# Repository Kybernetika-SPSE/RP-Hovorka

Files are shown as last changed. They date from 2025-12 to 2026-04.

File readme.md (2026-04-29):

# KYB Fotaoparát - Systém pro obsluhu kamery

## Zadání projektu
Cílem práce je návrh a realizace systému pro obsluhu
digitální kamery pomocí mikrokontroléru.

## Řešitelský tým
Vít Hovorka

## Vedoucí
Jiří Švihla

## Oponent
Pavel Jedlička

## Shrnutí projektu
Projekt „Fotaoparát" má za cíl navrhnout a realizovat řídicí systém pro digitální fotoaparát založený na mikrokontroléru ESP32‑P4. Práce kombinuje návrh hardware (schemata, PCB, periferie), mechanický návrh těla a vývoj firmware pro řízení kamery, paměti a uživatelského rozhraní.
## Fáze a plnění
## Termíny
| milník | termín |
| :--- | :--- |
| Nastudování dokumentací, návrh zapojení a design obalu| **30.12.2025** |
| Sestavení | **30.1.2026**  |
| Naprogramování operačního softwaru | **27.2. 2026** |
| Testování a tvora dokumentace | **30.03.2026** |
| Odevzdání ročníkové práce | **30.04.2026** |

[^1]: Změněno na základě požadavků

### Ganttův diagram postupu
```mermaid
gantt
    title Milníky projektu
    dateFormat  YYYY-MM-DD
    axisFormat  %d.%m.%Y
    section Studium a návrh
    Studovat dokumentace a návrh   :done, study, 2025-09-01, 2025-12-30
    section Sestavení prototypu
    Montáž prototypu               :build, 2026-01-01, 2026-01-30
    section Vývoj softwaru
    Implementace firmware          :dev, 2026-02-01, 2026-02-27
    section Testování a dokumentace
    Testování a tvorba dokumentace :test, 2026-03-01, 2026-03-30
    section Odevzdání a prezentace
    Finalizace a odevzdání         :deliver, 2026-04-01, 2026-04-30
```

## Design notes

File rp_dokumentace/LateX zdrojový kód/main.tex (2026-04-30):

\documentclass[12pt, a4paper, oneside]{report}             
\usepackage[czech]{babel}
\usepackage[utf8]{inputenc}  
\usepackage{graphicx} % balíček pro vkládání RASTROVÝCH grafických souborů (PNG apod.)
%\usepackage{epsfig} % balíčky pro vkládání VEKTOROVÝCH grafických souborů typu EPS
%\usepackage{float} % rozšířené možnosti umístění obrázků
%\usepackage{caption} % pro popisky obrázků, tabulek atd.
%\usepackage{tabularx} % rozšířené možnosti tabulek
%\usepackage{tabu} % jiný balík pro rozšířené možnosti tabulek
\usepackage{xcolor}
\usepackage{amsmath} % balíček pro pokročilou matematickou sazbu
\usepackage{pdfpages} % pro vkládání PDF souborů
%\usepackage{color} % pro možnost barevného textu
%\usepackage{fancybox} % umožňuje pokročilé rámečkování
%\usepackage{index} % nutno použít v případě tvorby rejstříku balíčkem makeindex
%\newindex{default}{idx}{ind}{Rejstřík} % zavádí rejstřík v případě použití balíku index
\usepackage{longtable}
\usepackage{array}
\usepackage[formats]{listings}  % Balíček pro sazbu zdrojových textů

\usepackage{anysize}
\marginsize{3.5cm}{1.5cm}{2.5cm}{3cm} % Nastavení okrajů (volitelné)

\usepackage{titlesec}  %přetypuje nadpisy všech úrovní na bezpatkové, tučné a dané velikosti

\titleformat{\chapter}[hang]{\sffamily\fontsize{16pt}{20pt}\bfseries}{\thechapter}{1em}{}
\titlespacing*{\chapter}{0pt}{20pt}{10pt}
\titleformat{\section}[hang]{\sffamily\fontsize{14pt}{16pt}\bfseries}{\thesection}{1em}{}
\titlespacing*{\section}{0pt}{20pt}{10pt}
\titleformat{\subsection}[hang]{\sffamily\fontsize{14pt}{18pt}\bfseries}{\thesubsection}{1em}{}
\titlespacing*{\subsection}{0pt}{20pt}{10pt}
\titleformat{\subsubsection}[hang]{\sffamily\fontsize{14pt}{18pt}\bfseries}{\thesubsubsection}{1em}{}
\titlespacing*{\subsubsection}{0pt}{20pt}{10pt}

\usepackage{setspace}
\setstretch{1.3} % Nastaví 1,3násobné řádkování

\frenchspacing % za větou bude mezislovní mezera (v anglických textech je mezera za větou delší)
\widowpenalty=1000 % "síla" zákazu vdov (= jeden řádek odstavce na konci stránky)
\clubpenalty=1000 % "síla" zákazu sirotků (= jeden řádek/slovo odstavce samostatně na začátku stránky)
\brokenpenalty=1000 % "síla" zákazu zlomu stránky za řádkem, který má na konci rozdělené slovo

\pagenumbering{arabic} % číslování stránek arabskými číslicemi
\usepackage{fancyhdr} % Načte balíček pro pokročilé úpravy záhlaví a zápatí.
\pagestyle{fancy} % Nastavení stylu stránek na 'fancy'
\fancyhf{} % Vymazání aktuálního nastavení záhlaví a zápatí
\fancyfoot[R]{\thepage} % Nastavení čísel stránek vpravo dole (R - right)
\renewcommand{\headrulewidth}{0pt}
\renewcommand{\footrulewidth}{0pt}
\fancypagestyle{plain}{%
  \fancyhf{}
  \fancyfoot[R]{\thepage}
  \renewcommand{\headrulewidth}{0pt}
  \renewcommand{\footrulewidth}{0pt}
}
\parindent=0pt % odsazení 1. řádku odstavce
\parskip=12pt   % mezera mezi odstavci
\usepackage[breaklinks=true,hypertexnames=false]{hyperref}  % Balíček 'hyperref' pro sazbu hypertextových odkazů. Hypertextové odkazy mohou obsahovat zalomení řádku. Názvy hypertext. odkazů budou tvořeny nezávisle na názvech TeXu.
\hypersetup{ % popisky v pdf souboru
  pdftitle={Název studentské práce},    	% Pole 'Document Title'
  pdfauthor={Autor studentské práce},   	% Pole 'Author'
  pdfsubject={Typ práce}, 						  	% Pole 'Subject'
  pdfkeywords={Klíčová slova}           	% Pole 'Keywords'
}

%%%%%%%%%%%%%%%%%%%%%%%%%%%%%%%%%%%%%%%%%%%%%%%%%%%%%%%%%%%%%%%%%%%%%%%
%%%%%%%%%%%       Začátek dokumentu               %%%%%%%%%%%%%%%%%%%%%
%%%%%%%%%%%%%%%%%%%%%%%%%%%%%%%%%%%%%%%%%%%%%%%%%%%%%%%%%%%%%%%%%%%%%%%
\begin{document}
\thispagestyle{empty} %vypnutí číslování stránek

%% TITULNÍ STRANA %%%%%%%%%%%%%%%%%%%%%%%%%%%%%%%%%%%%%%%%%%%%%%%%%%%%%%%%%%%%%%
\begin{center}
  \begin{minipage}{3cm}
    
  \end{minipage}
  \hfill
  \begin{minipage}{0.7\textwidth}
    \centering
    {\Large Vyšší odborná škola\\
    a Střední průmyslová škola elektrotechnická\\
    Plzeň, Koterovská 85\\ }
  \end{minipage}
  
  \vspace{2cm}
  %% VYBERTE TYP PRÁCE %%%%%%%%%%%%%%%%%%%%%%%%%%
  %%{\Large \textbf{DLOUHODOBÁ MATURITNÍ PRÁCE S~OBHAJOBOU}\\ }
  {\Large \textbf{ROČNÍKOVÁ PRÁCE}\\ }
  %%%%%%%%%%%%%%%%%%%%%%%%%%%%%%%%%%%%%%%%%%%%%%%
  
  \vspace{2.5cm}
  {\large Téma: \\ }
  \vspace{0.25cm}
  %% PŘEPIŠTE NÁZEV PRÁCE %%%%%%%%%%%%%%%%%%%%%%%%%%%
  {\LARGE \textbf{Fotaoparát - Systém pro obsluhu kamery}}  
  %%%%%%%%%%%%%%%%%%%%%%%%%%%%%%%%%%%
  
  \vfill
\end{center}
\begin{tabular}{{p{4.5cm} p{12cm}}}
  {\Large \textbf{Autor práce:}} & \Large{Vít Hovorka}\\
  {\Large \textbf{Třída:}} & \Large{3.L}\\ 
  {\Large \textbf{Vedoucí práce:}} & \Large{Jiří Švihla} \\ 
  {\Large \textbf{Dne:}} & \Large{30.4.2026} \\ 
  {\Large \textbf{Hodnocení:}} &  \\ 
\end{tabular}
%% Vložení zadání %%%%%%%%%%%%%%%%%%%%%%%%%%%%%%%%%%%%%%%%%%%%%%%%%%%%%%%%%%%%
\newpage
\thispagestyle{empty}
\includepdf{pdf/Zadani-Hovorka.pdf}% název souboru nesmí obsahovat mezery!
%% NEBO lze vytvořit prázdný list příkazem ze šablony

%\newpage   % při dvojstranném tisku se přidá prázdná stránka

%%%%%%%%%%%% Anotace a poděkování %%%%%%%%%%%%%%%%%%%%%%%%%%%%%%%%%%%%%%%%%%%%%%
\newpage
\chapter*{Anotace} \indent
\thispagestyle{empty}

Tato ročníková práce se zabývá návrhem a prototypovou realizací řídicího systému pro mikrokontrolérovou kameru založenou na platformě \texttt{ESP32-P4}. Práce pokrývá výběr a návrh součástek, konstrukci a rozvržení desky plošných spojů, návrh napájecích větví a rozhraní pro kameru, displej a objektiv, a implementaci základního firmware pro pořizování, zpracování a ukládání snímků. Pozornost je věnována navrhování vysokorychlostních rozhraní (QSPI, MIPI/CSI), integritě signálu a spolehlivému napájení včetně řízení objektivu Canon EF. Výstupem je dokumentovaný návrh desky, zapojení a ukázkový firmware umožňující základní oživení a testování hardwaru.
\vfill

Prohlašuji, že jsem tuto práci vypracoval samostatně a použil literárních pramenů a~\mbox{informací}, které cituji a uvádím v seznamu použité literatury a zdrojů informací.

Prohlašuji, že jsem nástroje UI využil v souladu s principy akademické integrity a že na využití těchto nástrojů v práci vhodným způsobem odkazuji.

Souhlasím s využitím mé práce učiteli VOŠ a SPŠE Plzeň k výuce.

\vspace{1cm}

V Plzni dne 30. 4. 2026 \hfill Podpis: ..........................

%%%%%%%%%%%% Obsah práce ... je generován AUTOMATICKY %%%%%%%%%%%%
\newpage
\tableofcontents
\thispagestyle{empty}

%%%%%%%%%%%% Seznam zkratek %%%%%%%%%%%%%%%%%%%%%%%%%%%%%%%%%%%%%%%%%%%%%%
\newpage
\chapter*{Seznam zkratek}
\addcontentsline{toc}{chapter}{Seznam zkratek}
\begingroup
\setlength{\tabcolsep}{6pt}
\renewcommand{\arraystretch}{1.4}
\begin{longtable}{>{\raggedright\arraybackslash}p{2.6cm} >{\raggedright\arraybackslash}p{6.3cm} >{\raggedright\arraybackslash}p{5.2cm}}

\textbf{Zkratka} & \textbf{Anglicky} & \textbf{Česky} \\
\endfirsthead
\textbf{Zkratka} & \textbf{Anglicky} & \textbf{Česky} \\
\endhead
ADC & Analog-to-digital converter & analogově-digitální převodník \\
AF & Autofocus & automatické ostření \\
CSI & Camera Serial Interface & kamerové sériové rozhraní \\
DRC & Design Rules Check & kontrola pravidel návrhu \\
DSI & Display Serial Interface & zobrazovací sériové rozhraní \\
DTR & Double Transfer Rate & přenos na obou hranách hodinového signálu \\
ERC & Electrical Rules Check & kontrola elektrických pravidel \\
ESP-IDF & Espressif IoT Development Framework & vývojový rámec pro čipy ESP od společnosti Espressif \\
ESD & Electrostatic discharge & elektrostatický výboj \\
GPIO & General-purpose input/output & univerzální vstup/výstup \\
HP & High Power & vysoký výkon\\
I2C & Inter-Integrated Circuit & dvouvodičová sériová sběrnice \\
NOR & NOR flash & typ nevolatilní flash paměti \\
ISO & International Organization for Standardization & citlivost podle fotografické terminologie \\
LP & Low Power & Nízký výkon\\
MILC & Mirrorless interchangeable-lens camera & bezzrcadlový fotoaparát s výměnnými objektivy \\
MCU & Microcontroller unit & mikrokontrolér \\
MIPI & Mobile Industry Processor Interface & standard mobilního rozhraní pro periférie \\
PCB & Printed circuit board & plošný spoj \\
QSPI & Quad Serial Peripheral Interface & čtyřlinkové sériové periferní rozhraní \\
SD & Secure Digital & paměťová karta Secure Digital \\
SPI & Serial Peripheral Interface & sériové periferní rozhraní \\
USB & Universal Serial Bus & univerzální sériová sběrnice \\
\caption{Seznam zkratek}
\end{longtable}
\endgroup

%--------------------------------------------------------
%|         Zde začíná SAMOTNÁ PRÁCE (text)              |
%--------------------------------------------------------
\newpage

\chapter*{Úvod}
\addcontentsline{toc}{chapter}{Úvod}
Už asi dva roky se pokouším být aktivním fotografem, s tím že jsem začínal na analogovém fotoaparátu a snažil se naučit souvislosti mezi hodnotami expozičního času, clony a ISO. Vždy mě bavilo zkoumat do hloubky jak a proč takové věci fungují a hledat si svou vlastní „cestu trním"~kde metodou pokus omyl šlechtím své dovednosti. Proto mi sestavení svého vlastního fotoaparátu přišlo jako dobrá cesta jak naučit nejen elektrotechniku a programovaní, ale i jak poznat technologii digitální fotografie do hloubky.

\chapter{Cíle a požadavky}
\section{Požadavky na mechanické konstrukční řešení}
Tento projekt by měl v ideálním případě alespoň připomínat MILC kameru. Výrobek, dále označovaný jako fotaoparát, by měl být tedy:
\begin{itemize}
    \item svými rozměry a tvarem podobný dnešním digitálním fotoaparátům,
    \item jednoduše nositelný a ovladatelný,
    \item kompatibilní s objektivy řady Canon EF. Toto rozhodnutí má jak objektivní tak i subjektivní opodstatnění. Subjektivní rovinou zde je fakt že už několika disponuji. V objektivní rovině je fakt že komunikační protokoly jsou už komunitou zmapovány (Magic Lantern\footnote{Magic Lantern firmware, dostupné z: https://www.magiclantern.fm}).
\end{itemize}
\section{Požadavky na elektrotechnické řešení}
Součástí vývoje projektu je i návrh základní desky pro mikročip \texttt{ESP32-P4} a jeho periférií. Základní deska tedy:
\begin{itemize}
    \item bude mít na starost napájení jak hlavního čipu, tak veškerých periférií. Napájení bude zajištěno jedním akumulátorem,
    \item obstará všechny konektory pro zapojení periférií. Bude tedy možné případné periferie vyměnit za lepší za předpokladu kompatibility z hlediska počtu vývodů (pinů) na konektoru a prostoru v těle Fotaoparátu,
    \item bude jednoduše programovatelná pomocí USB-C vstupu. Fotaoparát bude open-source výrobek podporující a vyzývající k úpravám podle uživatele, kde open-source znamená výrobek s veřejně dostupným zdrojovým kódem,
    \item bude navrhována s ohledem na elektromagnetické rušení signálů a možnosti ztráty dat kvůli délkové asymetrii cest a design se tedy bude snažit toto rušení a ztrátu minimalizovat.
    \item bude navrhována s ohledem na prostor a konstrukční provedení těla fotaoparátu. Bude tedy dostatečně skladná a vývody na periferie budou vhodně umístěny.
\end{itemize}
\section{Požadavky na softwarové řešení}
Výrobek bude nakonec oživen firmwarem vlastní výroby. Software bude mít pevně dané funkce jako např. nastavení hodnot ISO, clony a rychlosti závěrky. Zároveň by měl mít jednoduše přizpůsobitelné uživatelské rozhraní a možnost přidávat další uživatelské funkce.
\chapter{Použité nástroje}
\section{KiCAD 9.0}
Pro návrh samotné základní desky Fotaoparátu jsem zvolil software KiCAD 9.0. Jedná se o open-source software určený pro návrh elektronických schémat a plošných spojů. Samotný program totiž ukrývá tři hlavní podprogramy: Schematic editor, PCB editor a Gerber viewer.

Schematic editor umožňuje uživateli nakreslit elektrické schéma a dokonce i do jisté míry simulovat jednoduché elektrické obvody. Dále KiCAD hned po instalaci disponuje velmi rozmanitou knihovnou součástek, pouzder a datasheetů (technická dokumentace jednotlivých součástek). Stačí si tedy součástky vybrat, pomocí nástroje „kreslit vodiče" je propojit, nebo pomocí nástroje „označení sítě" jim přiřadit stejnou síť. Je zde také možnost využít nástroj ERC (electrical rules check - kontrola elektrických pravidel), ten slouží k odhalení chyb v zapojení vývodů.
\begin{figure}
    \centering
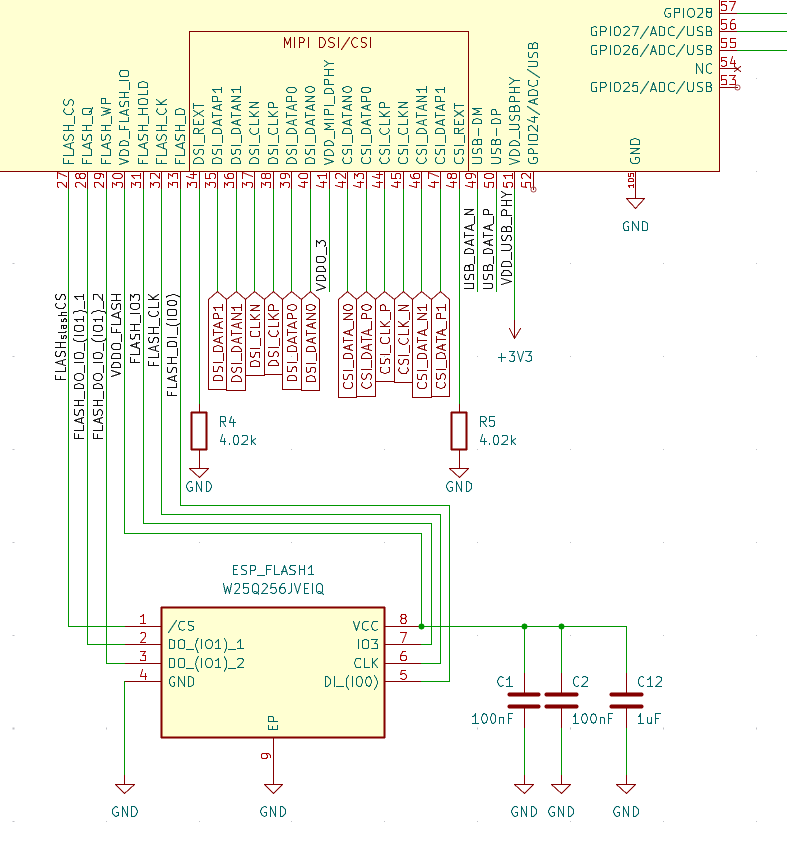
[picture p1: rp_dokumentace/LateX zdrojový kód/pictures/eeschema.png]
    
    \caption{Ukázka programu schematic editor \textit{Zdroj: [vlastní]}}
    \label{fig:schematicsmrdito}
\end{figure}

PCB editor slouží k přímému návrhu plošného spoje. Obvyklý postup při práci s KiCADem je nakreslení elektronického schématu, přiřazení pouzder, načtení těchto dat do PCB editoru a zde rozmístit součástky a routovat cesty spojů. Disponuje také možností nastavení konstrukčních vlastností desky (počet vrstev, tloušťka jednotlivých vrstev, základní tloušťka spojů, velikost prokovených otvorů, minimální požadovaná vzdálenost mezi cestami...).
Pro kontrolu designových chyb na desce pak slouží nástroj DRC (design rules check - kontrola pravidel designu).
\begin{figure}
    \centering
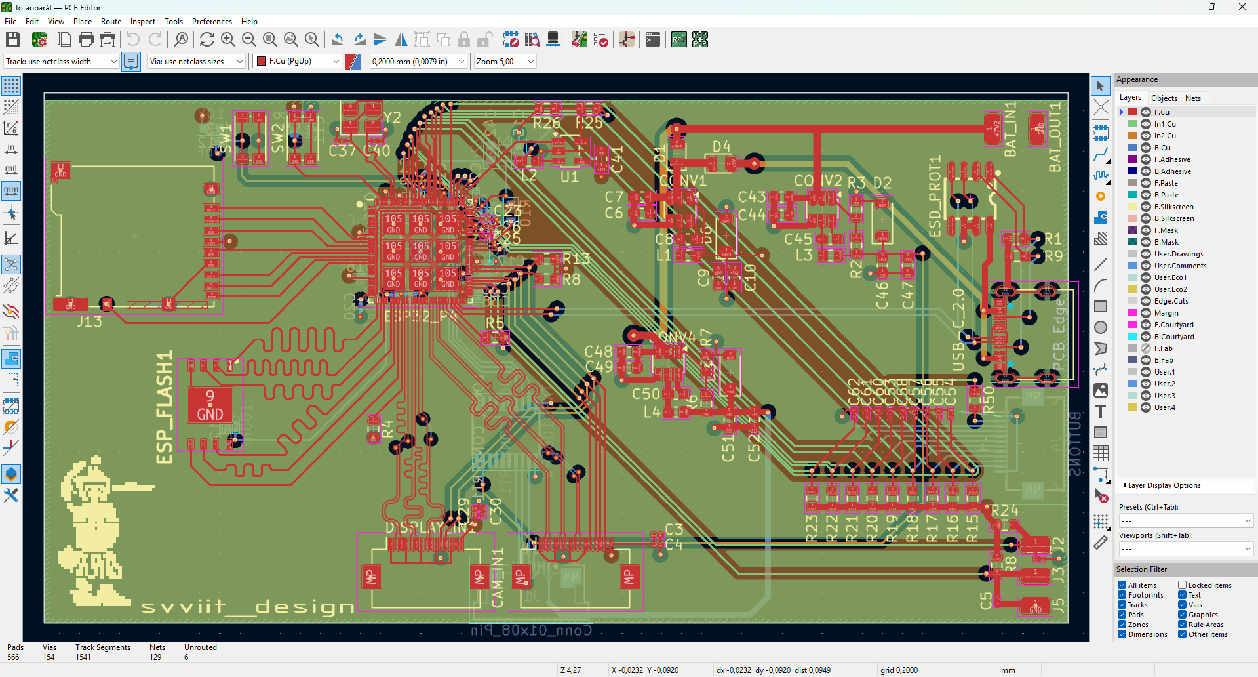
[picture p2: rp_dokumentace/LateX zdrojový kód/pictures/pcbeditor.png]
    
    \caption{Ukázka programu PCB editor \textit{Zdroj: [vlastní]}}
    \label{fig:pcbsmrdito}
\end{figure}

Jako poslední podstatná část programu KiCAD je gerber viewer. Ten slouží k exportu geberových dat pro výrobu desky.

\section{Visual Studio Code}
Visual Studio Code (zkráceně VS Code nebo VS) je bezplatné moderní vývojové prostředí. Díky velkému množství rozšíření, která lze instalovat přímo v programu, a podpoře hlavních operačních systémů (Windows, Linux a macOS) si získalo značnou oblibu mezi programátory.

\begin{figure}
    \centering
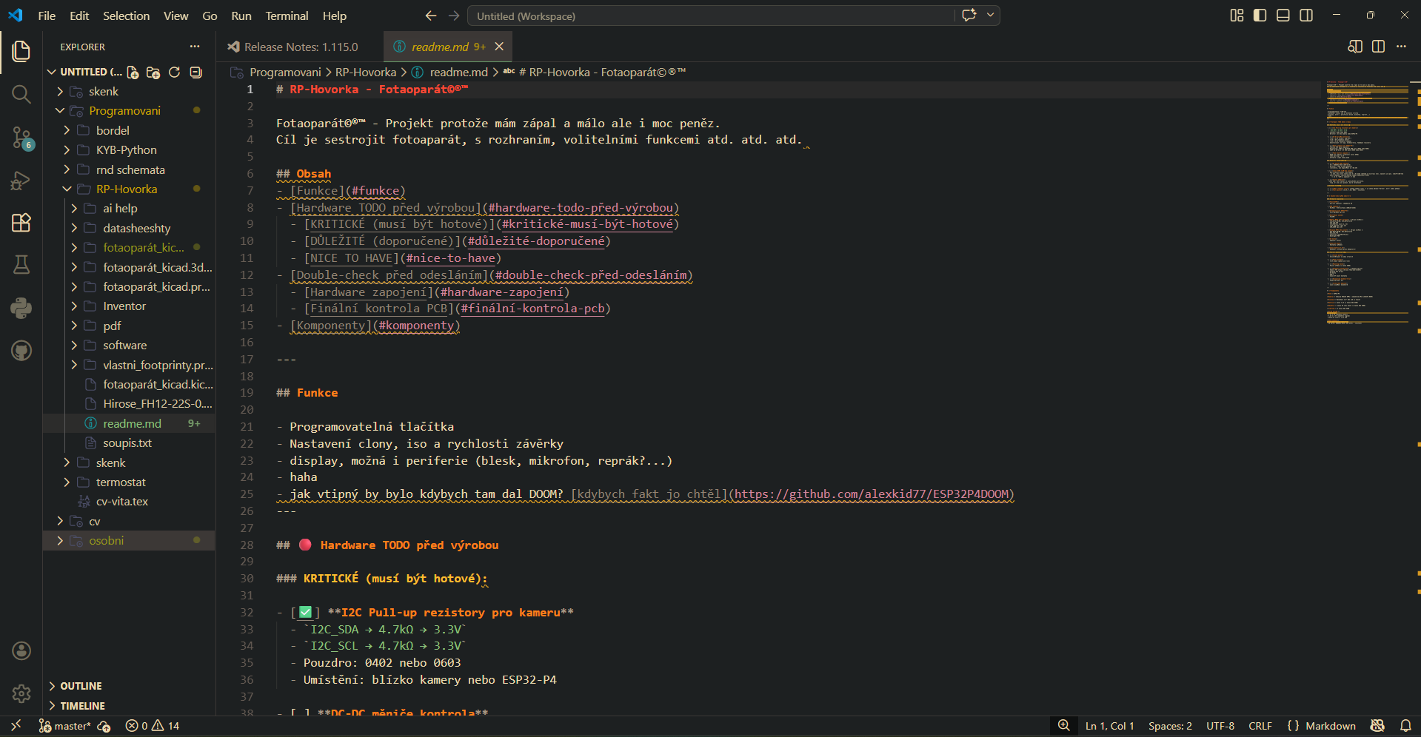
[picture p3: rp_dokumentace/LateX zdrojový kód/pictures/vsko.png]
    
    \caption{Ukázka programu Visual Studio Code \textit{[Zdroj: Vlastní]}}
    \label{fig:vsko}
\end{figure}

Mezi jeho hlavní funkce patří podpora verzovacích systémů jako např. Git, zvýraznění syntaxe (např. závorkové páry), našeptávání kódu, integrovaný terminál a debugger.

V mé práci jsem VS používal zejména pro jednoduché commitování. Dále jsem v něm používal umělou inteligenci pomocí které jsem napsal část firmwaru. 
\chapter{Vybrané komponenty}
\section{MCU}
Kvůli vysoké výpočetní náročnosti zpracování dat, která představuje jediný snímek o rozlišení 8 Mpx, bylo nutné zvolit jeden z nejvýkonnějších mikrokontrolérů dostupných v době realizace projektu — \texttt{ESP32-P4}. Jedná se o moderní MCU navržené s důrazem na vysoký výpočetní výkon, multimediální zpracování a efektivní práci s periferiemi\cite{esp32p4_ds}.

\texttt{ESP32-P4} je vybaven vícejádrovou architekturou, která umožňuje paralelní zpracování úloh. V tomto MCU se nacházzejí dva procesory -- jednojádrový a pomalejší LP a dvoujádrový rychlejší HP. Oba procesory jsou postaveny na 32-bitové architektuře. 

Low power procesor má nejvyšší rychlost taktu 40 MHz. Je narvžený pro zastoupení HP obvodů při sleep režimu, jelikož i při deep--sleep reimu je tento procesor a jeho pamět aktivní. Zároveň má však přístup i do HP paměti. 

High Power procesor má nejvyšší rychlost taktu 360 Mhz Dále disponuje hardwarovou akcelerací pro vybrané operace. Jeho paměti zahrnují:
\begin{itemize}
    \item 16 MB SRAM
    \item 128 kB ROM pro HP obvody
    \item 768 kB HP L2mem
    \item 16 kB ROM pro LP obvody
    \item 8 kB systémové SPM
    \item Více vyoskorychlostními externími paměťovými rozhraními
    \item Dvouúrovňovou vysokorychlotní cache
\end{itemize} 

Čip také zahruje podporou vysokorychlostních rozhraní, jako např. CSI, DSI a QSPI, která umožňují efektivní přenos velkého množství dat.

\section{Flash paměť}
Další důležitou součástí návrhu je externí flash paměť. Mikrokontrolér \texttt{ESP32-P4} totiž nedisponuje dostatečně velkou interní pamětí pro uložení uživatelského kódu, a proto je nutné využít externí úložiště.

V tomto projektu byla zvolena paměť \texttt{W25Q256JV-DTR} od společnosti Winbond. Jedná se o sériovou NOR flash paměť s kapacitou 256 Mbit (32 MB), která slouží pro ukládání firmwaru, konfiguračních dat a případně i dočasných obrazových dat.

Paměť komunikuje s mikrokontrolérem prostřednictvím rozhraní SPI, respektive jeho rozšířené varianty QSPI, která umožňuje paralelní přenos dat po více datových linkách. Díky tomu lze dosáhnout výrazně vyšších přenosových rychlostí oproti standardnímu SPI, což je zásadní zejména při práci s obrazovými snímky.

Označení DTR (Double Transfer Rate) znamená, že data jsou přenášena na obou hranách hodinového signálu, čímž dochází k efektivnímu zdvojnásobení propustnosti bez nutnosti zvyšování pracovní frekvence. Tato vlastnost přispívá ke zvýšení celkového výkonu systému při čtení i zápisu dat.

Paměť je organizována do sektorů, což umožňuje efektivní mazání a zápis po blocích. Zároveň podporuje mechanismy ochrany vybraných oblastí proti zápisu, což je výhodné například pro zabezpečení kritických částí firmwaru.
\section{Kamerový modul}
Další klíčovou komponentou je kamerový modul Arducam \texttt{IMX219} s rozlišením 8 Mpx. Tento modul byl zvolen nejen s ohledem na příznivý poměr ceny a výkonu, ale také díky své kompatibilitě a vhodnosti pro použití s mikrokontrolérem \texttt{ESP32-P4}.
\begin{figure}
    \centering
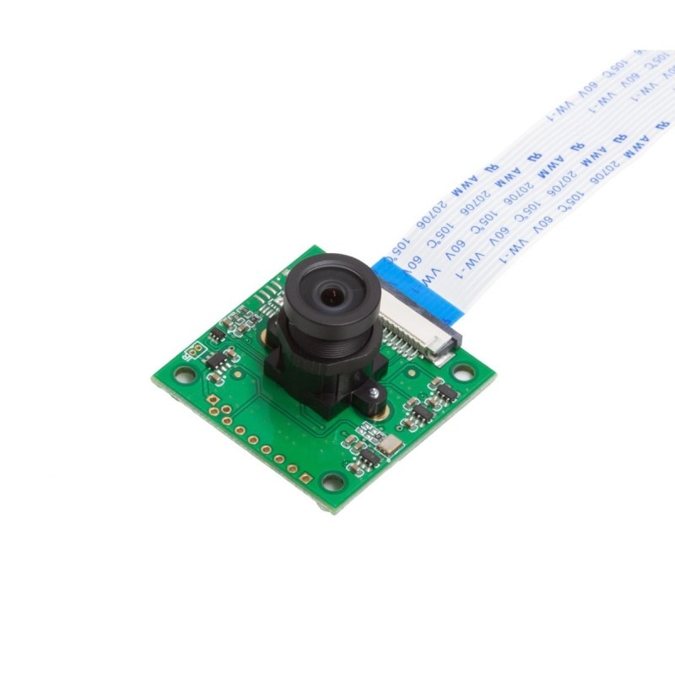
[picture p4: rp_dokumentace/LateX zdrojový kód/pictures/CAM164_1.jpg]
    
    \caption{Vybraný kamerový modul Arducam IMX219 \textit{[Zdroj: rpishop.cz]}}
    \label{fig:arducam}
\end{figure}

Zde je klíčové rozhraní DSI/CSI, které umožňuje vysokorychlostní přenos obrazových dat mezi kamerovým modulem, případně displejem, a samotným mikrokontrolérem. Využití tohoto rozhraní je zásadní zejména kvůli vyšším přenosovým rychlostem. Pokud bychom zvolili jiný postup, vyžadovalo by to desítky GPIO pinů, které prostě na MCU nemáme, a navíc by to bylo velmi náročné na synchronizaci a zpracování dat.

Samotný snímač \texttt{IMX219} nabízí dostatečné rozlišení pro zamýšlenou aplikaci a zároveň podporuje různé režimy výstupu, což umožňuje optimalizovat kompromis mezi kvalitou obrazu a objemem přenášených dat. V jednoduchosti můžeme poté přímo ve Fotaoparátu nastavovat rozlišení výstupního snímku.

Výhodou modulu Arducam je také jeho široká podpora a dostupná dokumentace, což usnadňuje jeho integraci do návrhu jak na hardwarové, tak i softwarové úrovni.

\section{Display}
Pro zobrazovací jednotku jsem zvolil 2,8"~LCD modul od společnosti Waveshare, a to především díky jeho DSI rozhraní, které je podporováno mikrokontrolérem ESP32-P4. Toto rozhraní umožňuje efektivní a rychlou komunikaci mezi řídicí jednotkou a displejem.
\begin{figure}
    \centering
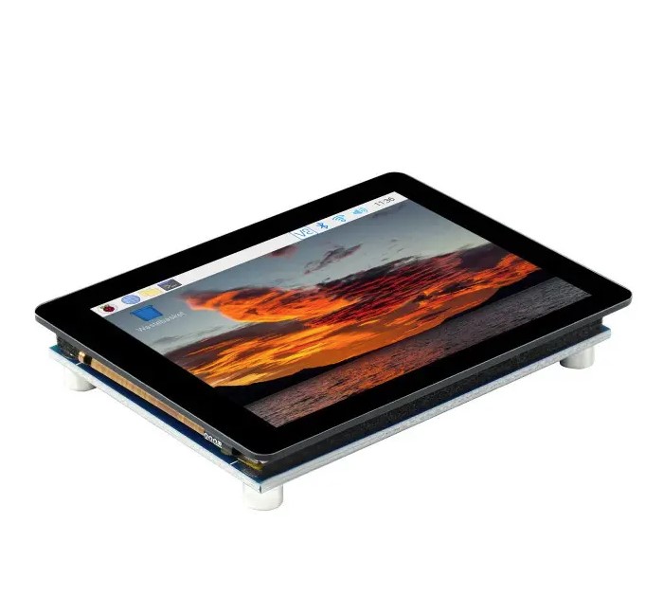
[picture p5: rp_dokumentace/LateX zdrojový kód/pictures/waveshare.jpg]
    
    \caption{Vybraný 2,8"~LCD modul od společnosti Waveshare \textit{[Zdroj: rpishop.cz]}}
    \label{fig:waveshare}
\end{figure}

Dalším důvodem výběru tohoto konkrétního displeje byla jeho kompatibilita s mechanickou konstrukcí zařízení. Pro zjednodušení návrhu jsem se rozhodl využít tělo a vybrané periferie fotoaparátu Canon 550D. Pro účely této kapitoly postačí uvést, že původní displej z modelu 550D není vhodné použít, jelikož k němu není veřejně dostupná dostatečná technická dokumentace. Zároveň má však velmi podobné rozměry jako zvolený Waveshare modul, což usnadňuje jeho náhradu bez nutnosti zásadních mechanických úprav.

\section{Konektor pro SD kartu}

Pro ukládání dat bude použit konektor pro SD kartu, což představuje standardní řešení úložiště u digitálních fotoaparátů. SD karty jsou kompaktní, široce rozšířené a snadno dostupné externí médium, které nabízí dostatečné přenosové rychlosti pro zamýšlenou aplikaci. Oproti tomu běžné USB flash disky nejsou pro tento typ zařízení tak vhodné, a to jak z hlediska rozměrů, tak i způsobu připojení.

Alternativou by mohlo být použití paměťových karet typu CompactFlash. Tyto karty sice teoreticky dosahují vyšších přenosových rychlostí, mimo jiné díky většímu počtu pinů, avšak jejich nevýhodou je vyšší pořizovací cena. Dalším omezením je skutečnost, že konektory pro CompactFlash karty jsou v současnosti obtížně dostupné a často vyžadují použití redukce. Z těchto důvodů nebylo toto řešení dále uvažováno.
\section{Konektor pro komunikaci s počítačem.}
Pro nahrávání firmwaru je na desce navržen USB-C konektor, který slouží nejen pro samotné programování mikrokontroléru, ale také pro jeho napájení během vývoje a testování. Toto řešení výrazně zjednodušuje proces nasazení firmwaru, protože není nutné využívat externí programátor.
\chapter{Podrobné zapojení na desce}
\section{MCU}
Středem celého návrhu je mikrokontrolér ESP32-P4, osazený jako hlavní výpočetní a řídicí prvek.
\begin{figure}
    \centering
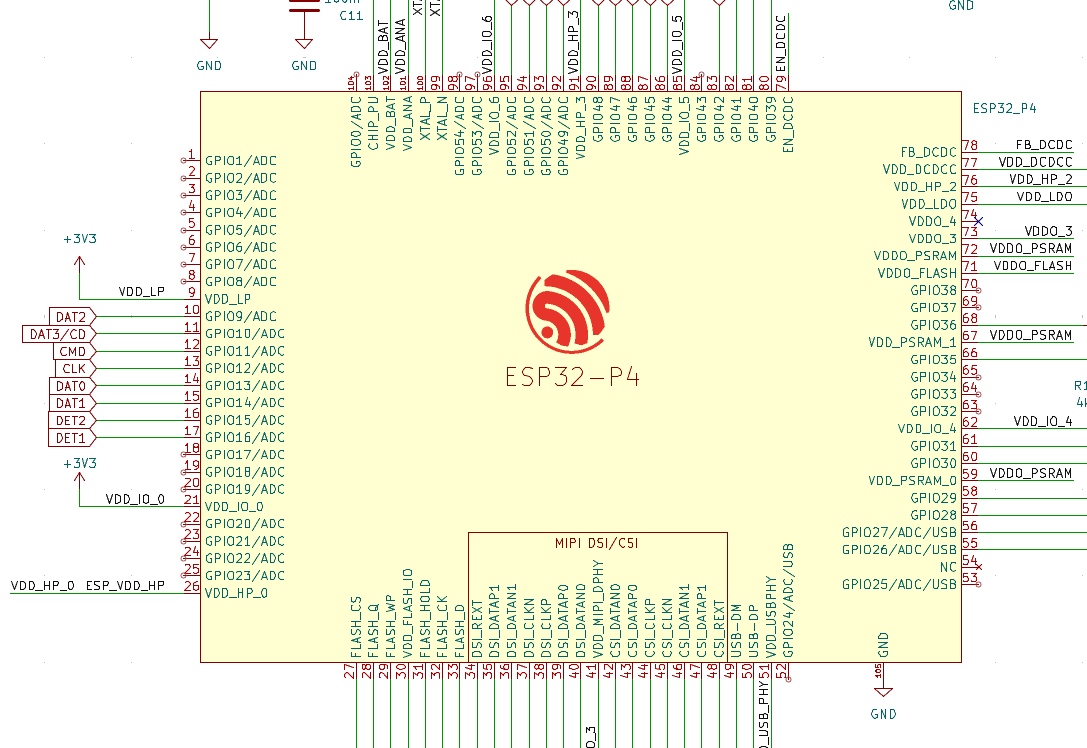
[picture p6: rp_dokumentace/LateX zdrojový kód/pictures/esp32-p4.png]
    
    \caption{ESP32-P4 v eschématu \textit{[Zdroj: Vlastní]}}
    \label{fig:esp32p4}
\end{figure}

Sám o sobě ale být použit nemůže. Pro jeho ideální funkci je potřeba externí flash pamět, externí krystal a externí buck converter na 1,1 V pro napájení high power pinů.

\subsection{Napájení interní SRAM paměti}
Napájení interních paměťových a pomocných bloků MCU je řešeno samostatně.\cite{local_kicad,esp32p4_trm}.

Pro napájení HP pinů je použit buck converter \texttt{TLV62569DBV}, který je nastaven na výstupní napětí 1,1 V, viz obrázek \ref{fig:hpbuck}.

\subsection{BOOT strapping a I2C}
\begin{figure}
    \centering
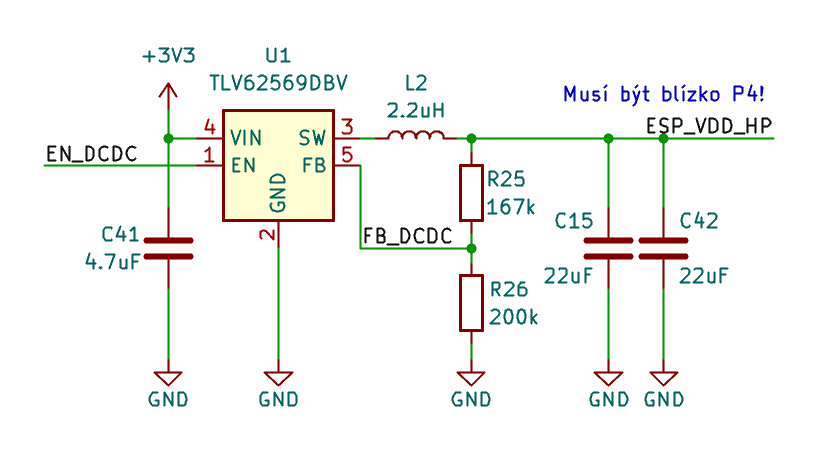
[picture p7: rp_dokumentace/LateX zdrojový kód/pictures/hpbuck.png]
    
    \caption{Schména zapojení měniče pro napájení HP pinů \textit{[Zdroj: Vlastní]}}
    \label{fig:hpbuck}
\end{figure}
Programování zařízení je v tomto projektu navrženo pouze přes USB. Mikrokontrolér sice obecně umožňuje i programování přes UART, tato možnost však v daném návrhu není využita. Pro vstup do programovacího režimu je osazeno tlačítko SW1, připojené k GPIO 35.  Strapping piny se čtou během bootování a určují spouštěcí režim MCU. Tlačítko S1 slouží k aktivaci Joint Download Boot módu pro nahrávání firmwaru — při jeho stisku během startu se MCU spustí v režimu, který umožňuje download nového kódu přes USB. Podrobněji jsou bootovací režimy a jejich konfigurace strapping pinů uvedeny v tabulce~\ref{tab:boot_modes}.

\begin{table}[h]
\centering
\begin{tabular}{|l|c|c|c|c|}
\hline
\textbf{Boot Mode} & \textbf{GPIO35} & \textbf{GPIO36} & \textbf{GPIO37} & \textbf{GPIO38} \\
\hline
SPI Boot mode (default)\textsuperscript{1} & 1 & x & x & x \\
\hline
Joint Download Boot mode\textsuperscript{2} & 0 & 1 & x & x \\
\hline
SPI Download Boot mode\textsuperscript{3} & 0 & 0 & 0 & 1 \\
\hline
Invalid Combination\textsuperscript{4} & 0 & 0 & 0 & 0 \\
\hline
\end{tabular}
\caption{BOOT režimy dle kombinace strapping pinů ESP32-P4 \textit{[Zdroj: \cite{esp32p4_trm}]}}
\label{tab:boot_modes}
\end{table}
\begin{figure}
    \centering
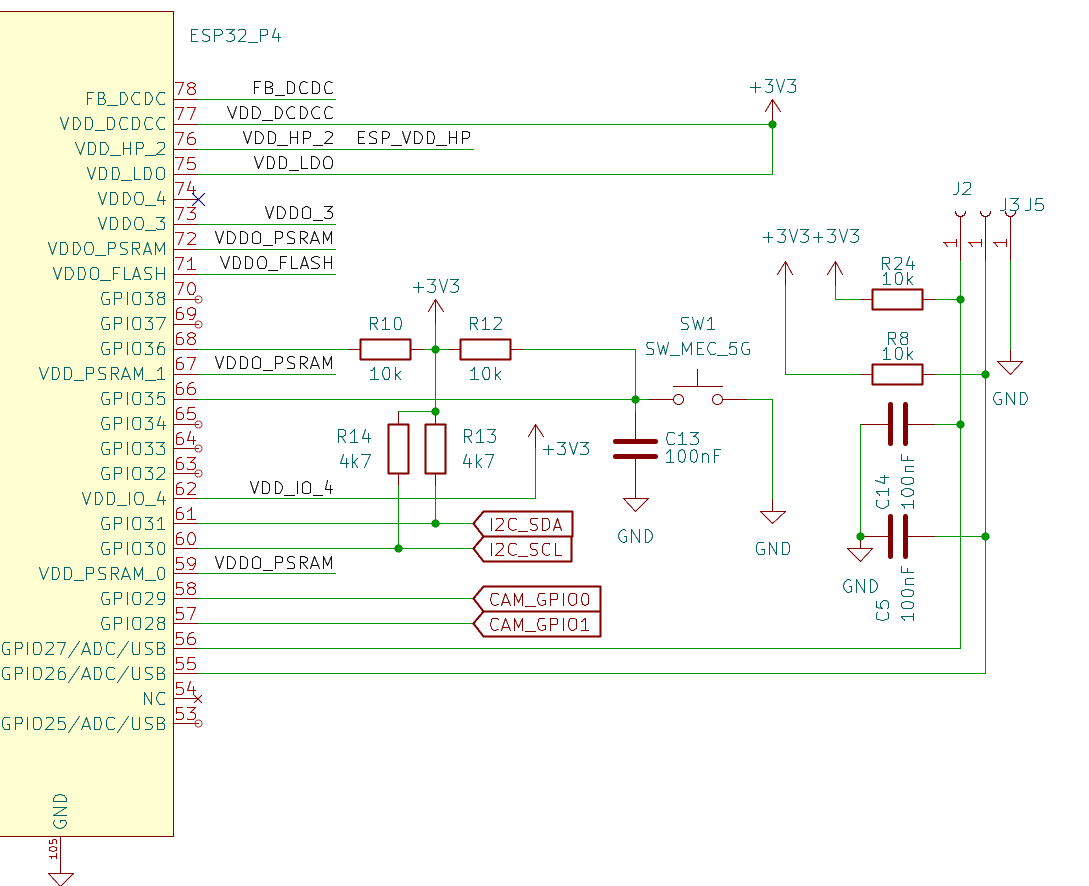
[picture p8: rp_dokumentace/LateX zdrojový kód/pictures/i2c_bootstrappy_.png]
    
    \caption{Zapojení kolem ESP32-P4 popsané v této sekci: I2C pull-upy, reset a startovací vazby. \textit{[Zdroj: Vlastní]}}
    \label{fig:i2c_bootstrappy}
\end{figure}

Na obrázku~\ref{fig:i2c_bootstrappy} je zachycena pravá část MCU, kde se nachází BOOT strapping piny (GPIO 35--38)~\cite{esp32p4_trm}, interní regulátor pro napájení Flash a SRAM pamětí (\texttt{VDD\_LDO}).

Dále je na obrázku~\ref{fig:i2c_bootstrappy} zachyceno I2C rozhraní, připojené k pinům GPIO 30 a 31. Kvůli designu samotné sběrnice, kde zařízení pouze „tahá"~napětí na logickou nulu, jsou zde osazeny pull-up rezistory \texttt{R14} a \texttt{R15} (oba 4,7 k$\Omega$).

\subsection{Externí krystal}
Hodinový systém je doplněn externím 40MHz krystalem a dvojicí zátěžových kondenzátorů podle doporučení výrobce\cite{local_kicad,esp32p4_ds}. Tato část má přímý vliv na stabilní start systému i na přesnost časování vysokorychlostních periferií. Bez tohoto krystalu by kamera nemohla spolehlivě fungovat, protože by nebylo možné zajistit stabilní taktování pro zpracování obrazových dat.
\begin{figure}
    \centering
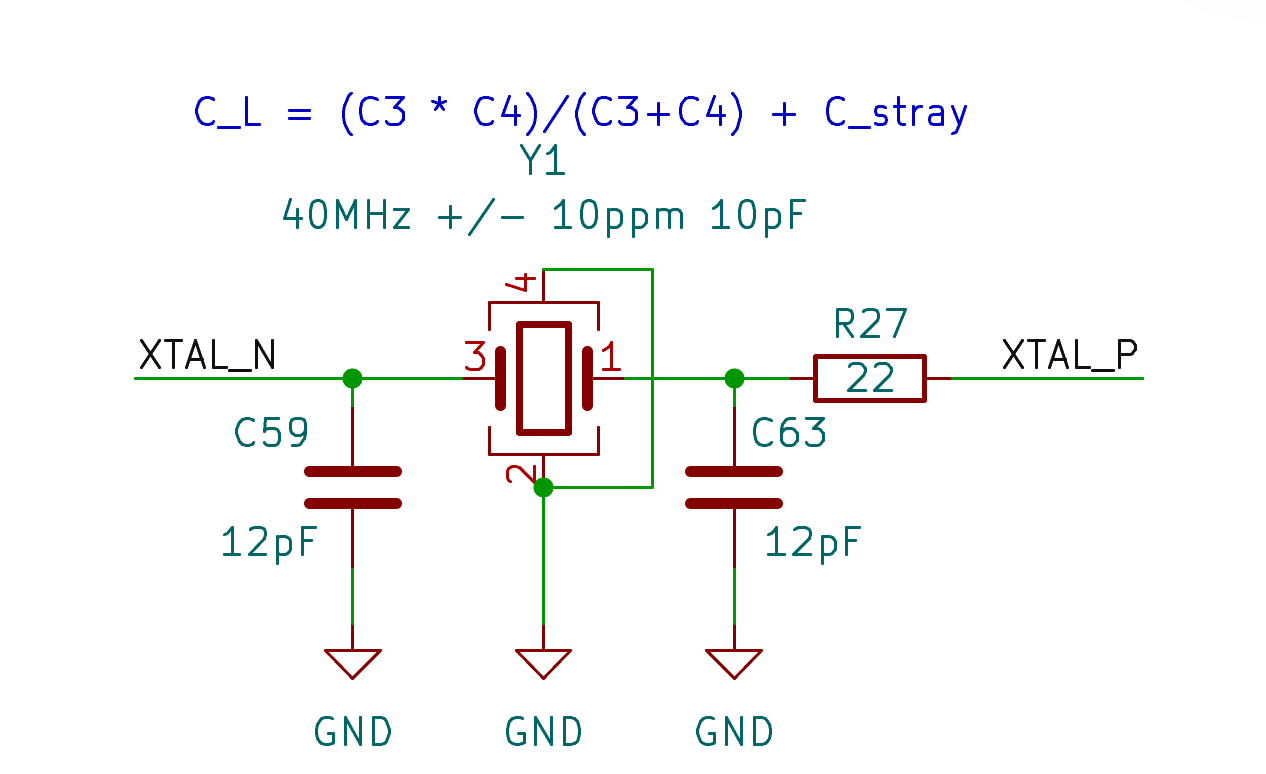
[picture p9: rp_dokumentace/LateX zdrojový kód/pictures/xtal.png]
    
    \caption{Zapojení externího krystalu v eschématu. \textit{[Zdroj: Vlastní]}}
    \label{fig:xtal}
\end{figure}
Na obrázku~\ref{fig:xtal} je znázorněno zapojení 40MHz krystalu Y1 a jeho podpůrných součástek. Kondenzátory C59 a C63 mají hodnotu 12 pF anastavují správnou zátěž a stabilitu oscilátoru. Sériový odpor R27 o hodnotě 22~$\Omega$ slouží k tlumení kmitů a pomáhá omezit rušení.
Krysatal by měl výt osazen ve vzdálenosti alespoň 4,5 mm od MCU\cite{esp32p4_trm}, aby se zabránilo rušení.

Podrobnější informace o doporučeném zapojení napájecích domén a startovacích podmínkách uvádí datasheet a technický referenční manuál výrobce\cite{esp32p4_trm,esp32p4_ds}.

\section{Napájení periférií}
Napájecí část je navržena pro provoz z jednoho akumulátoru 7,2 V a je rozdělena do několika samostatných větví podle typu zátěže\cite{local_readme}. Ve schématu jsou osazeny měniče CONV1 (\texttt{AP63203WU}, pevný výstup 3,3 V), CONV2 (\texttt{AP63200WU}, nastavený na 5,5 V pro komunikaci s objektivem) a CONV4 (\texttt{AP63200WU}, nastavený na 6 V pro obsluhu servo motorů v objektivu)\cite{ap63200,local_kicad}.

Měnič CONV1 s obvodem \texttt{AP63203WU} vytváří hlavní větev 3,3 V. Na jeho vstupu jsou oddělovací diody D1 a D4, které umožňují napájení jak z větve +7V2 z akumulátoru, tak z USB +5V. Na vstupu jsou také kondenzátory C6 (100 nF) a C7 (10 $\mu$F), na výstupu pak C9 a C10 (oba 22 $\mu$F), tlumivka L1 (3,9 $\mu$H), bootstrap kondenzátor C8 (100 nF) a zenerova dioda D6 (3,6 V). Toto řešení je uvedeno na obrázku~\ref{fig:3v3cascade}. Díky němu může zařízení v omezeném režimu běžet i pouze z USB, ale bez napájení a bez komunikace objektivu nebude dostupné nastavování clony ani autofocus.

Měnič CONV2 s obvodem \texttt{AP63200WU} je nastaven na výstup 5,5 V pro napájení logiky objektivu. Na vstupu jsou kondenzátory C43 (100 nF) a C44 (10 $\mu$F), na výstupu tlumivka L3 (10 $\mu$H), kondenzátory C46 a C47 (oba 22 $\mu$F), bootstrap kondenzátor C45 (100 nF) a zenerova dioda D2 (5,7 V). Rezistory pro nastavení výstupního napětí jsou vybrány podle rovnice~\ref{nastavenimenice} poskytnuté výrobcem:
\begin{equation}
R_{1} = R_{2} \cdot \left(\frac{V_{OUT}}{0.8V}-1 \right)
\label{nastavenimenice}
\end{equation}
Toto zapojení je zachyceno na obrázku~\ref{fig:lenslogic}.

Měnič CONV4 (AP63200WU) je v zapojení použit jako samostatná větev pro napájení hlavních pohonů v objektivu, s výstupním napětím cca 6 V. Na vstupu (síť +7V2) jsou kondenzátory C48 (100 nF) a C49 (10 $\mu$F) pro odrušení; spínací stupeň používá bootstrap kondenzátor C50 (100 nF) a za ním následuje tlumivka L4 (10 $\mu$H). Výstupní filtrace tvoří kondenzátory C51 a C52 (oba 22 $\mu$F). Nastavení výstupního napětí realizuje dělič R7/R6 (R7 = 100 k$\Omega$ na výstupu, R6 = 16 k$\Omega$ k zemi) osazený podle rovnice \ref{nastavenimenice}, čímž se dosahuje cílové hodnoty~6 V. Pro finální vyhlazení je zapojena zenerova dioda D3 (6,2 V). Toto zapojení je zobrazeno na obrázku~\ref{fig:lensmainpower}.
\begin{figure}
    \centering
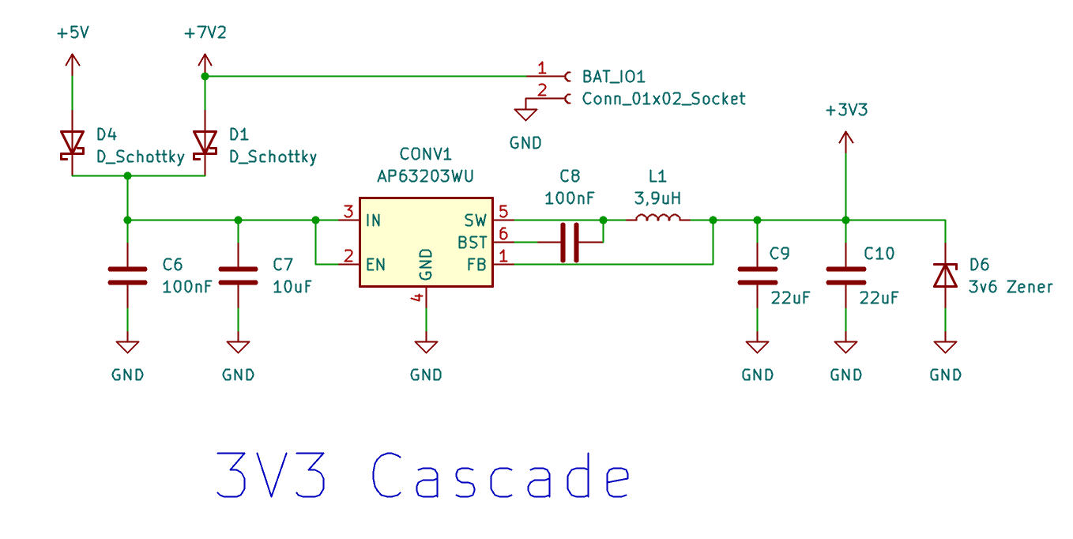
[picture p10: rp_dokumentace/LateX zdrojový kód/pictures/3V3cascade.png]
    
    \caption{Měnič na 3,3 V v eschématu \textit{[Zdroj: Vlastní]}}
    \label{fig:3v3cascade}
\end{figure}
\begin{figure}
    \centering
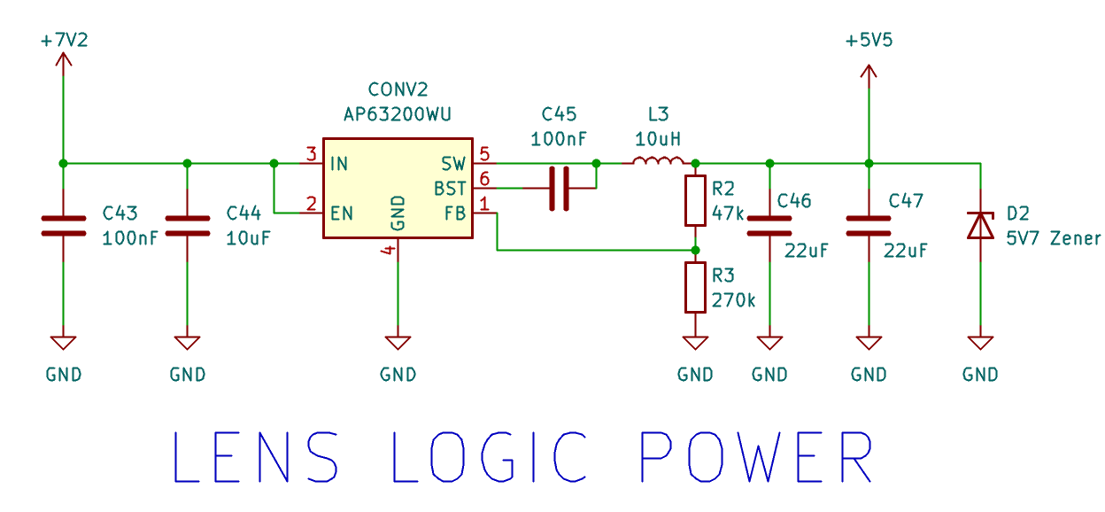
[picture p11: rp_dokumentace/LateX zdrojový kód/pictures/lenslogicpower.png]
    
    \caption{Zapojení měniče napětí pro komunikaci s objektivem \textit{[Zdroj: Vlastní]}}
    \label{fig:lenslogic}
\end{figure}
\begin{figure}
    \centering
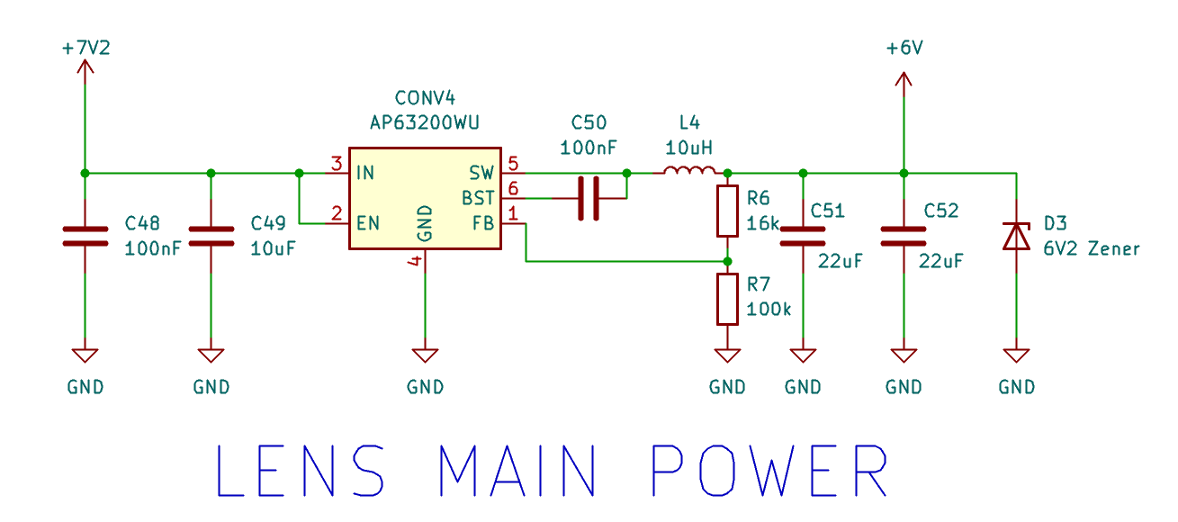
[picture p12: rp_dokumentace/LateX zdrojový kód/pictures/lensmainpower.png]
    
    \caption{Zapojení měniče napětí pro obsluhu servo motorů v objektivu \textit{[Zdroj: Vlastní]}}
    \label{fig:lensmainpower}
\end{figure}
\section{Externí Flash paměť}

Externí flash paměť je osazena jako samostatný nevolatilní prostor pro firmware a provozní data\cite{w25q256,local_kicad}. Připojení je řešeno přes QSPI, aby byla zajištěna dostatečná propustnost při startu systému i při běhu aplikace.

Ve schématu je osazena paměť ESP\_FLASH1 typu \texttt{W25Q256JVEIQ}. Stabilitu této části zajišťuje zejména důraz na velmi nízké odchylky mezi jednotlivými cestami. To je důležité zejména kvůli vysokým přenosovým rychlostem. Schéma zapojení a n8vrh routování této části jsou zobrazeny na obrázku~\ref{fig:flash}. Všimněte si, že všechny cesty jsou vedeny v jedné vrstvě, jsou co nejkratší a mají stejné délky vyladěné pomocí tzv. „meandrů“ . Díky tomu je minimalizováno riziko ztráty dat kvůli rušení nebo odrazům signálu.
\begin{figure}
    \centering
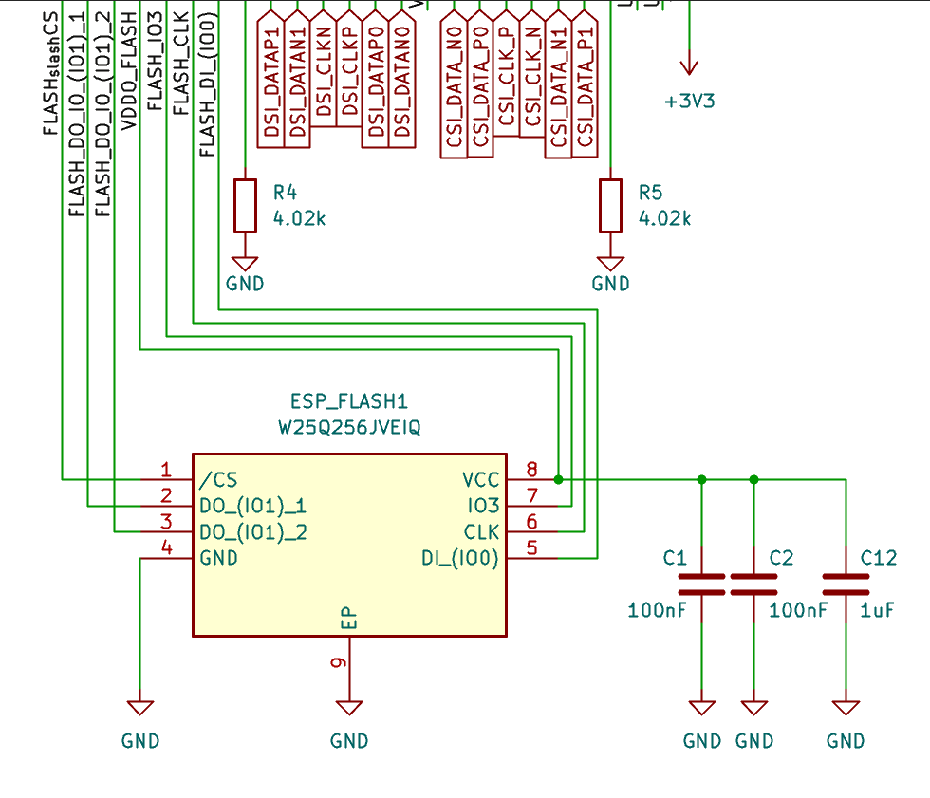
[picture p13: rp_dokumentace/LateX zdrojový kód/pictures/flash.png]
    
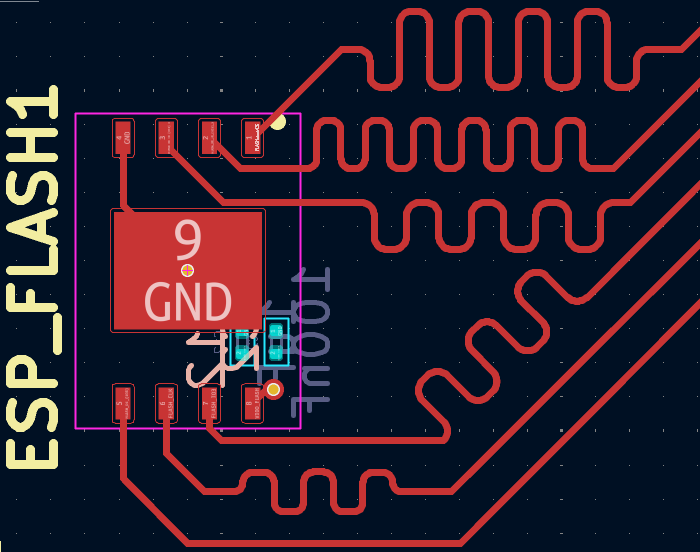
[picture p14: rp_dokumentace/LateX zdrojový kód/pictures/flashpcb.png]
    
    \caption{Zapojení externí flash paměti v eschématu a v PCB editoru. \textit{[Zdroj: Vlastní]}}
    \label{fig:flash}
\end{figure}

\section{Konektory pro připojení periférií}
\subsection{Konektor pro zapojení kamerového modulu}
Kamerový modul je připojen přes 15pinový FFC konektor. Vedeny jsou diferenciální páry MIPI CSI, řídicí sběrnice I2C, napájení a řídicí signály pro zapnutí modulu. Stejně jako u Flash paměti je důležité dbát na symetrii délek cest a jejich tvar pro zabránění rušení.
\begin{figure}
    \centering
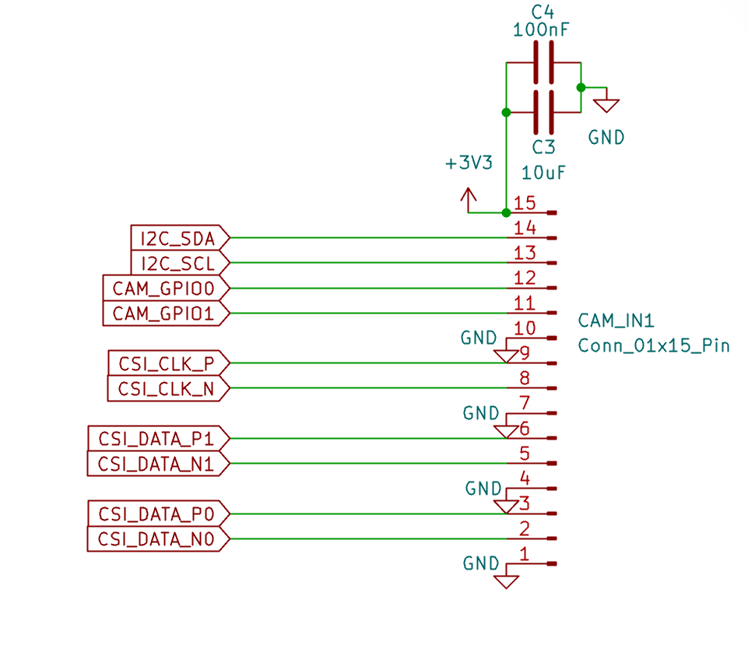
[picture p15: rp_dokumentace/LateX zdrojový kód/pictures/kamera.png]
    
    \caption{Zapojení konektoru pro připojení kamerového modulu \texttt{IMX219}. \textit{[Zdroj: Vlastní]}}
\end{figure}

Text této části je záměrně veden obecně na úrovni použitého rozhraní a zapojení. Konkrétní parametry obrazového snímače je vždy nutné vztáhnout k reálně osazenému kamerovému modulu. Je tedy možné použít kamerový modul se stejným pinoutem, ale s jinými parametry, a to i bez nutnosti úprav v zapojení. Naopak použití modulu s jiným pinoutem by vyžadovalo zásadní úpravy v zapojení i v softwaru.

\subsection{Konektor pro zapojení displaye}
Displej je připojen přes samostatný 15pinový FFC konektor. Na tomto rozhraní jsou vyvedeny MIPI DSI páry pro obrazová data a pomocné signály I2C pro obsluhu dotykové vrstvy\cite{local_kicad,waveshare}.
\begin{figure}
    \centering
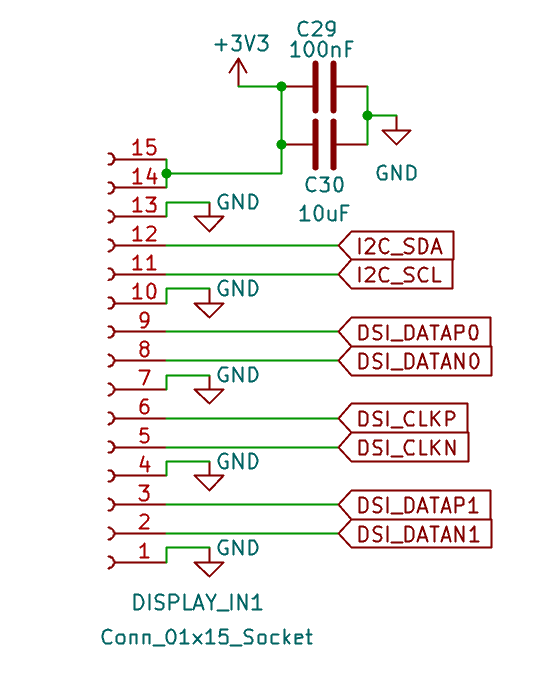
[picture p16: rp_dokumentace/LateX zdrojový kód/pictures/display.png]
    
    \caption{Zapojení konektoru pro připojení displeje v eschématu. \textit{[Zdroj: Vlastní]}}
\end{figure}

I zde je nutné dbát na délkovou symetrii cest a jejich tvar, aby se minimalizovalo rušení a ztráta dat při přenosu obrazových informací.
\begin{figure}
    \centering
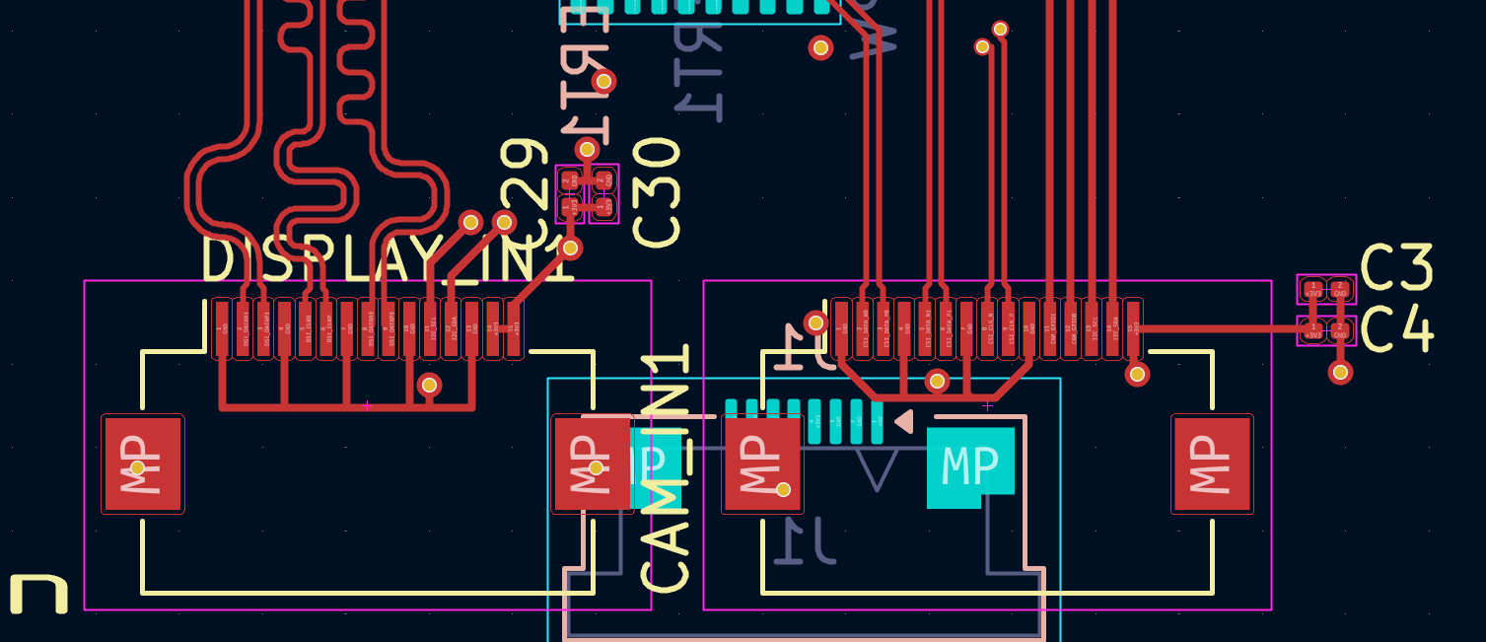
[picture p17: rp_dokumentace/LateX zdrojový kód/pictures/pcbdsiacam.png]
    
    \caption{Návrh pro zapojení konektoru pro připojení kamery (vlevo) a displaye (vpravo). \textit{[Zdroj: Vlastní]}}
\end{figure}
\subsection{Dock pro umístění SD karty}
Pro ukládání snímků je osazen konektor pro MicroSD kartu\cite{local_kicad}. Kromě datových linek je využita i detekce vložení karty, což zjednodušuje obsluhu v softwaru a snižuje riziko zápisu na neosazené médium.
\begin{figure}
    \centering
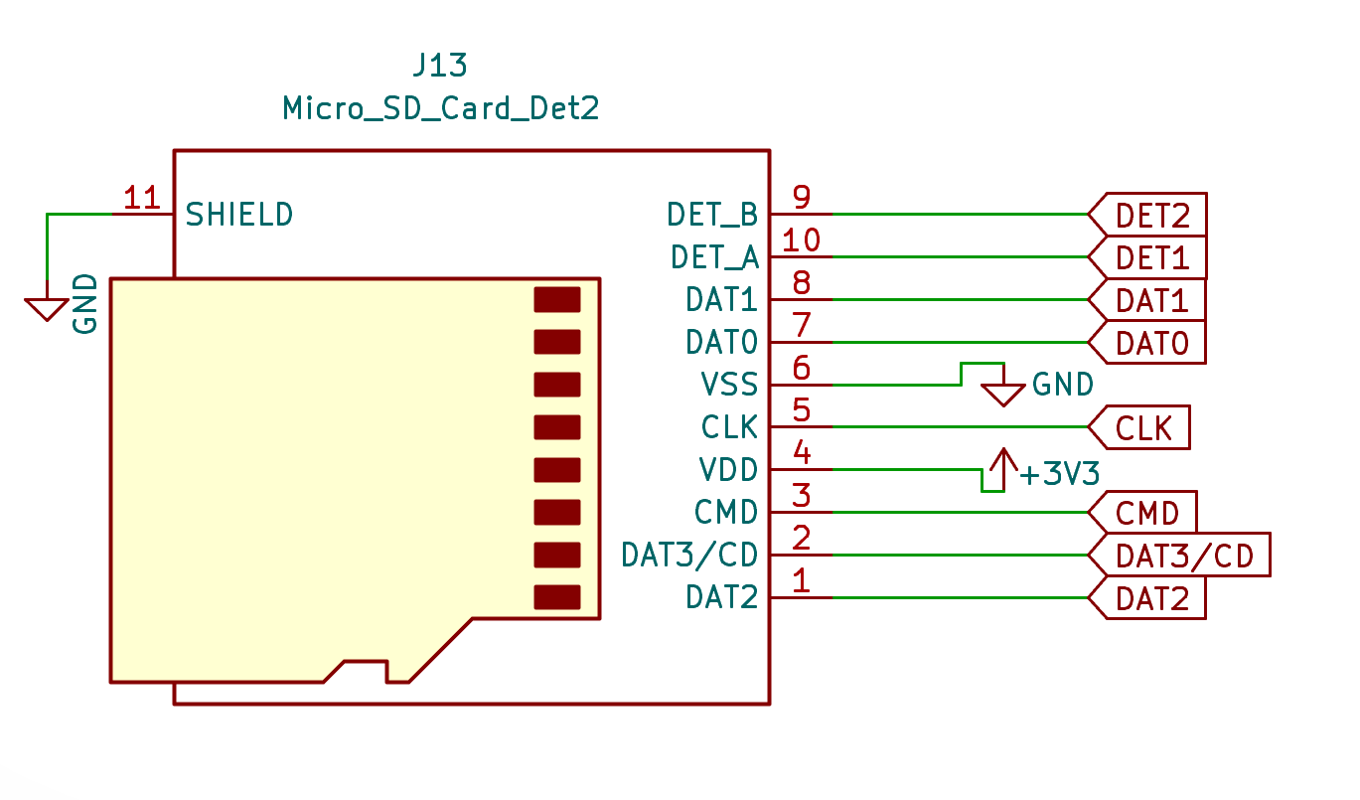
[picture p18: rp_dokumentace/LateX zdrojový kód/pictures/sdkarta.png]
    
    \caption{Zapojení slotu pro SD kartu v eschématu. \textit{[Zdroj: Vlastní]}}
\end{figure}
\subsection{Konektory pro tlačítka ovládání}
Pro připojení ovládacích tlačítek jsou navrženy dva konektory, které umožňují připojení jak hlavního ovládacího rozhraní (pro nastavení parametrů a navigaci v menu), tak i samostatného tlačítka spouště. Ovládací tlačítka, a k tomu indikační červená led dioda, jsou připojena k GPIO 42--52. Celá tato deska byla recyklována z rozbraného modelového fotoaparátu Canon 550D. Tlačíko spouště je stejného původu, ale je připojeno samostatně kvůli své specifické funkci a umístění v konstrukci zařízení. Kvůli komplikovanému zapojení na původní desce 550D je nutné připojit tlačítko spouště samostatně na plošném spoji vlastní výroby, proto je na návrhu osazen samostatný konektor pro tento účel.
\begin{figure}
    \centering
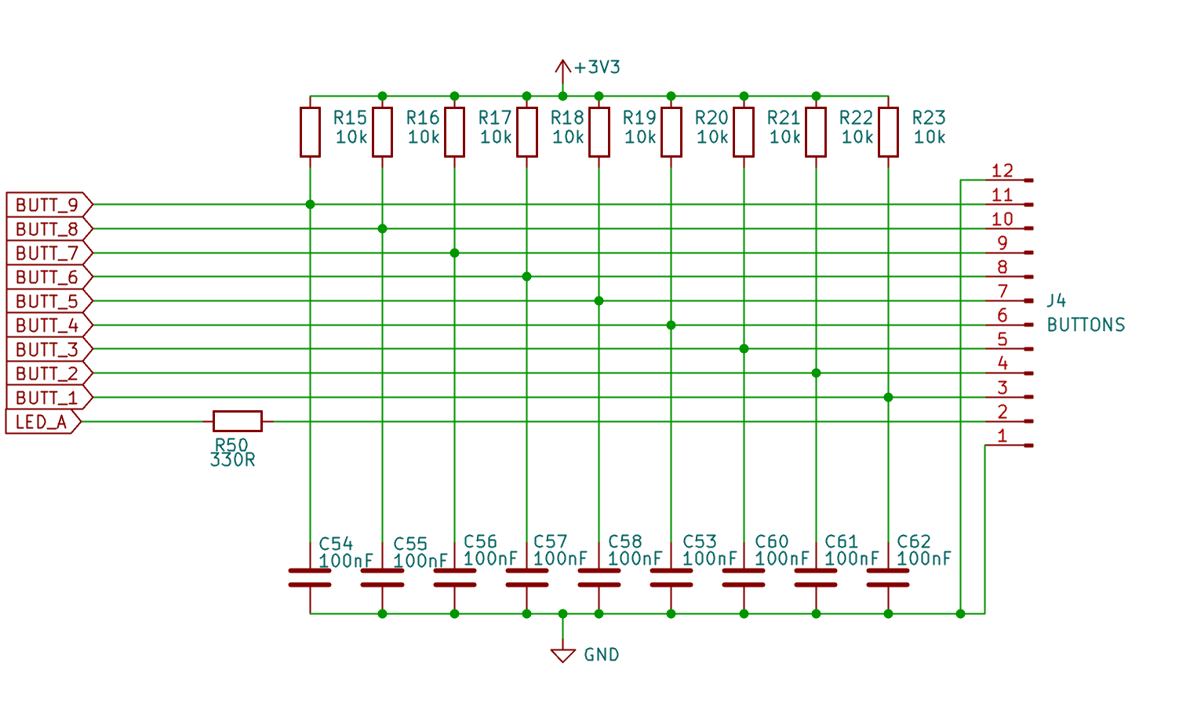
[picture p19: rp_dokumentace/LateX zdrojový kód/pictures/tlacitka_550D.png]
    
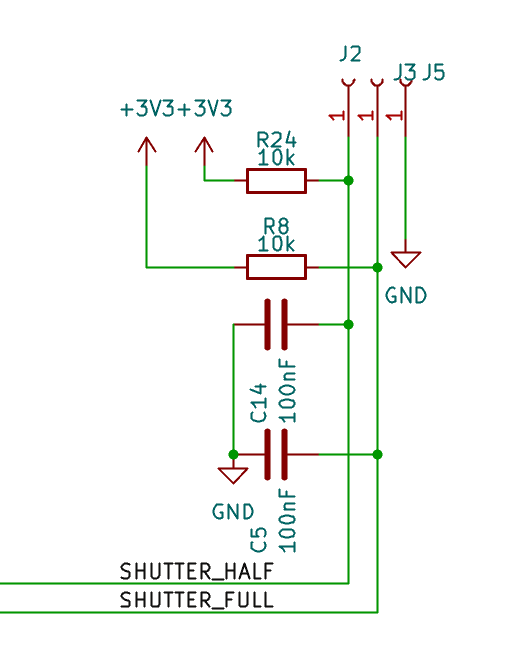
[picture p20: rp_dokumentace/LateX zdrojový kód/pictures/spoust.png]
    
    \caption{Zapojení konektorů pro připojení ovládacích tlačítek v eschématu. Nahoře hlavní olvádací rozhraní, dole tlačítka spouště Fotaoparátu. \textit{[Zdroj: Vlastní]}}
\end{figure}

\section{Převodník logických úrovní pro komunikaci s objektivem}
Pro komunikaci s objektivem Canon EF je osazen obousměrný převodník logických úrovní \texttt{TXS0108EPW}\cite{txs0108e,canon_ef_notes}. Důvodem je rozdíl mezi logikou mikrokontroléru a úrovněmi na straně objektivu.
\begin{figure}
    \centering
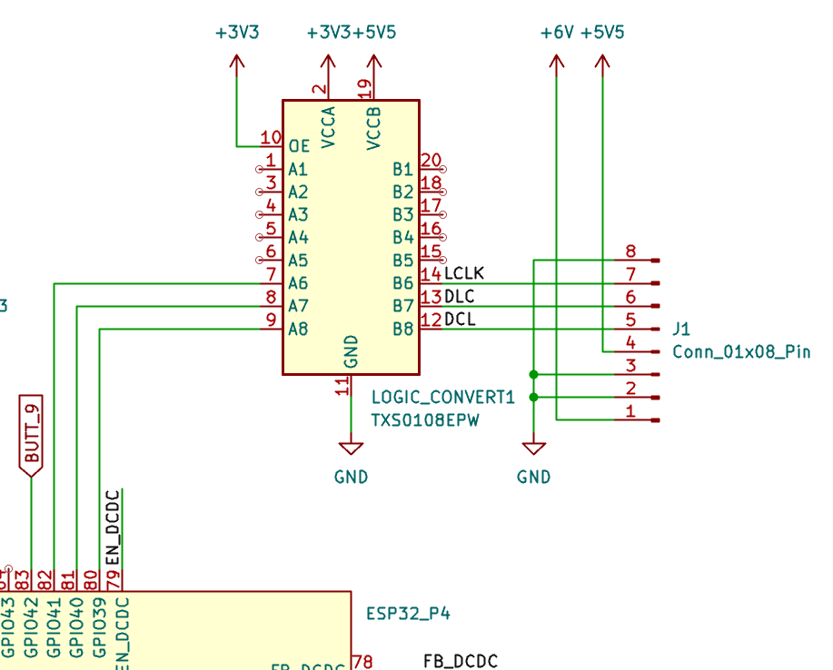
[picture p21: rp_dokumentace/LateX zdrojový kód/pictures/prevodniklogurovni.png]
    
    \caption{Zapojení převodníku logických úrovní pro komunikaci s objektivem v eschématu. \textit{[Zdroj: Vlastní]}}   
\end{figure}

Z dostupných měření vyplývá, že část EF signálů není spolehlivá při 3,3V úrovni, proto je oddělení napěťových domén v této části nezbytné\cite{canon_ef_notes,magic_lantern}.

\section{USB-C USB 2.0 konektor}
Datové a servisní rozhraní je řešeno přes USB-C v režimu USB 2.0\cite{local_kicad,usb_typec}. Rozhraní slouží pro programování firmwaru, ladění i napájení během vývoje.

Na CC pinech jsou osazeny pull-down rezistory (Rd) pro indikaci zařízení; v našem návrhu jsou to R9 a R1 (5.1~k$\Omega$) k zemi, což signalizuje hostu, že jde o device. Datové linky D$+$ a D$-$ jsou chráněny ESD/TVS součástí (\texttt{ESDA6V1U1RL}) a mohou být vedeny přes common-mode choke pro lepší EMI/EMC potlačení. SBU piny nejsou v návrhu využity.

V kombinaci s nativní podporou USB v ESP32-P4 toto řešení výrazně zjednodušuje oživení i další vývoj\cite{esp32p4_ds,esp32p4_web}.

\begin{figure}
    \centering
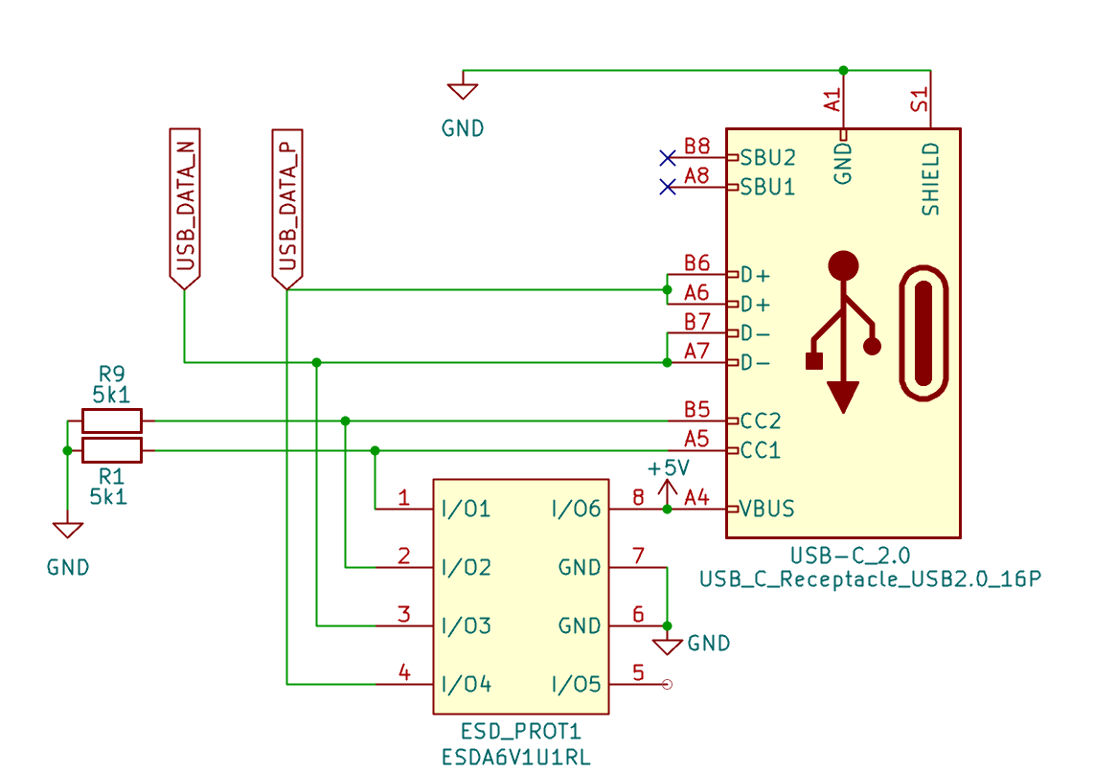
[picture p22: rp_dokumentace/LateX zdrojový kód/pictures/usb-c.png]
    
    \caption{Zapojení USB-C konektoru v eschématu. \textit{[Zdroj: Vlastní]}}
\end{figure}

\chapter{Plánované oživení a konstrukce}

% Poznámka o stavu
Praktické oživení hardwaru a dokončení mechanické konstrukce nebyly dokončeny do termínu uzávěrky, neboť jsem přecenil své síly a podcenil časový limit. Následující části proto popisují plánované kroky a doporučený postup pro systematické oživení a dokončení návrhu mechaniky.

\section{Plánované oživení}
Pro úspěšné softwarové oživení desky je třeba připravit konzistentní vývojové prostředí, automatizované nástroje pro flashování a sběr logů a repozitář s minimálním testovacím firmwarem. V praxi to znamená nastavit toolchain a build systém (např. ESP‑IDF nebo jiný zvolený framework) a zajistit stabilní verze kompilátorů a utilit, připravit skripty pro pohodlné flashování přes USB a zachytávání sériového výstupu (UART/USB logging) a mít v repozitáři konfiguraci buildu spolu s jednoduchým testovacím obrazem (např. minimal boot image nebo „blinky“) pro rychlé ověření hardwaru.
Po této přípravě následuje vlastní sekvence bring‑upu: nejprve se nahraje bootloader a velmi jednoduchý firmware, který pouze inicializuje periférie a posílá základní diagnostické zprávy přes sériovou linku. Na základě těchto logů ověříme boot sekvenci, přítomnost a verze paměti a dosažitelnost důležitých pinů. Dále firmware krokově rozšiřujeme o inicializaci hodinového systému a QSPI rozhraní tak, aby bylo možné korektně číst z externí flash paměti.

Následují kroky zaměřené na periferie vyšší úrovně: přidání a otestování ovladače SD karty a připojení souborového systému (např. FAT) s ověřením čtení a zápisu souborů, integrace ovladače displeje s jednoduchým vykreslením testovacího obrazu a následně integrace ovladače kamery/CSI — nejprve přes I2C inicializovat senzor a poté spustit jednoduchý capture, uložit snímek do paměti a ověřit jeho zápis na SD nebo přenos přes USB.

Během celého procesu je vhodné zavést jednoduchou diagnostiku ve firmwaru (watchdog, zdravotní telemetrie, detekce chyb) a zajistit možnost bezpečného aktualizačního mechanismu (OTA nebo flash přes USB) pro případ rychlých oprav. Pro opakované ověření se připraví automatizované testovací skripty: smoke test pro boot a základní I/O, sady testů pro QSPI/SD/I2C a funkční scénáře zahrnující pořízení snímku a jeho zobrazení či uložení.

Do ověřovacích metrik softwarového oživení patří především úspěšný boot bez kritických chyb, schopnost číst a zapisovat do externí paměti a SD karty, stabilita karetní a kamerové komunikace (latence a propustnost) a spolehlivost aktualizačního procesu. Tyto body by měly být zachyceny v jednoduchých testovacích protokolech, které umožní opakovat ověření i po případných hardwarových úpravách.

\section{Plánovaná konstrukce}
Z důvodu komplexity mechanické konstrukce bajonetu, který bych sám nemohl udělat pro bezpečné uchycení objektivu, jsem se rozhodl využít tělo a vybrané periferie z modelu Canon 550D. Toto řešeení jsem si vybral jako spíše dočasné, jelikož by umožnilo rychlejší vývoj a oživení. V budoucnu bych rád navrhl vlastní mechanickou konstrukci, jelikož je potřeba brát v úvahu i tzv. flange, neboli vzdálenost mezi bajonetem a snímačem, která je u Canon EF 44 mm. Proto mám v plánu vytořit vlastní tělo Fotaoparátu, s vnořeným bajonetem EF.

\begin{figure}
    \centering
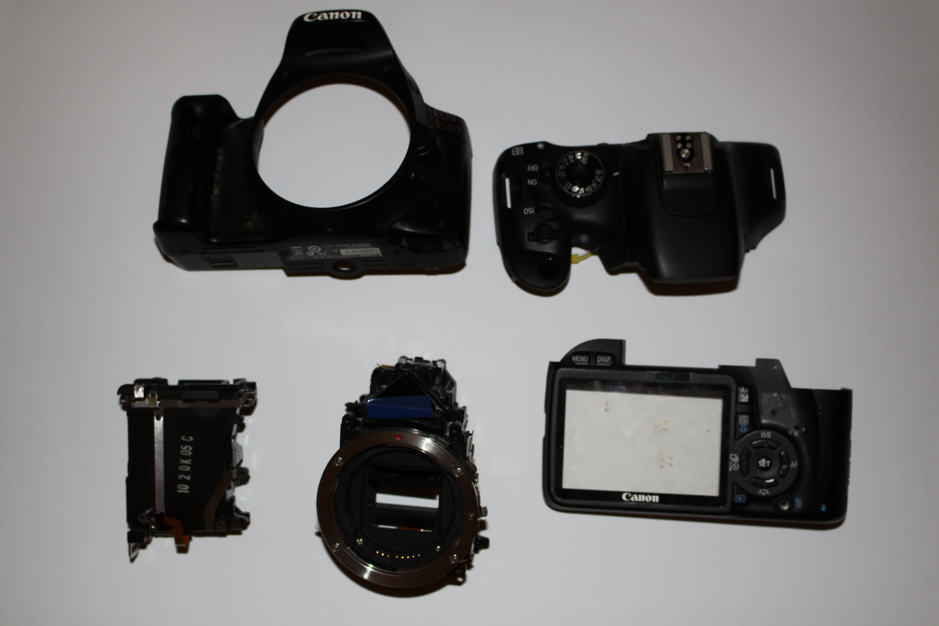
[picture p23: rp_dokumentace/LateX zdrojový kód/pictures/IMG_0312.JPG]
    
    \caption{Části rozebraného těla fotoaparátu Canon 550D vybrané ke konstrukci. \textit{[Zdroj: Vlastní]}}
\end{figure}
\begin{figure}
    \centering
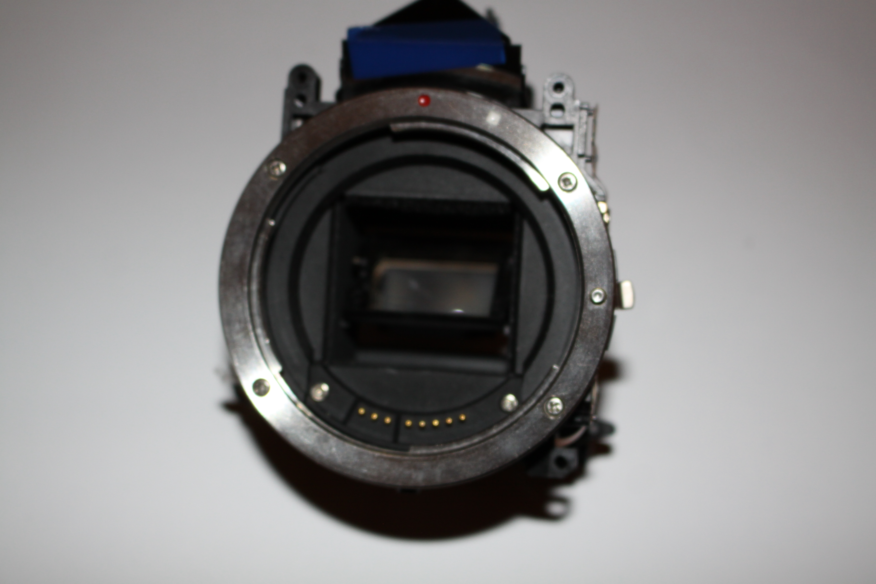
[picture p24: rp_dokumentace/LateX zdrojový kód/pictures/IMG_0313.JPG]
    
    \caption{Bajonet z modelu Canon 550D, který bude použit pro uchycení objektivu. \textit{[Zdroj: Vlastní]}}
\end{figure}

\chapter*{Závěr}
  Systém pro mikrokontrolérový fotoaparát založený na \texttt{ESP32-P4} jsem bohužel nestihl dokončit. Dokončený úsek práce tvoří detailní návrh schémat, volba klíčových komponent (externí QSPI flash, kamerový modul, DSI displej, napájecí měniče), návrh konektorů a pomocných obvodů (USB‑C, SD, převodník napěťových úrovní) a příprava počátečního firmwaru pro bring‑up.

    Co se podařilo: většina schémat a návrhů byla dokončena a zdokumentována včetně poznámek k routování kritických QSPI/CSI/DSI cest. Byl připraven plán oživení s krokovým postupem pro ověření bootu, QSPI, SD, displeje a kamery. Také jsem identifikoval klíčová rizika a navrhl opatření (vyrovnání délek, přídavná filtrace, ochrana proti ESD), která je třeba ověřit při bring‑upu.

    Co zůstalo nedokončeno: finální DRC a doladění napájecích filtrací a odrušení, kompletní mechanická integrace a sériové funkční testování na prototypu. Tyto nedostatky pramenily hlavně z nutnosti opakovaných úprav schématu a z časové náročnosti ladění HF signálů.

    Další postup: nejprve dokončit DRC a optimalizovat routování kritických signálů (vyrovnání délek, kontrola impedance, případné stínění), poté provést zátěžové testy napájení a doladit filtry. Následně postupný bring‑up: ověření bootloaderu a QSPI, integrace SD a souborového systému, inicializace displeje a nakonec integrace kamery s ukládáním snímků. Pro mechanické ověření doporučuji dočasné použití těla Canon 550D, které urychlí ladění, a po ověření navrhnout finální konstrukci.

    Výstupem této fáze jsou jasné, zdokumentované kroky a opatření, která umožní systematické dokončení oživení. Získané zkušenosti s návrhem HF rozhraní, řízením napájení a integrací periferií poskytují pevný základ pro další vývoj firmwaru, přidání uživatelského rozhraní a zavedení spolehlivého aktualizačního mechanismu.
% CIATCE ---------------------------------------------------------------------------
\begin{thebibliography}{99}
\addcontentsline{toc}{chapter}{Literatura}

% \bibiintem{reference} referenci pak pouzijte v textu \cite{reference}.
% dodržujte formátování citací dle normy: Jméno, název (kurzívou), vydavatel, rok, ...
% Pořadí citací podle výskytu v textu. 

\bibitem{ap63200} DIODES INCORPORATED. \textit{AP63200/AP63201/AP63203/AP63205 -- Buck Converter Datasheet}. Dostupné z: \url{https://www.diodes.com/assets/Datasheets/AP63200-AP63201-AP63203-AP63205.pdf}. [cit. 2026-04-23].

\bibitem{local_kicad} HOVORKA, V. \textit{Projektové schéma v KiCadu (fotaoparát.kicad\_sch, power.kicad\_sch, peripherals.kicad\_sch)}. Lokální projektová dokumentace, 2026.

\bibitem{local_readme} HOVORKA, V. \textit{RP-Hovorka/readme.md -- hardware TODO a napájecí větve}. Lokální projektová dokumentace, 2026.

\bibitem{esp32p4_ds} ESPRESSIF SYSTEMS. \textit{ESP32-P4 Datasheet}. Lokální soubor: datasheeshty/Esp32-p4\_datasheet\_en.pdf, 2026.

\bibitem{esp32p4_trm} ESPRESSIF SYSTEMS. \textit{ESP32-P4 Technical Reference Manual}. Lokální soubor: datasheeshty/Esp32-p4\_technical\_reference\_manual\_en.pdf, 2026.

\bibitem{w25q256} WINBOND. \textit{W25Q256JV -- Serial NOR Flash Datasheet}. Lokální soubor: datasheeshty/w25q256jv dtr revc 10252016.pdf, 2016.

\bibitem{arducam_shop} RPI SHOP CZ. \textit{Arducam IMX219 8 MPx kamerový modul}. Dostupné z: \url{https://rpishop.cz/635962/arducam-imx219-8-mpx-kamerovy-modul-s-objektivem-m12-ls1820-noir/}. [cit. 2026-04-23].

\bibitem{waveshare} WAVESHARE. \textit{2.8inch DSI LCD -- Product Page}. Dostupné z: \url{https://www.waveshare.com/product/displays/2.8inch-dsi-lcd.htm}. [cit. 2026-04-23].

\bibitem{waveshare_wiki} WAVESHARE. \textit{2.8inch\_DSI\_LCD -- Wiki}. Dostupné z: \url{https://www.waveshare.com/wiki/2.8inch_DSI_LCD}. [cit. 2026-04-23].

\bibitem{hirose_dm3} HIROSE ELECTRIC. \textit{DM3 Series -- MicroSD Card Connector Catalog}. Dostupné z: \url{https://www.hirose.com/en/product/document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}. [cit. 2026-04-23].

\bibitem{esda6v1} STMICROELECTRONICS. \textit{ESDA6V1U1RL -- ESD Protection Device}. Dostupné z: \url{https://lcsc.com/product-detail/Diodes-ESD_STMicroelectronics_ESDA6V1U1RL_ESDA6V1U1RL_C118278.html}. [cit. 2026-04-23].

\bibitem{txs0108e} TEXAS INSTRUMENTS. \textit{TXS0108E -- 8-Bit Bidirectional Voltage-Level Translator}. Dostupné z: \url{https://www.ti.com/lit/ds/symlink/txs0108e.pdf}. [cit. 2026-04-23].

\bibitem{canon_ef_notes} HECTOR, M. \textit{software/canon-ef-protocol-notes.md}. Dostupné z: \url{https://gist.github.com/marcan/858c242db2fc595da1e0bb70a05192fc#file-canon-ef-protocol-notes-md} (reverse engineering EF sběrnice), 2026.

\bibitem{magic_lantern} MAGIC LANTERN TEAM. \textit{Magic Lantern}. Dostupné z: \url{https://www.magiclantern.fm}. [cit. 2026-04-23].

\bibitem{usb_typec} USB IMPLEMENTERS FORUM. \textit{USB Type-C Specification}. Dostupné z: \url{https://www.usb.org/sites/default/files/documents/usb_type-c.zip}. [cit. 2026-04-23].

\bibitem{esp32p4_web} ESPRESSIF SYSTEMS. \textit{ESP32-P4 Product Overview}. Dostupné z: \url{https://www.espressif.com/en/products/socs/esp32-p4}. [cit. 2026-04-23].

\end{thebibliography}
% konec citací

% Přílohy: 
\chapter*{Přílohy}
\pagenumbering{Roman}
\addcontentsline{toc}{chapter}{Přílohy}

\end{document}

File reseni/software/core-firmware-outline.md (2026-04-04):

# Core firmware

Cíl: výkonově citlivá vrstva běžící na ESP32-P4.

## Odpovědnosti
- inicializace kamery, displeje, SD karty a EF rozhraní
- čtení tlačítek a vstupů
- live view a snímání fotek
- ukládání snímků na SD
- řízení napájení a sleep režimů
- chybové stavy a recovery

## Hlavní moduly
- `camera`
- `display`
- `storage`
- `input`
- `power`
- `ef_mount`
- `system`

## Tok spuštění
1. boot
2. hardware init
3. load settings
4. start camera pipeline
5. start UI
6. enter event loop

## Důležité poznámky
- tento program má být napsaný v C/C++ nad ESP-IDF
- obrazová cesta nesmí jít přes interpret
- GUI může používat LVGL

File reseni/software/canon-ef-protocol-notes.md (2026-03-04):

Testing done using a Canon EOS 600D and a Canon EF-S18-55mm f/3.5-5.6 IS II.

## Pinout

1. VBAT
2. DET (common with P-GND on lens side)
3. P-GND
4. VDD
5. DCL
6. DLC
7. LCLK
8. D_GND

## Signal levels

VDD is nominally 5V. VBAT seems to also be ~5V (others report 6V).

VDD is always active (even with the camera off, if it has been powered on at
least once) when a lens is connected (DET = low). When the camera turns on, VDD
increases slightly (standby power vs. active regulator?)

The data lines are idle high and weakly pulled up by the camera. However, the
drivers are not open drain (to get better rise times).

The signal levels are 5V. Driving 3.3V on DCL does *not* work - you need 5V,
the lens seems to consider 3.3V as logic low.
3.3V on LCLK does seem to work.

## Timing

The protocol is basically a variant of SPI with CPOL=1,CPHA=1. There is no
framing or CS signal, which complicates parsing, and there is an additional
variable length ACK clock pulse driven by the lens (kind of like I²C clock
stretching).

Default clock period is 13µs (6.5µs per half cycle) = 77 kHz (80 kHz).
This decreases to 2µs for newer lenses (1µs per half cycle) = 500 kHz
Intended duty cycle seems to be 50% (fast mode seems to be 0.8µs low / 1.2µs
high, but this is likely just an analog effect).

Power-on timing:
- 1µs low glitch on DCL (?)
- 42µs delay (?)
- Single 6.5µs low pulse on DCL (does this serve a purpose?)
- 103µs delay
- First three byte cycles:
    - `C 00 L ff [TX 89us ACK 14us BUSY 2165us]` <- note long BUSY period
    - `C 0a L aa [TX 89us ACK 14us BUSY 4us]`
    - `C 00 L aa [TX 89us ACK 14us BUSY 4us]` <- VBAT turned on by camera *during* the lens ACK/BUSY pulse

Command byte timing:
- Camera drives DCL at a random value for ~18µs (slow mode) or ~4µs (fast mode)
  - This seems to usually be whatever the last bit of the previous command was,
    but not always consistent.
- Each bit is driven (by both camera and lens) on the falling edge of LCLK,
  and sampled on the rising edge.
- Camera drives DCL high (or stops driving?) and stops driving LCLK 1µs
  after the last rising edge of LCLK (this is half a cycle in fast mode, but
  much shorter than half a cycle in slow mode).
- Lens releases DLC ~4.3µs after the last rising edge of LCLK
- Lens drives LCLK low ~14µs after the last rising edge of LCLK (ACK/BUSY)
- ACK/BUSY pulse seems to last at least 4µs but may be much longer
- Gap between bytes (rising edge of LCLK ACK/BUSY to first falling edge of LCLK)
  is at least 120µs in slow mode and at least 18µs in fast mode.

Note that slow/fast mode only changes the camera timings. The lens always
behaves the same way.

## Exceptional states

Holding LCLK low for >700µs seems to reset the lens. The lens will then itself
hold LCLK low until ready (~300us, sometimes longer).

Pulsing LCLK low (e.g. shifting in one bit) then waiting causes the lens to time
out. After 740µs, it will reset itself and hold LCLK low for ~300-400µs. This
may effectively be the same situation as the above (holding LCLK low).

Command 08 powers down the lens. After this, the next command sent by the camera
is ignored, and the lens will hold LCLK low for ~2ms during that command as it
powers up.

## General command structure

Lens commands opcodes are one byte, and may have a number of arguments and reply
bytes. The lens replies to a command starting on the next byte cycle. Commands may be
pipelined: the last response byte from the lens may be transferred at the same
time as the next command from the camera.

When the lens receives an unknown command, it will echo it back to the camera
on the next cycle.

There is no explicit framing, therefore keeping sync with the protocol *requires*
knowledge of all command lengths. There are no implicit timeouts. You can send
a command, wait one second, then send the argument, and it will be interpreted
as such, not a new command. Commands have both fixed argument and response byte
counts (i.e. a fixed overall length); the camera cannot interrupt an information
retrieval command by sending another command. The lens ignores dummy data from
the camera while it is replying to a command. Canon cameras send 00 as dummy
padding bytes during such read cycles.

## Command ranges

The command codes follow certain patterns:

* 00-0f: commands 0-f with zero arguments
* 10-1f: commands 0-f with one argument
* 20-2f: commands 0-f with one dummy argument (unused/redundant)
* 30-3f: information commands
* 40-4f: commands 0-f with two arguments
* 50-5f: commands 0-f with one dummy argument (unused/redundant)
* 60-6f: more info commands
* 70-7f: unused/unimplemented
* 80-ff: largely more info commands

These range 0x, 1x, 2x, 4x, 5x encode the same operations. Each operation is
intended to be used only with one argument count (of 0x, 1x, 4x); if used with
the wrong count, it will instead re-use the argument from the previous valid
operation. The basic commands are:

```
00          No-op
01          
12 XX       Change aperture (+/- int8 0xXX)
13 XX       Same as 12
44 HH LL    Change focus (+/- int16 0xHHLL)
05          Focus to max (infinity)
06          Focus to min
07          
08          Power down
09          
0a          Ready/sync (replies aa)
0b          
0c          
0d          
0e          
0f          
```

So, for example, the focus is intended to be set with 44 HH LL, but 04, 14 XX,
24 XX, 54 XX will all just repeat whatever the previous valid 44 HH LL command
was.

## Command list

This table exhaustively lists all commands and what they return on this lens.
The lengths can be used to build a table for a protocol analyzer (or a modchip).
The busy time may help determine which commands are unimplemented/no-ops and
which actually do something.

Testing note: "--" values are presumed don't care, but actual testing was done
sending 0a bytes after every command (to determine when it gets interpreted as
command 0a and returns aa).

Consider busy timing values to have +/-1µs jitter.

```
CMD         RET         TIME        Brief description
00          00          4           No-op (padding to get last response)
01          01          4
02          02          9+          (Change aperture, repeats cmd 12/13)
03          03          10+         (Change aperture, repeats cmd 12/13)
04          04          8           (Change focus, repeats cmd 44)
05          05          7           Focus to max (infinity)
06          06          7           Focus to min
07          07          10
08          (ff)        298         Power down
09          09          11
0a          aa          10          Sync
0b          0b          16
0c          XX          4           Repeats last response byte
0d          0d          8
0e          0e          11
0f          0f          12

10 --       10 10       7, 3        (No-op)
11 --       11 11       8, 4
12 YY       12 12       9, 14+      Change aperture (+/- int8)
13 YY       13 13       9, 14+      Change aperture (+/- int8)
14 --       14 14       7, 4        (Change focus, repeats cmd 44)
15 --       15 15       7, 4        (Focus to max)
16 --       16 16       7, 4        (Focus to min)
17 --       17 17       7, 4
18 --       18 (ff)     8, 297      (Power down)
19 --       15 15       7, 5
1a --       1a aa       7, 4        (Sync)
1b --       1b 1b       7, 9
1c --       1c 1c       7, 3        (Repeats last response byte)
1d --       1d 1d       7, 4
1e --       1e 1e       7, 3
1f --       1f 1f       7, 4

20 --       20 20       4, 4        (No-op)
21 --       21 21       4, 3
22 --       22 22       4, 8+       (Change aperture, repeats cmd 12/13)
23 --       23 23       4, 7+       (Change aperture, repeats cmd 12/13)
24 --       24 24       4, 4        (Change focus, repeats cmd 44)
25 --       25 25       4, 4        (Focus to max)
26 --       26 26       4, 4        (Focus to min)
27 --       27 27       4, 4
28 --       28 (ff)     4, 296      (Power down)
29 --       29 29       3, 4
2a --       2a aa       4, 3        (Sync)
2b --       2b 2b       4, 8
2c --       2c 2c       4, 4        (Repeats last response byte)
2d --       2d 2d       4, 4
2e --       2e 2e       4, 3
2f --       2f 2f       4, 4

30 ?? ?? ?? 30 30 30 30 4, 4, 4, 6  ?
31 ?? ??    31 31 31    3, 3, 35    ?
32 ??       08 03       7, 4        ?
33 ?? ?? ?? 07 0a 0a 4a 6, 6, 3, 3  ?
34 ?? ??    34 34 34    5, 4, 12    ?
35          00          5           ?
36..3f      36..3f      3-5         (unused)

40 -- --    40 40 40    8, 4, 4     (No-op)
41 -- --    41 41 41    7, 4, 4
42 -- --    42 42 42    7, 3, 9+    (Change aperture, repeats cmd 12/13)
43 -- --    43 43 43    8, 3, 9+    (Change aperture, repeats cmd 12/13)
44 HH LL    44 44 44    7, 4, 4     Change focus (+/- int16 big-endian 0xHHLL)
45 -- --    45 45 45    7, 4, 5     (Focus to max)
46 -- --    46 46 46    8, 4, 4     (Focus to min)
47 -- --    47 47 47    8, 3, 6
48 -- --    48 48 (ff)  7, 4, 316   (Power down)
49 -- --    49 49 49    8, 3, 6
4a -- --    4a 4a aa    7, 3, 4     (Sync)
4b -- --    4b 4b 4b    7, 4, 10
4c -- --    4c 4c 4c    7, 4, 7     (Repeats last response byte)
4d -- --    4d 4d 4d    8, 4, 5
4e -- --    4e 4e 4e    7, 4, 5
4f -- --    4f 4f 4f    7, 3, 5

50 --       50 50       4, 4        (No-op)
51 --       51 51       4, 4
52 --       52 00       4, 9        (Change aperture, repeats cmd 12/13)
53 --       53 00       4, 9        (Change aperture, repeats cmd 12/13)
54 --       54 54       4, 3        (Change focus, repeats cmd 44)
55 --       55 55       4, 4        (Focus to max)
56 --       56 56       4, 4        (Focus to min)
57 --       57 57       4, 4
58 --       58 (ff)     4, 298      (Power down)
59 --       59 59       4, 5
5a --       5a aa       4, 4        (Sync)
5b --       5b 5b       4, 9
5c --       5c 5c       4, 4        (Repeats last response byte)
5d --       5d 5d       4, 3
5e --       5e 5e       4, 5
5f --       5f 5f       4, 5

60..65      60..65      4           (unused)
66          06          12          ?
67          67          4           (unused?)
68          30          4           ?
69 -- -- -- -- --
    23 09 00 00 00 00
        9, 69, 4, 4, 4, 6           ?
6a -- -- -- -- --
    23 09 00 00 00 00
        11, 65, 4, 3, 4, 6          ?
6b --       f1 9f       11, 4       ?
6c --       f2 b8       12, 4       ?
6d --       f1 9f       12, 4       alias of 6b?
6e --       f2 b8       12, 3       alias of 6c?
6f --       54 2a       6, 4

70..7f      70..7f      4           (unused)

80 -- -- -- -- -- -- --             Get lens basic info
    91 34 00 12 00 37 75 92
        12, 9, 4, 4, 4, 4, 3, 4
81 -- -- --
    3f 00 00 90
        7, 4, 3, 4
82          45          5           Get lens name (first char)
83          46          6           Get lens name (next char)
84          84          6
85 -- -- -- --
    ff ff ff ff ff
        9, 3, 4, 3, 4
86 -- -- -- 03 00 00 00 7, 3, 3, 4
87..8f      87..8f      5-6         (unused)

90 --       00 80       16, 12      Get basic status bits
91 -- --    00 80 44    18, 4, 4    Get extended status bits
92          92          8
93 XX YY ZZ 93 93 93 93 8, 3, 4, 4  Set IS parameters
94 --       f5 00       15, 16
95 -- -- -- 04 37 37 00 6, 6, 3, 3
96..9f      96..9f      3-5         (unused)

a0 --       00 12       7, 3
a1          1f          4
a2          1f          4
a3..af      a3..af      4-5         (unused)

b0 -- --    25 25 50    6, 4, 4
b1 --       91 93       8, 4
b2 -- --    42 02 5f    6, 4, 3
b3 --       99 82       7, 3
b4..bf      b4..bf      4-5         (unused)

c0 --       00 00       13, 3
c1 --       00 33       6, 4
c2 -- -- -- ff ff ff    7, 4, 4, 4
c3          40          8
c4 --       00 20       8, 4
c5 ??       c5 00       4, 4
c6          c6          4
c7 --       fe ff       4, 4
c8          c8          4
c9 -- -- -- -- --
    23 03 ff 00 00 00
        10, 4, 4, 3, 3, 4
ca -- -- -- -- --
    23 03 ff 00 00 00
        9, 3, 4, 4, 3, 4
cb..ce      cb..ce      4-5         (unused)
cf --       00 7c       9, 4

d0          ff          24          Get param array d0 (first byte)
d1          ff          24          Get param array d1 (first byte)
d2          ff          26          Get param array d2 (first byte)
d3          ff          26          Get param array d3 (first byte)
d4          fa          27          Get param array d4 (first byte)
d5..d7      d5..d7      4           (unused)
d8          ff          24          Get param array d8 (first byte)
d9          ff          24          Get param array d9 (first byte)
da          ff          25          Get param array da (first byte)
db          ff          24          Get param array db (first byte)
dc          fa          27          Get param array dc (first byte)
dd..de      dd..de      4-6         (unused)
df          af          7           Get next byte from param array

e0 --       3b c9       9, 4
e1..e3      e1..e3      4           (unused)
e4 --       1d 8e       6, 4
e5..e7      e5..e7      4           (unused)
e8 -- -- -- -- --
    29 96 9e b0 00 00
        10, 3, 3, 4, 4, 4
e9          e9          4           (unused)
ea -- -- -- -- --
    29 4e 9d f6 00 00
        10, 4, 4, 4, 3, 4
eb..ef      eb..ef      4           (unused)

f0          05          12
f1..f7      f1..f7      4-5         (unused)
f8          b5          10
f9          00          11
fa          b5          11
fb          fb          4           (unused)
fc          b7          12
fd          f5          11
fe          b7          12
ff          ff          7

```

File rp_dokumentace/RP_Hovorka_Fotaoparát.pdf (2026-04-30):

## Vyšší odborná škola

## a Střední průmyslová škola elektrotechnická

## Plzeň, Koterovská 85

## ROCNˇ ÍKOVA PR ´ ACE ´

### Téma:

# Fotaoparát - Systém pro obsluhu kamery

Autor práce: | Vít Hovorka
Třída: | 3.L

## Vedoucí práce: Jiří Svihla ˇ

Dne: | 30.4.2026

## Hodnocení:


## Anotace

Tato ročníková práce se zabývá návrhem a prototypovou realizací řídicího systému pro mi-

krokontrolérovou kameru založenou na platformě ESP32-P4. Práce pokrývá výběr a návrh

součástek, konstrukci a rozvržení desky plošných spojů, návrh napájecích větví a roz-

hraní pro kameru, displej a objektiv, a implementaci základního firmware pro pořizování,

zpracování a ukládání snímků. Pozornost je věnována navrhování vysokorychlostních rozhraní (QSPI, MIPI/CSI), integritě signálu a spolehlivému napájení včetně řízení objek-

tivu Canon EF. Výstupem je dokumentovaný návrh desky, zapojení a ukázkový firmware

umožňující základní oživení a testování hardwaru.

Prohlašuji, že jsem tuto práci vypracoval samostatně a použil literárních pramenů a informací,

které cituji a uvádím v seznamu použité literatury a zdrojů informací.

Prohlašuji, že jsem nástroje UI využil v souladu s principy akademické integrity a že na

využití těchto nástrojů v práci vhodným způsobem odkazuji.

Souhlasím s využitím mé práce učiteli VOS a SP ˇ | SE Plzeň k výuce. ˇ
V Plzni dne 30. 4. 2026 | Podpis: |

## Obsah

Seznam zkratek | 7
Uvod ´ | 9
1 Cíle a požadavky | 10
2 Použité nástroje | 12
3 Vybrané komponenty | 15

4

4 Podrobné zapojení na desce | 20
5 Plánované oživení a konstrukce | 35
Literatura | 39

5

Přílohy | I

## Seznam zkratek

Zkratka | Anglicky | Cesky ˇ
ADC | Analog-to-digital converter | analogově-digitální převodník
AF | Autofocus | automatické ostření
CSI | Camera Serial Interface | kamerové sériové rozhraní
DRC | Design Rules Check | kontrola pravidel návrhu
DSI | Display Serial Interface | zobrazovací sériové rozhraní
DTR | Double Transfer Rate | přenos na obou hranách hodinového signálu
ERC | Electrical Rules Check | kontrola elektrických pravidel
ESP-IDF | Espressif IoT Development Framework | vývojový rámec pro čipy ESP od společnosti Espressif
ESD | Electrostatic discharge | elektrostatický výboj
GPIO | General-purpose input/output | univerzální vstup/výstup
HP | High Power | vysoký výkon
I2C | Inter-Integrated Circuit | dvouvodičová sériová sběrnice
NOR | NOR flash | typ nevolatilní flash paměti
ISO | International Organization for Standardization | citlivost podle fotografické terminologie

7

Zkratka | Anglicky | Cesky ˇ
LP | Low Power | Nízký výkon
MILC | Mirrorless interchangeable-lens camera | bezzrcadlový fotoaparát s výměnnými objektivy
MCU | Microcontroller unit | mikrokontrolér
MIPI | Mobile Industry Processor Interface | standard mobilního rozhraní pro periférie
PCB | Printed circuit board | plošný spoj
QSPI | Quad Serial Peripheral Interface | čtyřlinkové sériové periferní rozhraní
SD | Secure Digital | pamět’ová karta Secure Digital
SPI | Serial Peripheral Interface | sériové periferní rozhraní
USB | Universal Serial Bus | univerzální sériová sběrnice

Tabulka 1: Seznam zkratek

8

## Uvod ´

Už asi dva roky se pokouším být aktivním fotografem, s tím že jsem začínal na analogovém

fotoaparátu a snažil se naučit souvislosti mezi hodnotami expozičního času, clony a ISO.

Vždy mě bavilo zkoumat do hloubky jak a proč takové věci fungují a hledat si svou

vlastní ”

cestu trním” kde metodou pokus omyl šlechtím své dovednosti. Proto mi sestavení

svého vlastního fotoaparátu přišlo jako dobrá cesta jak naučit nejen elektrotechniku a

programovaní, ale i jak poznat technologii digitální fotografie do hloubky.

9

## 1 Cíle a požadavky

### 1.1 Požadavky na mechanické konstrukční řešení

Tento projekt by měl v ideálním případě alespoň připomínat MILC kameru. Výrobek,

dále označovaný jako fotaoparát, by měl být tedy:

svými rozměry a tvarem podobný dnešním digitálním fotoaparátům,

jednoduše nositelný a ovladatelný,

| kompatibilní s objektivy řady Canon EF. Toto rozhodnutí má jak objektivní tak i
| subjektivní opodstatnění. Subjektivní rovinou zde je fakt že už několika disponuji.
| V objektivní rovině je fakt že komunikační protokoly jsou už komunitou zmapovány
| (Magic Lantern¹
).

### 1.2 Požadavky na elektrotechnické řešení

Součástí vývoje projektu je i návrh základní desky pro mikročip ESP32-P4 a jeho periférií.

Základní deska tedy:

| bude mít na starost napájení jak hlavního čipu, tak veškerých periférií. Napájení bude zajištěno jedním akumulátorem,
| obstará všechny konektory pro zapojení periférií. Bude tedy možné případné peri- ferie vyměnit za lepší za předpokladu kompatibility z hlediska počtu vývodů (pinů) na konektoru a prostoru v těle Fotaoparátu,

1Magic Lantern firmware, dostupné z: https://www.magiclantern.fm

10

| bude jednoduše programovatelná pomocí USB-C vstupu. Fotaoparát bude open- source výrobek podporující a vyzývající k úpravám podle uživatele, kde open-source znamená výrobek s veřejně dostupným zdrojovým kódem,
| bude navrhována s ohledem na elektromagnetické rušení signálů a možnosti ztráty dat kvůli délkové asymetrii cest a design se tedy bude snažit toto rušení a ztrátu minimalizovat.
| bude navrhována s ohledem na prostor a konstrukční provedení těla fotaoparátu. Bude tedy dostatečně skladná a vývody na periferie budou vhodně umístěny.

### 1.3 Požadavky na softwarové řešení

Výrobek bude nakonec oživen firmwarem vlastní výroby. Software bude mít pevně dané

funkce jako např. nastavení hodnot ISO, clony a rychlosti závěrky. Zároveň by měl mít jed-

noduše přizpůsobitelné uživatelské rozhraní a možnost přidávat další uživatelské funkce.

11

## 2 Použité nástroje

### 2.1 KiCAD 9.0

Pro návrh samotné základní desky Fotaoparátu jsem zvolil software KiCAD 9.0. Jedná

se o open-source software určený pro návrh elektronických schémat a plošných spojů.

Samotný program totiž ukrývá tři hlavní podprogramy: Schematic editor, PCB editor a

Gerber viewer.

Schematic editor umožňuje uživateli nakreslit elektrické schéma a dokonce i do jisté míry

simulovat jednoduché elektrické obvody. Dále KiCAD hned po instalaci disponuje velmi rozmanitou knihovnou součástek, pouzder a datasheetů (technická dokumentace jednot-

livých součástek). Stačí si tedy součástky vybrat, pomocí nástroje ”
kreslit vodiče”je pro-

pojit, nebo pomocí nástroje ”

označení sítě”jim přiřadit stejnou sít’. Je zde také možnost

využít nástroj ERC (electrical rules check - kontrola elektrických pravidel), ten slouží k

odhalení chyb v zapojení vývodů.

PCB editor slouží k přímému návrhu plošného spoje. Obvyklý postup při práci s KiCA-

Dem je nakreslení elektronického schématu, přiřazení pouzder, načtení těchto dat do PCB

editoru a zde rozmístit součástky a routovat cesty spojů. Disponuje také možností nastavení konstrukčních vlastností desky (počet vrstev, tloušt’ka jednotlivých vrstev, základní

tloušt’ka spojů, velikost prokovených otvorů, minimální požadovaná vzdálenost mezi cestami...).

Pro kontrolu designových chyb na desce pak slouží nástroj DRC (design rules check - kon-

trola pravidel designu).

Jako poslední podstatná část programu KiCAD je gerber viewer. Ten slouží k exportu

geberových dat pro výrobu desky.

12


Obrázek 2.1: Ukázka programu schematic editor Zdroj: [vlastní]

Obrázek 2.2: Ukázka programu PCB editor Zdroj: [vlastní]

13


Obrázek 2.3: Ukázka programu Visual Studio Code [Zdroj: Vlastní]

### 2.2 Visual Studio Code

Visual Studio Code (zkráceně VS Code nebo VS) je bezplatné moderní vývojové prostředí.

Díky velkému množství rozšíření, která lze instalovat přímo v programu, a podpoře hlavních operačních systémů (Windows, Linux a macOS) si získalo značnou oblibu mezi

programátory.

Mezi jeho hlavní funkce patří podpora verzovacích systémů jako např. Git, zvýraznění syntaxe (např. závorkové páry), našeptávání kódu, integrovaný terminál a debugger.

V mé práci jsem VS používal zejména pro jednoduché commitování. Dále jsem v něm

používal umělou inteligenci pomocí které jsem napsal část firmwaru.

14

## 3 Vybrané komponenty

### 3.1 MCU

Kvůli vysoké výpočetní náročnosti zpracování dat, která představuje jediný snímek o

rozlišení 8 Mpx, bylo nutné zvolit jeden z nejvýkonnějších mikrokontrolérů dostupných v

době realizace projektu — ESP32-P4. Jedná se o moderní MCU navržené s důrazem na vysoký výpočetní výkon, multimediální zpracování a efektivní práci s periferiemi[4].

ESP32-P4 je vybaven vícejádrovou architekturou, která umožňuje paralelní zpracování

úloh. V tomto MCU se nacházzejí dva procesory – jednojádrový a pomalejší LP a dvoujádrový

rychlejší HP. Oba procesory jsou postaveny na 32-bitové architektuře.

Low power procesor má nejvyšší rychlost taktu 40 MHz. Je narvžený pro zastoupení HP

obvodů při sleep režimu, jelikož i při deep–sleep reimu je tento procesor a jeho pamět

aktivní. Zároveň má však přístup i do HP paměti.

High Power procesor má nejvyšší rychlost taktu 360 Mhz Dále disponuje hardwarovou

akcelerací pro vybrané operace. Jeho paměti zahrnují:

| 16 MB SRAM
| 128 kB ROM pro HP obvody
| 768 kB HP L2mem
| 16 kB ROM pro LP obvody
| 8 kB systémové SPM
| Více vyoskorychlostními externími pamět’ovými rozhraními
| Dvouúrovňovou vysokorychlotní cache

15

Cip také zahruje podporou vysokorychlostních rozhraní, jako např. CSI, DSI a QSPI, ˇ

která umožňují efektivní přenos velkého množství dat.

### 3.2 Flash pamět’

Další důležitou součástí návrhu je externí flash pamět’. Mikrokontrolér ESP32-P4 totiž

nedisponuje dostatečně velkou interní pamětí pro uložení uživatelského kódu, a proto je

nutné využít externí úložiště.

V tomto projektu byla zvolena pamět’ W25Q256JV-DTR od společnosti Winbond. Jedná se

o sériovou NOR flash pamět’ s kapacitou 256 Mbit (32 MB), která slouží pro ukládání

firmwaru, konfiguračních dat a případně i dočasných obrazových dat.

Pamět’ komunikuje s mikrokontrolérem prostřednictvím rozhraní SPI, respektive jeho

rozšířené varianty QSPI, která umožňuje paralelní přenos dat po více datových linkách.

Díky tomu lze dosáhnout výrazně vyšších přenosových rychlostí oproti standardnímu SPI,

což je zásadní zejména při práci s obrazovými snímky.

Označení DTR (Double Transfer Rate) znamená, že data jsou přenášena na obou hranách

hodinového signálu, čímž dochází k efektivnímu zdvojnásobení propustnosti bez nut-

nosti zvyšování pracovní frekvence. Tato vlastnost přispívá ke zvýšení celkového výkonu

systému při čtení i zápisu dat.

Pamět’ je organizována do sektorů, což umožňuje efektivní mazání a zápis po blocích.

Zároveň podporuje mechanismy ochrany vybraných oblastí proti zápisu, což je výhodné

například pro zabezpečení kritických částí firmwaru.

### 3.3 Kamerový modul

Další klíčovou komponentou je kamerový modul Arducam IMX219 s rozlišením 8 Mpx.

Tento modul byl zvolen nejen s ohledem na příznivý poměr ceny a výkonu, ale také díky

své kompatibilitě a vhodnosti pro použití s mikrokontrolérem ESP32-P4.

16


Obrázek 3.1: Vybraný kamerový modul Arducam IMX219 [Zdroj: rpishop.cz]

Zde je klíčové rozhraní DSI/CSI, které umožňuje vysokorychlostní přenos obrazových dat

mezi kamerovým modulem, případně displejem, a samotným mikrokontrolérem. Využití

tohoto rozhraní je zásadní zejména kvůli vyšším přenosovým rychlostem. Pokud bychom

zvolili jiný postup, vyžadovalo by to desítky GPIO pinů, které prostě na MCU nemáme,

a navíc by to bylo velmi náročné na synchronizaci a zpracování dat.

Samotný snímač IMX219 nabízí dostatečné rozlišení pro zamýšlenou aplikaci a zároveň

podporuje různé režimy výstupu, což umožňuje optimalizovat kompromis mezi kvalitou

obrazu a objemem přenášených dat. V jednoduchosti můžeme poté přímo ve Fotaoparátu

nastavovat rozlišení výstupního snímku.

Výhodou modulu Arducam je také jeho široká podpora a dostupná dokumentace, což

usnadňuje jeho integraci do návrhu jak na hardwarové, tak i softwarové úrovni.

### 3.4 Display

Pro zobrazovací jednotku jsem zvolil 2,8” LCD modul od společnosti Waveshare, a to

především díky jeho DSI rozhraní, které je podporováno mikrokontrolérem ESP32-P4.

17


Obrázek 3.2: Vybraný 2,8” LCD modul od společnosti Waveshare [Zdroj: rpishop.cz]

Toto rozhraní umožňuje efektivní a rychlou komunikaci mezi řídicí jednotkou a displejem.

Dalším důvodem výběru tohoto konkrétního displeje byla jeho kompatibilita s mechanic-

kou konstrukcí zařízení. Pro zjednodušení návrhu jsem se rozhodl využít tělo a vybrané

periferie fotoaparátu Canon 550D. Pro účely této kapitoly postačí uvést, že původní dis-

plej z modelu 550D není vhodné použít, jelikož k němu není veřejně dostupná dostatečná

technická dokumentace. Zároveň má však velmi podobné rozměry jako zvolený Waveshare

modul, což usnadňuje jeho náhradu bez nutnosti zásadních mechanických úprav.

### 3.5 Konektor pro SD kartu

Pro ukládání dat bude použit konektor pro SD kartu, což představuje standardní řešení

úložiště u digitálních fotoaparátů. SD karty jsou kompaktní, široce rozšířené a snadno

dostupné externí médium, které nabízí dostatečné přenosové rychlosti pro zamýšlenou

aplikaci. Oproti tomu běžné USB flash disky nejsou pro tento typ zařízení tak vhodné, a

to jak z hlediska rozměrů, tak i způsobu připojení.

Alternativou by mohlo být použití pamět’ových karet typu CompactFlash. Tyto karty sice

18 teoreticky dosahují vyšších přenosových rychlostí, mimo jiné díky většímu počtu pinů,

avšak jejich nevýhodou je vyšší pořizovací cena. Dalším omezením je skutečnost, že ko-

nektory pro CompactFlash karty jsou v současnosti obtížně dostupné a často vyžadují

použití redukce. Z těchto důvodů nebylo toto řešení dále uvažováno.

3.6 Konektor pro komunikaci s počítačem.

Pro nahrávání firmwaru je na desce navržen USB-C konektor, který slouží nejen pro

samotné programování mikrokontroléru, ale také pro jeho napájení během vývoje a tes-

tování. Toto řešení výrazně zjednodušuje proces nasazení firmwaru, protože není nutné

využívat externí programátor.

19

## 4 Podrobné zapojení na desce

### 4.1 MCU

Středem celého návrhu je mikrokontrolér ESP32-P4, osazený jako hlavní výpočetní a řídicí

prvek.

Sám o sobě ale být použit nemůže. Pro jeho ideální funkci je potřeba externí flash pamět,

externí krystal a externí buck converter na 1,1 V pro napájení high power pinů.

### 4.1.1 Napájení interní SRAM paměti

Napájení interních pamět’ových a pomocných bloků MCU je řešeno samostatně.[2, 5].

Pro napájení HP pinů je použit buck converter TLV62569DBV, který je nastaven na výstupní

napětí 1,1 V, viz obrázek 4.2.

### 4.1.2 BOOT strapping a I2C

Programování zařízení je v tomto projektu navrženo pouze přes USB. Mikrokontrolér

sice obecně umožňuje i programování přes UART, tato možnost však v daném návrhu

není využita. Pro vstup do programovacího režimu je osazeno tlačítko SW1, připojené

k GPIO 35. Strapping piny se čtou během bootování a určují spouštěcí režim MCU.

Tlačítko S1 slouží k aktivaci Joint Download Boot módu pro nahrávání firmwaru — při

jeho stisku během startu se MCU spustí v režimu, který umožňuje download nového kódu

přes USB. Podrobněji jsou bootovací režimy a jejich konfigurace strapping pinů uvedeny

v tabulce 4.1.

20


Obrázek 4.1: ESP32-P4 v eschématu [Zdroj: Vlastní]


Obrázek 4.2: Schména zapojení měniče pro napájení HP pinů [Zdroj: Vlastní]

21


Obrázek 4.3: Zapojení kolem ESP32-P4 popsané v této sekci: I2C pull-upy, reset a startovací vazby. [Zdroj: Vlastní]

22

Boot Mode | GPIO35 | GPIO36 | GPIO37 | GPIO38
SPI Boot mode (default)¹ | 1 | x | x | x
Joint Download Boot mode² | 0 | 1 | x | x
SPI Download Boot mode³ | 0 | 0 | 0 | 1
Invalid Combination⁴ | 0 | 0 | 0 | 0

Tabulka 4.1: BOOT režimy dle kombinace strapping pinů ESP32-P4 [Zdroj: [5]]

Na obrázku 4.3 je zachycena pravá část MCU, kde se nachází BOOT strapping piny (GPIO 35–38) [5], interní regulátor pro napájení Flash a SRAM pamětí (VDD LDO).

Dále je na obrázku 4.3 zachyceno I2C rozhraní, připojené k pinům GPIO 30 a 31. Kvůli

designu samotné sběrnice, kde zařízení pouze ”

tahá” napětí na logickou nulu, jsou zde osazeny pull-up rezistory R14 a R15 (oba 4,7 kΩ).

### 4.1.3 Externí krystal

Hodinový systém je doplněn externím 40MHz krystalem a dvojicí zátěžových kondenzátorů podle doporučení výrobce[2, 4]. Tato část má přímý vliv na stabilní start systému i

na přesnost časování vysokorychlostních periferií. Bez tohoto krystalu by kamera ne-

mohla spolehlivě fungovat, protože by nebylo možné zajistit stabilní taktování pro zpra-

cování obrazových dat. Na obrázku 4.4 je znázorněno zapojení 40MHz krystalu Y1 a jeho

podpůrných součástek. Kondenzátory C59 a C63 mají hodnotu 12 pF anastavují správnou

zátěž a stabilitu oscilátoru. Sériový odpor R27 o hodnotě 22 Ω slouží k tlumení kmitů

a pomáhá omezit rušení. Krysatal by měl výt osazen ve vzdálenosti alespoň 4,5 mm od MCU[5], aby se zabránilo rušení.

Podrobnější informace o doporučeném zapojení napájecích domén a startovacích podmínkách uvádí datasheet a technický referenční manuál výrobce[5, 4].

23


Obrázek 4.4: Zapojení externího krystalu v eschématu. [Zdroj: Vlastní]

### 4.2 Napájení periférií

Napájecí část je navržena pro provoz z jednoho akumulátoru 7,2 V a je rozdělena do několika samostatných větví podle typu zátěže[3]. Ve schématu jsou osazeny měniče

CONV1 (AP63203WU, pevný výstup 3,3 V), CONV2 (AP63200WU, nastavený na 5,5 V

pro komunikaci s objektivem) a CONV4 (AP63200WU, nastavený na 6 V pro obsluhu servo

motorů v objektivu)[1, 2].

Měnič CONV1 s obvodem AP63203WU vytváří hlavní větev 3,3 V. Na jeho vstupu jsou

oddělovací diody D1 a D4, které umožňují napájení jak z větve +7V2 z akumulátoru, tak z USB +5V. Na vstupu jsou také kondenzátory C6 (100 nF) a C7 (10 µF), na výstupu

pak C9 a C10 (oba 22 µF), tlumivka L1 (3,9 µH), bootstrap kondenzátor C8 (100 nF)

a zenerova dioda D6 (3,6 V). Toto řešení je uvedeno na obrázku 4.5. Díky němu může

zařízení v omezeném režimu běžet i pouze z USB, ale bez napájení a bez komunikace

objektivu nebude dostupné nastavování clony ani autofocus.

Měnič CONV2 s obvodem AP63200WU je nastaven na výstup 5,5 V pro napájení logiky objektivu. Na vstupu jsou kondenzátory C43 (100 nF) a C44 (10 µF), na výstupu tlumivka

L3 (10 µH), kondenzátory C46 a C47 (oba 22 µF), bootstrap kondenzátor C45 (100 nF) a

zenerova dioda D2 (5,7 V). Rezistory pro nastavení výstupního napětí jsou vybrány podle

24


Obrázek 4.5: Měnič na 3,3 V v eschématu [Zdroj: Vlastní]

rovnice 4.1 poskytnuté výrobcem:

R1 = R2 ·

VOUT
0.8V

− 1

(4.1)

Toto zapojení je zachyceno na obrázku 4.6.

Měnič CONV4 (AP63200WU) je v zapojení použit jako samostatná větev pro napájení hlavních pohonů v objektivu, s výstupním napětím cca 6 V. Na vstupu (sít’ +7V2) jsou

kondenzátory C48 (100 nF) a C49 (10 µF) pro odrušení; spínací stupeň používá bootstrap

kondenzátor C50 (100 nF) a za ním následuje tlumivka L4 (10 µH). Výstupní filtrace tvoří

kondenzátory C51 a C52 (oba 22 µF). Nastavení výstupního napětí realizuje dělič R7/R6

(R7 = 100 kΩ na výstupu, R6 = 16 kΩ k zemi) osazený podle rovnice 4.1, čímž se dosahuje

cílové hodnoty 6 V. Pro finální vyhlazení je zapojena zenerova dioda D3 (6,2 V). Toto

zapojení je zobrazeno na obrázku 4.7.

25


Obrázek 4.6: Zapojení měniče napětí pro komunikaci s objektivem [Zdroj: Vlastní]

Obrázek 4.7: Zapojení měniče napětí pro obsluhu servo motorů v objektivu [Zdroj: Vlastní]

26

### 4.3 Externí Flash pamět’

Externí flash pamět’ je osazena jako samostatný nevolatilní prostor pro firmware a provozní

data[6, 2]. Připojení je řešeno přes QSPI, aby byla zajištěna dostatečná propustnost při

startu systému i při běhu aplikace.

Ve schématu je osazena pamět’ ESP FLASH1 typu W25Q256JVEIQ. Stabilitu této části

zajišt’uje zejména důraz na velmi nízké odchylky mezi jednotlivými cestami. To je důležité

zejména kvůli vysokým přenosovým rychlostem. Schéma zapojení a n8vrh routování této

části jsou zobrazeny na obrázku 4.8. Všimněte si, že všechny cesty jsou vedeny v jedné

vrstvě, jsou co nejkratší a mají stejné délky vyladěné pomocí tzv. ”

meandrů“ . Díky tomu

je minimalizováno riziko ztráty dat kvůli rušení nebo odrazům signálu.

### 4.4 Konektory pro připojení periférií

### 4.4.1 Konektor pro zapojení kamerového modulu

Kamerový modul je připojen přes 15pinový FFC konektor. Vedeny jsou diferenciální páry

MIPI CSI, řídicí sběrnice I2C, napájení a řídicí signály pro zapnutí modulu. Stejně jako

u Flash paměti je důležité dbát na symetrii délek cest a jejich tvar pro zabránění rušení.

Text této části je záměrně veden obecně na úrovni použitého rozhraní a zapojení. Konkrétní

parametry obrazového snímače je vždy nutné vztáhnout k reálně osazenému kamerovému

modulu. Je tedy možné použít kamerový modul se stejným pinoutem, ale s jinými para-

metry, a to i bez nutnosti úprav v zapojení. Naopak použití modulu s jiným pinoutem by

vyžadovalo zásadní úpravy v zapojení i v softwaru.

### 4.4.2 Konektor pro zapojení displaye

Displej je připojen přes samostatný 15pinový FFC konektor. Na tomto rozhraní jsou

vyvedeny MIPI DSI páry pro obrazová data a pomocné signály I2C pro obsluhu dotykové

27


Obrázek 4.8: Zapojení externí flash paměti v eschématu a v PCB editoru. [Zdroj: Vlastní]

28


Obrázek 4.9: Zapojení konektoru pro připojení kamerového modulu IMX219. [Zdroj: Vlastní]

29


Obrázek 4.10: Zapojení konektoru pro připojení displeje v eschématu. [Zdroj: Vlastní]

vrstvy[2, 8].

I zde je nutné dbát na délkovou symetrii cest a jejich tvar, aby se minimalizovalo rušení

a ztráta dat při přenosu obrazových informací.

30


Obrázek 4.11: Návrh pro zapojení konektoru pro připojení kamery (vlevo) a displaye (vpravo). [Zdroj: Vlastní]


Obrázek 4.12: Zapojení slotu pro SD kartu v eschématu. [Zdroj: Vlastní]

### 4.4.3 Dock pro umístění SD karty

Pro ukládání snímků je osazen konektor pro MicroSD kartu[2]. Kromě datových linek je

využita i detekce vložení karty, což zjednodušuje obsluhu v softwaru a snižuje riziko zápisu

na neosazené médium.

31

### 4.4.4 Konektory pro tlačítka ovládání

Pro připojení ovládacích tlačítek jsou navrženy dva konektory, které umožňují připojení jak hlavního ovládacího rozhraní (pro nastavení parametrů a navigaci v menu), tak i sa-

mostatného tlačítka spouště. Ovládací tlačítka, a k tomu indikační červená led dioda, jsou

připojena k GPIO 42–52. Celá tato deska byla recyklována z rozbraného modelového fo-

toaparátu Canon 550D. Tlačíko spouště je stejného původu, ale je připojeno samostatně

kvůli své specifické funkci a umístění v konstrukci zařízení. Kvůli komplikovanému za-

pojení na původní desce 550D je nutné připojit tlačítko spouště samostatně na plošném

spoji vlastní výroby, proto je na návrhu osazen samostatný konektor pro tento účel.

### 4.5 Převodník logických úrovní pro komunikaci s objektivem

Pro komunikaci s objektivem Canon EF je osazen obousměrný převodník logických úrovní TXS0108EPW[12, 13]. Důvodem je rozdíl mezi logikou mikrokontroléru a úrovněmi na straně

objektivu.

Z dostupných měření vyplývá, že část EF signálů není spolehlivá při 3,3V úrovni, proto je oddělení napět’ových domén v této části nezbytné[13, 14].

### 4.6 USB-C USB 2.0 konektor

Datové a servisní rozhraní je řešeno přes USB-C v režimu USB 2.0[2, 15]. Rozhraní slouží

pro programování firmwaru, ladění i napájení během vývoje.

Na CC pinech jsou osazeny pull-down rezistory (Rd) pro indikaci zařízení; v našem návrhu

jsou to R9 a R1 (5.1 kΩ) k zemi, což signalizuje hostu, že jde o device. Datové linky D+ a

D− jsou chráněny ESD/TVS součástí (ESDA6V1U1RL) a mohou být vedeny přes common-

mode choke pro lepší EMI/EMC potlačení. SBU piny nejsou v návrhu využity.

V kombinaci s nativní podporou USB v ESP32-P4 toto řešení výrazně zjednodušuje oživení i další vývoj[4, 16].

32


Obrázek 4.13: Zapojení konektorů pro připojení ovládacích tlačítek v eschématu. Nahoře hlavní olvádací rozhraní, dole tlačítka spouště Fotaoparátu. [Zdroj: Vlastní]

33


Obrázek 4.14: Zapojení převodníku logických úrovní pro komunikaci s objektivem v eschématu. [Zdroj: Vlastní]

Obrázek 4.15: Zapojení USB-C konektoru v eschématu. [Zdroj: Vlastní]

34

## 5 Plánované oživení a konstrukce

Praktické oživení hardwaru a dokončení mechanické konstrukce nebyly dokončeny do termínu uzávěrky, nebot’ jsem přecenil své síly a podcenil časový limit. Následující části

proto popisují plánované kroky a doporučený postup pro systematické oživení a dokončení

návrhu mechaniky.

### 5.1 Plánované oživení

Pro úspěšné softwarové oživení desky je třeba připravit konzistentní vývojové prostředí,

automatizované nástroje pro flashování a sběr logů a repozitář s minimálním testovacím firmwarem. V praxi to znamená nastavit toolchain a build systém (např. ESP-IDF nebo

jiný zvolený framework) a zajistit stabilní verze kompilátorů a utilit, připravit skripty pro

pohodlné flashování přes USB a zachytávání sériového výstupu (UART/USB logging) a

mít v repozitáři konfiguraci buildu spolu s jednoduchým testovacím obrazem (např. mini-

mal boot image nebo ”

blinky“) pro rychlé ověření hardwaru. Po této přípravě následuje

vlastní sekvence bring-upu: nejprve se nahraje bootloader a velmi jednoduchý firmware,

který pouze inicializuje periférie a posílá základní diagnostické zprávy přes sériovou linku.

Na základě těchto logů ověříme boot sekvenci, přítomnost a verze paměti a dosažitelnost

důležitých pinů. Dále firmware krokově rozšiřujeme o inicializaci hodinového systému a

QSPI rozhraní tak, aby bylo možné korektně číst z externí flash paměti.

Následují kroky zaměřené na periferie vyšší úrovně: přidání a otestování ovladače SD karty a připojení souborového systému (např. FAT) s ověřením čtení a zápisu souborů,

integrace ovladače displeje s jednoduchým vykreslením testovacího obrazu a následně integrace ovladače kamery/CSI — nejprve přes I2C inicializovat senzor a poté spustit

jednoduchý capture, uložit snímek do paměti a ověřit jeho zápis na SD nebo přenos přes

USB.

35

Během celého procesu je vhodné zavést jednoduchou diagnostiku ve firmwaru (watchdog,

zdravotní telemetrie, detekce chyb) a zajistit možnost bezpečného aktualizačního mecha-

nismu (OTA nebo flash přes USB) pro případ rychlých oprav. Pro opakované ověření

se připraví automatizované testovací skripty: smoke test pro boot a základní I/O, sady

testů pro QSPI/SD/I2C a funkční scénáře zahrnující pořízení snímku a jeho zobrazení či

uložení.

Do ověřovacích metrik softwarového oživení patří především úspěšný boot bez kritických

chyb, schopnost číst a zapisovat do externí paměti a SD karty, stabilita karetní a kamerové komunikace (latence a propustnost) a spolehlivost aktualizačního procesu. Tyto body

by měly být zachyceny v jednoduchých testovacích protokolech, které umožní opakovat

ověření i po případných hardwarových úpravách.

### 5.2 Plánovaná konstrukce

Z důvodu komplexity mechanické konstrukce bajonetu, který bych sám nemohl udělat pro

bezpečné uchycení objektivu, jsem se rozhodl využít tělo a vybrané periferie z modelu

Canon 550D. Toto řešeení jsem si vybral jako spíše dočasné, jelikož by umožnilo rychlejší

vývoj a oživení. V budoucnu bych rád navrhl vlastní mechanickou konstrukci, jelikož je

potřeba brát v úvahu i tzv. flange, neboli vzdálenost mezi bajonetem a snímačem, která

je u Canon EF 44 mm. Proto mám v plánu vytořit vlastní tělo Fotaoparátu, s vnořeným

bajonetem EF.

36


Obrázek 5.1: Cásti rozebraného těla fotoaparátu Canon 550D vybrané ke konstrukci. ˇ [Zdroj: Vlastní]

Obrázek 5.2: Bajonet z modelu Canon 550D, který bude použit pro uchycení objektivu. [Zdroj: Vlastní]

37

## Závěr

Systém pro mikrokontrolérový fotoaparát založený na ESP32-P4 jsem bohužel nestihl

dokončit. Dokončený úsek práce tvoří detailní návrh schémat, volba klíčových komponent (externí QSPI flash, kamerový modul, DSI displej, napájecí měniče), návrh konektorů a pomocných obvodů (USB-C, SD, převodník napět’ových úrovní) a příprava počátečního

firmwaru pro bring-up.

Co se podařilo: většina schémat a návrhů byla dokončena a zdokumentována včetně poznámek k routování kritických QSPI/CSI/DSI cest. Byl připraven plán oživení s kro-

kovým postupem pro ověření bootu, QSPI, SD, displeje a kamery. Také jsem identifikoval klíčová rizika a navrhl opatření (vyrovnání délek, přídavná filtrace, ochrana proti ESD),

která je třeba ověřit při bring-upu.

Co zůstalo nedokončeno: finální DRC a doladění napájecích filtrací a odrušení, kompletní

mechanická integrace a sériové funkční testování na prototypu. Tyto nedostatky pramenily

hlavně z nutnosti opakovaných úprav schématu a z časové náročnosti ladění HF signálů.

Další postup: nejprve dokončit DRC a optimalizovat routování kritických signálů (vy-

rovnání délek, kontrola impedance, případné stínění), poté provést zátěžové testy napájení

a doladit filtry. Následně postupný bring-up: ověření bootloaderu a QSPI, integrace SD

a souborového systému, inicializace displeje a nakonec integrace kamery s ukládáním

snímků. Pro mechanické ověření doporučuji dočasné použití těla Canon 550D, které

urychlí ladění, a po ověření navrhnout finální konstrukci.

Výstupem této fáze jsou jasné, zdokumentované kroky a opatření, která umožní systema-

tické dokončení oživení. Získané zkušenosti s návrhem HF rozhraní, řízením napájení a

integrací periferií poskytují pevný základ pro další vývoj firmwaru, přidání uživatelského

rozhraní a zavedení spolehlivého aktualizačního mechanismu.

38

## Literatura

[1] DIODES INCORPORATED. AP63200/AP63201/AP63203/AP63205 – Buck Con-

verter Datasheet. Dostupné z: https://www.diodes.com/assets/Datasheets/

AP63200-AP63201-AP63203-AP63205.pdf. (https://www.diodes.com/assets/Datasheets/AP63200-AP63201-AP63203-AP63205.pdf) [cit. 2026-04-23].

[2] HOVORKA, V. Projektové schéma v KiCadu (fotaoparát.kicad sch, power.kicad sch,

peripherals.kicad sch). Lokální projektová dokumentace, 2026.

[3] HOVORKA, V. RP-Hovorka/readme.md – hardware TODO a napájecí větve. Lokální

projektová dokumentace, 2026.

[4] ESPRESSIF SYSTEMS. ESP32-P4 Datasheet. Lokální soubor: datasheeshty/Esp32-

p4 datasheet en.pdf, 2026.

[5] ESPRESSIF SYSTEMS. ESP32-P4 Technical Reference Manual. Lokální soubor:

datasheeshty/Esp32-p4 technical reference manual en.pdf, 2026.

[6] WINBOND. W25Q256JV – Serial NOR Flash Datasheet. Lokální soubor: datashee-

shty/w25q256jv dtr revc 10252016.pdf, 2016.

[7] RPI | SHOP | CZ. | Arducam | IMX219 | 8 | MPx | kame-
rový | modul. | Dostupné | z: | https://rpishop.cz/635962/

arducam-imx219-8-mpx-kamerovy-modul-s-objektivem-m12-ls1820-noir/. (https://rpishop.cz/635962/arducam-imx219-8-mpx-kamerovy-modul-s-objektivem-m12-ls1820-noir/) [cit. 2026-04-23].

[8] WAVESHARE. 2.8inch DSI LCD – Product Page. Dostupné z: https://www.

waveshare.com/product/displays/2.8inch-dsi-lcd.htm. [cit. 2026-04-23].

[9] WAVESHARE. 2.8inch DSI LCD – Wiki. Dostupné z: https://www.waveshare.

com/wiki/2.8inch_DSI_LCD. (https://www.waveshare.com/wiki/2.8inch_DSI_LCD) [cit. 2026-04-23].

[10] HIROSE ELECTRIC. DM3 Series – MicroSD Card Connector Catalog. Dostupné
z: | https://www.hirose.com/en/product/document?clcode=&productname=
| | | | | | | 39 (https://www.hirose.com/en/product/document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)

&series=DM3&documenttype=Catalog&lang=en&documentid=D49662_en. (https://www.hirose.com/en/product/document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) | [cit.

2026-04-23].

[11] STMICROELECTRONICS. ESDA6V1U1RL – ESD Protection Device. Dostupné
z: | https://lcsc.com/product-detail/Diodes-ESD_STMicroelectronics_

ESDA6V1U1RL_ESDA6V1U1RL_C118278.html. (https://lcsc.com/product-detail/Diodes-ESD_STMicroelectronics_ESDA6V1U1RL_ESDA6V1U1RL_C118278.html) [cit. 2026-04-23].

[12] TEXAS INSTRUMENTS. TXS0108E – 8-Bit Bidirectional Voltage-Level Transla-

tor. Dostupné z: https://www.ti.com/lit/ds/symlink/txs0108e.pdf. [cit. 2026-

04-23].

[13] HECTOR, | M. | software/canon-ef-protocol-notes.md. | Dostupné | z: | https:

//gist.github.com/marcan/858c242db2fc595da1e0bb70a05192fc# file-canon-ef-protocol-notes-md (https://gist.github.com/marcan/858c242db2fc595da1e0bb70a05192fc#file-canon-ef-protocol-notes-md) (reverse engineering EF sběrnice), 2026.

[14] MAGIC LANTERN TEAM. Magic Lantern. Dostupné z: https://www.

magiclantern.fm. [cit. 2026-04-23].

[15] USB IMPLEMENTERS FORUM. USB Type-C Specification. Dostupné z: https:

//www.usb.org/sites/default/files/documents/usb_type-c.zip. [cit. 2026-04-

23].

[16] ESPRESSIF SYSTEMS. ESP32-P4 Product Overview. Dostupné z: https://www.

espressif.com/en/products/socs/esp32-p4. [cit. 2026-04-23].

40

## Přílohy

I

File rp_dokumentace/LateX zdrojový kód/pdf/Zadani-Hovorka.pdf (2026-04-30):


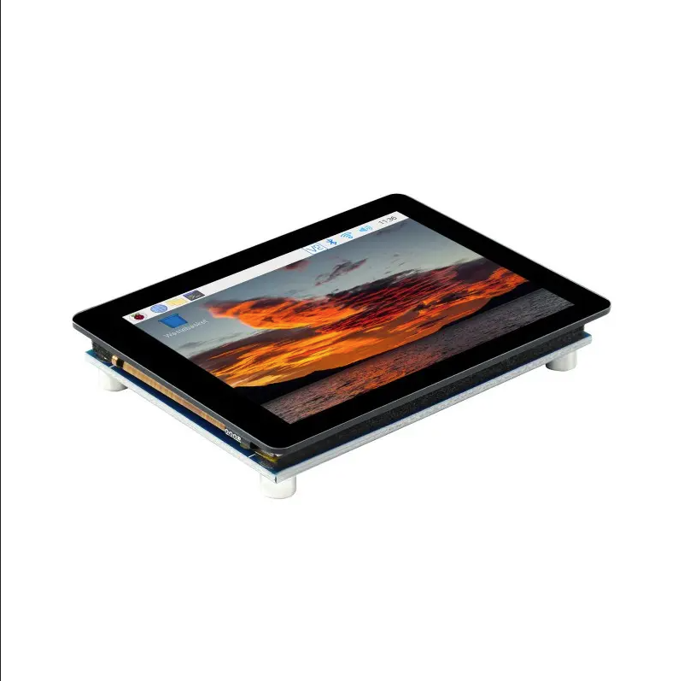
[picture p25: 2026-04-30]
rp_dokumentace/LateX zdrojový kód/pictures/waveshare.png

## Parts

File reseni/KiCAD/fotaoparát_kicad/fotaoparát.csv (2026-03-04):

Reference | Qty | Value | DNP | Exclude from BOM | Exclude from Board | Footprint | Datasheet
BAT_IN1,BAT_OUT1 | 2 | Conn_01x01_Socket |  |  |  | Connector_Wire:SolderWirePad_1x01_SMD_1.5x3mm | ~
C1,C2 | 2 | 0,1uF |  |  |  | Capacitor_SMD:C_0201_0603Metric | ~
C3,C30,C33,C34 | 4 | 10uF |  |  |  | Capacitor_SMD:C_0201_0603Metric | ~
C4,C11,C13,C29,C53,C54,C55,C56,C57,C58,C60,C61,C62 | 13 | 100nF |  |  |  | Capacitor_SMD:C_0201_0603Metric | ~
C6,C8,C43,C45,C48,C50 | 6 | 100n |  |  |  | Capacitor_SMD:C_0603_1608Metric | ~
C7,C44,C49 | 3 | 10uF |  |  |  | Capacitor_SMD:C_0603_1608Metric | ~
C9,C10,C46,C47,C51,C52 | 6 | 22uF |  |  |  | Capacitor_SMD:C_0603_1608Metric | ~
C12,C25,C26,C28 | 4 | 1uF |  |  |  | Capacitor_SMD:C_0201_0603Metric | ~
C16,C17,C18,C19,C20,C21,C22,C23,C24,C27,C31,C32,C35,C36,C38,C39 | 16 | 0.1uF |  |  |  | Capacitor_SMD:C_0201_0603Metric | ~
C37,C40 | 2 | 10pF |  |  |  | Capacitor_SMD:C_0201_0603Metric | ~
CAM_IN1 | 1 | Conn_01x15_Pin |  |  |  | Connector_FFC-FPC:Hirose_FH12-15S-0.5SH_1x15-1MP_P0.50mm_Horizontal | ~
CONV1 | 1 | AP63203WU |  |  |  | Package_TO_SOT_SMD:TSOT-23-6 | https://www.diodes.com/assets/Datasheets/AP63200-AP63201-AP63203-AP63205.pdf
CONV2,CONV4 | 2 | AP63200WU |  |  |  | Package_TO_SOT_SMD:TSOT-23-6 | https://www.diodes.com/assets/Datasheets/AP63200-AP63201-AP63203-AP63205.pdf
D1,D4 | 2 | D_Schottky |  |  |  | Diode_SMD:D_0805_2012Metric | ~
D2,D3,D6 | 3 | 3v6 Zener |  |  |  | Diode_SMD:D_SOD-123 | ~
DISPLAY_IN1 | 1 | Conn_01x15_Socket |  |  |  | Connector_FFC-FPC:Hirose_FH12-15S-0.5SH_1x15-1MP_P0.50mm_Horizontal | ~
ESD_PROT1 | 1 | ESDA6V1U1RL |  |  |  | stlib:SO-8_L4.9-W3.9-P1.27-LS5.9-BL | https://lcsc.com/product-detail/Diodes-ESD_STMicroelectronics_ESDA6V1U1RL_ESDA6V1U1RL_C118278.html
ESP32_P4 | 1 | ~ |  |  |  | PCM_Espressif:ESP32-P4
ESP_FLASH1 | 1 | W25Q256JVEIQ |  |  |  | PCM_SamacSys_Parts:SON127P800X600X80-9N-D | https://www.winbond.com/hq/search-resource-file.jsp?partNo=W25Q256JVEIQ&type=datasheet
J1 | 1 | Conn_01x08_Pin |  |  |  | Connector_FFC-FPC:Amphenol_F32Q-1A7x1-11008_1x08-1MP_P0.5mm_Horizontal | ~
J4 | 1 | BUTTONS |  |  |  | Connector_FFC-FPC:Hirose_FH12-12S-0.5SH_1x12-1MP_P0.50mm_Horizontal | ~
J13 | 1 | Micro_SD_Card_Det2 |  |  |  | Connector_Card:microSD_HC_Hirose_DM3BT-DSF-PEJS | https://www.hirose.com/en/product/document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
L1,L3,L4 | 3 | 4,7uH |  |  |  | Inductor_SMD:L_0603_1608Metric | ~
LOGIC_CONVERT1 | 1 | TXS0108EPW |  |  |  | Package_SO:TSSOP-20_4.4x6.5mm_P0.65mm | www.ti.com/lit/ds/symlink/txs0108e.pdf
R1,R9 | 2 | 5k1 |  |  |  | Resistor_SMD:R_0603_1608Metric | ~
R2 | 1 | 47k |  |  |  | Resistor_SMD:R_0603_1608Metric | ~
R3 | 1 | 270k |  |  |  | Resistor_SMD:R_0603_1608Metric | ~
R4,R5 | 2 | 4.02k |  |  |  | Resistor_SMD:R_0603_1608Metric | ~
R6 | 1 | 16k |  |  |  | Resistor_SMD:R_0603_1608Metric | ~
R7 | 1 | 100k |  |  |  | Resistor_SMD:R_0603_1608Metric | ~
R8 | 1 | 330R |  |  |  | Resistor_SMD:R_0603_1608Metric | ~
R10,R11,R12,R15,R16,R17,R18,R19,R20,R21,R22,R23 | 12 | 10k |  |  |  | Resistor_SMD:R_0603_1608Metric | ~
R13,R14 | 2 | 4k7 |  |  |  | Resistor_SMD:R_0603_1608Metric | ~
SW1,SW2 | 2 | SW_MEC_5G |  |  |  | Button_Switch_SMD:SW_Push_1P1T_NO_CK_KMR2 | http://www.apem.com/int/index.php?controller=attachment&id_attachment=488
U1 | 1 | TLV62569DBV |  |  |  | Package_TO_SOT_SMD:SOT-23-5 | http://www.ti.com/lit/ds/symlink/tlv62569.pdf
USB-C_2.0 | 1 | USB_C_Receptacle_USB2.0_16P |  |  |  | Connector_USB:USB_C_Receptacle_Palconn_UTC16-G | https://www.usb.org/sites/default/files/documents/usb_type-c.zip
Y2 | 1 | Crystal_GND23 |  |  |  | Crystal:Crystal_SMD_Abracon_ABM8G-4Pin_3.2x2.5mm | ~

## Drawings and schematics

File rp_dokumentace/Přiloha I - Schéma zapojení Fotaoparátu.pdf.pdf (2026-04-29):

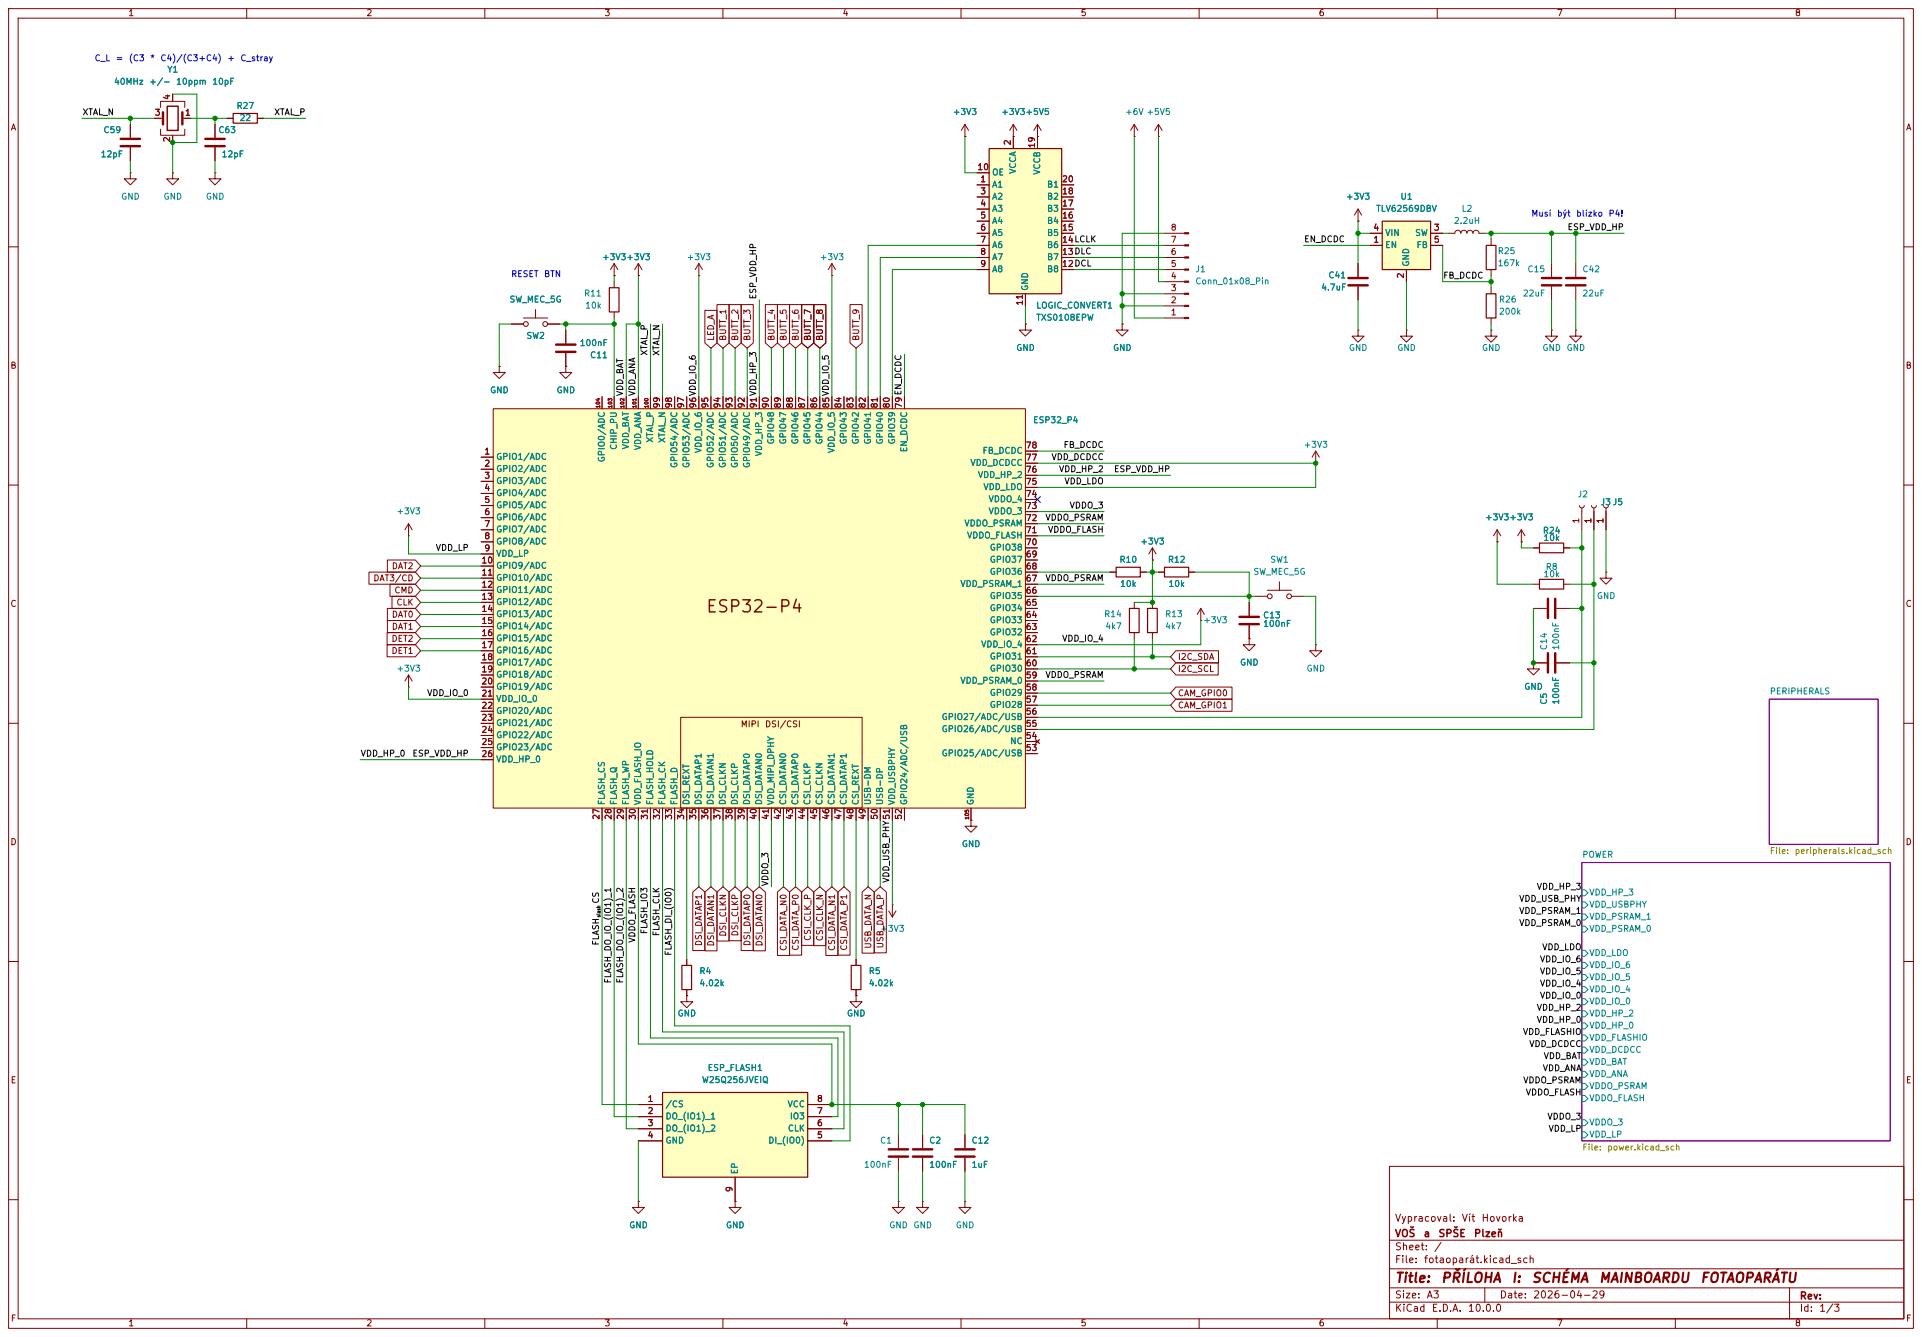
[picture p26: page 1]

Musí být blízko P4! RESET BTN

Vypracoval: Vít Hovorka
VOŠ a SPŠE Plzeň
Sheet: /
File: fotaoparát.kicad_sch
Title: PŘÍLOHA I: SCHÉMA MAINBOARDU FOTAOPARÁTU

Size: A3 | Rev: | F Date: 2026-04-29 KiCad E.D.A. 10.0.0

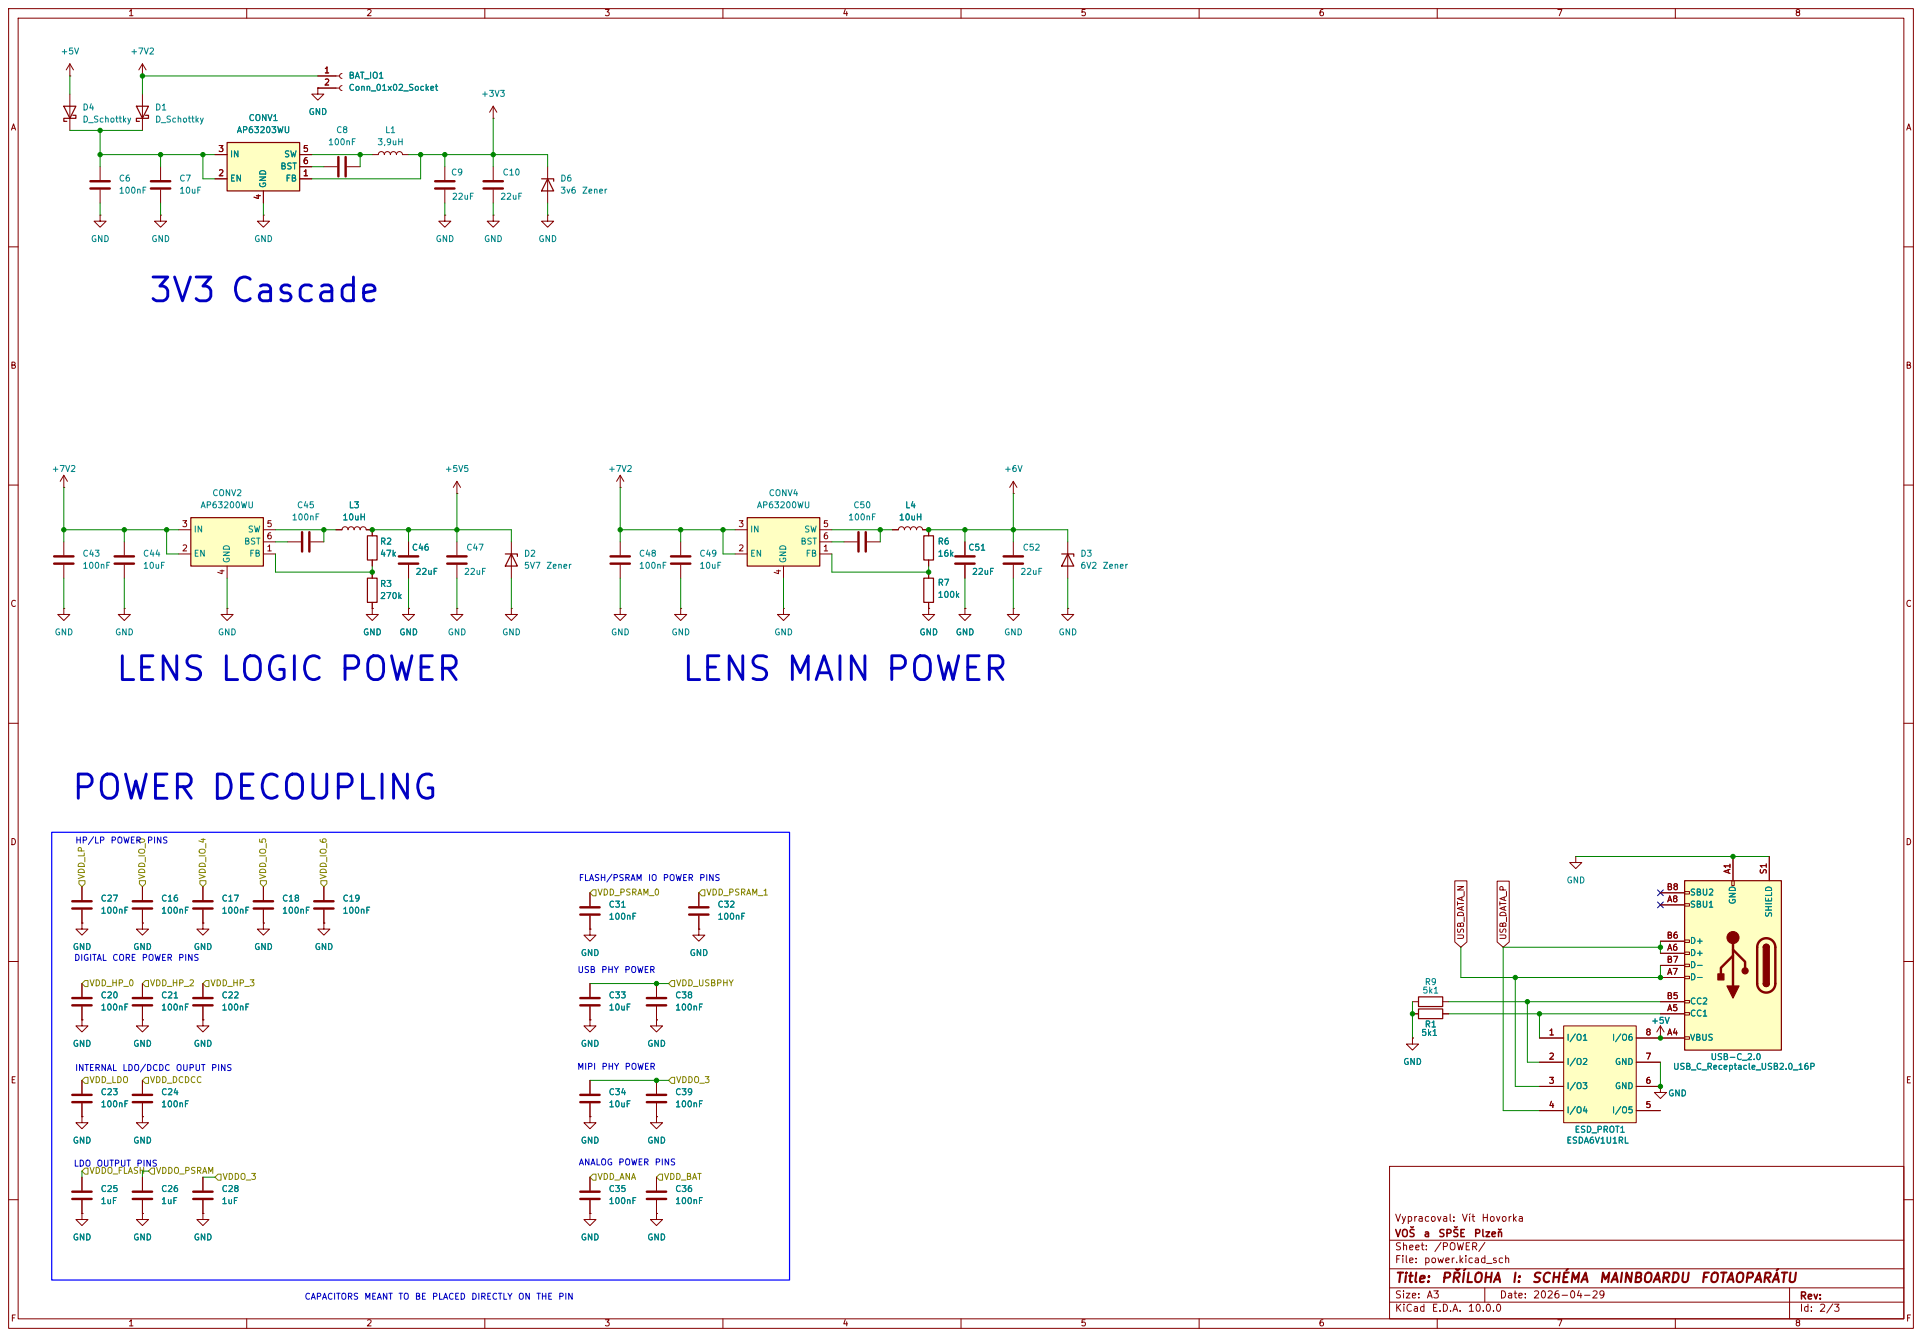
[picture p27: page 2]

MIPI PHY POWER LENS LOGIC POWER

ANALOG POWER PINS POWER DECOUPLING

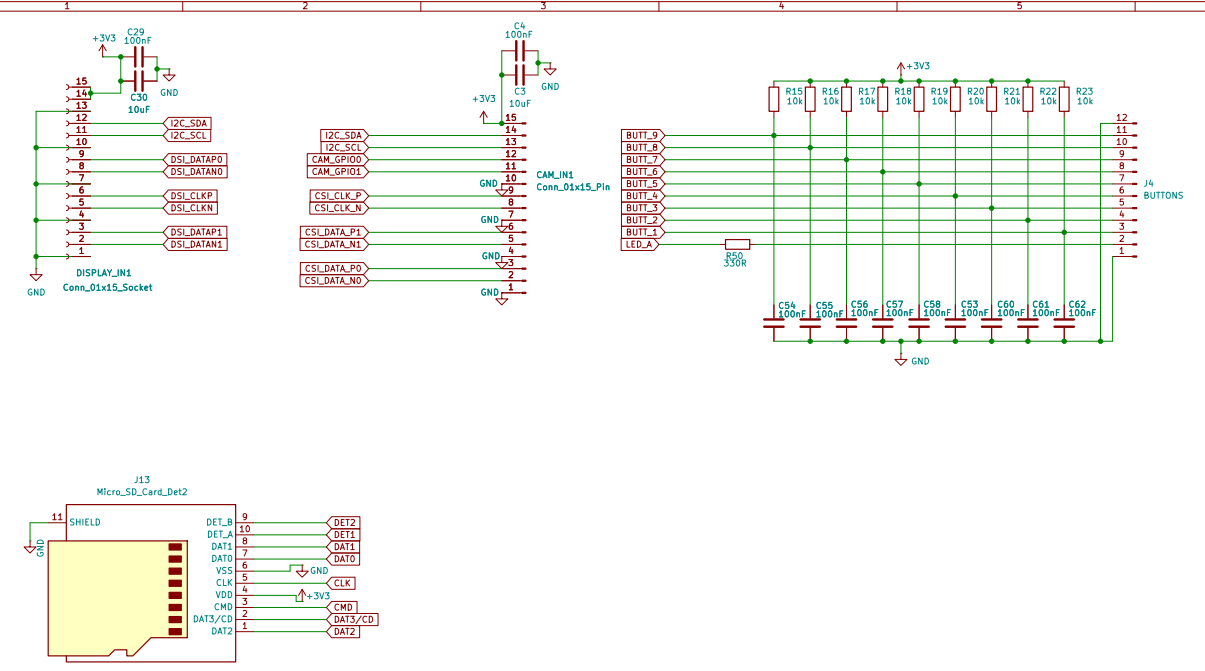
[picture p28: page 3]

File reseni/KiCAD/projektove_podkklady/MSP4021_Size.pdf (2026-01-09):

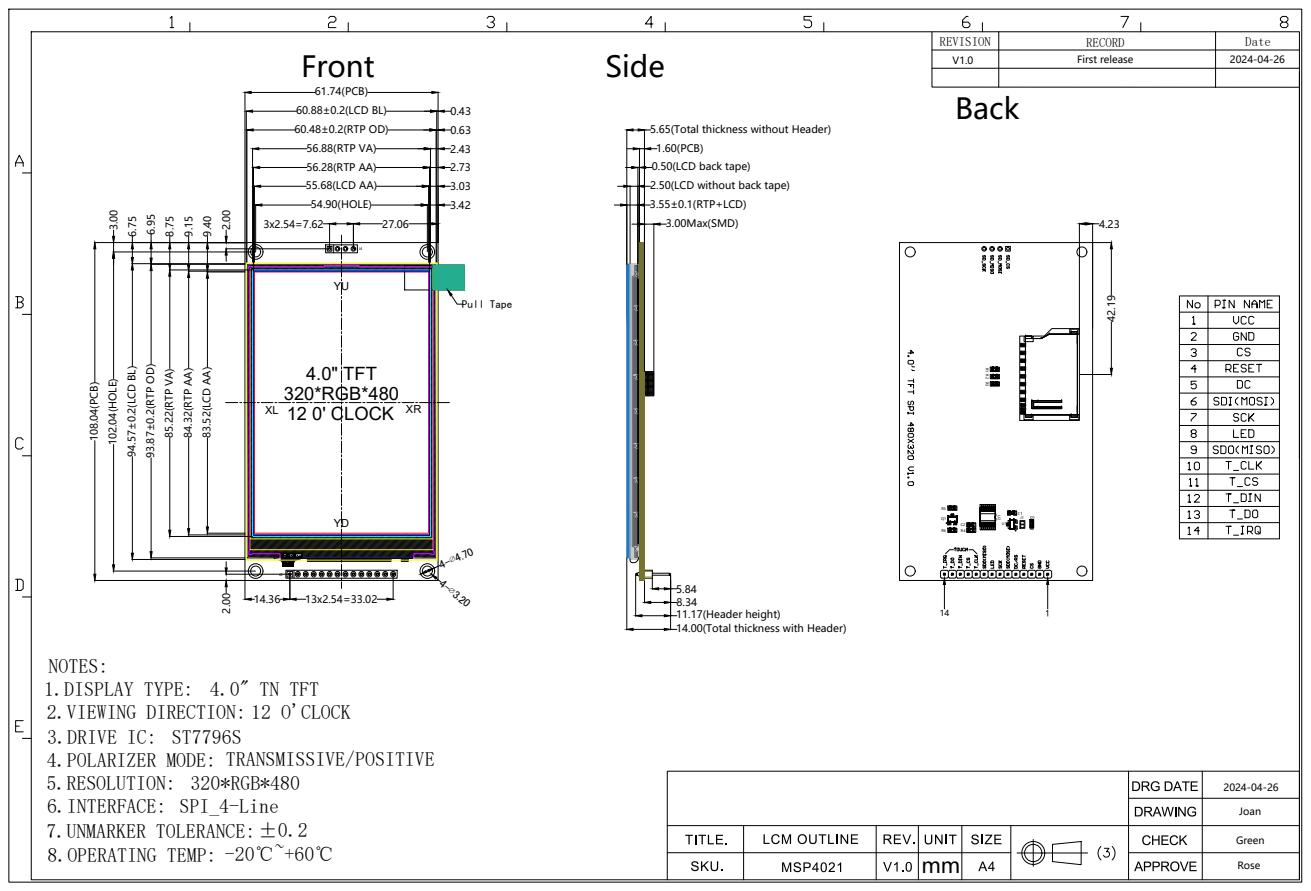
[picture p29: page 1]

9.40 14.36 4.0" TFT 320*RGB*480 12 0' CLOCK 5.84 8.34 11.17(Header height) 14.00(Total thickness with Header) 3.55±0.1(RTP+LCD) 2.50(LCD without back tape) 0.50(LCD back tape) 1.60(PCB) 5.65(Total thickness without Header) Front Side Back YU XL XR YD J2 J4 56.28(RTP AA) 2.43 0.63 0.43

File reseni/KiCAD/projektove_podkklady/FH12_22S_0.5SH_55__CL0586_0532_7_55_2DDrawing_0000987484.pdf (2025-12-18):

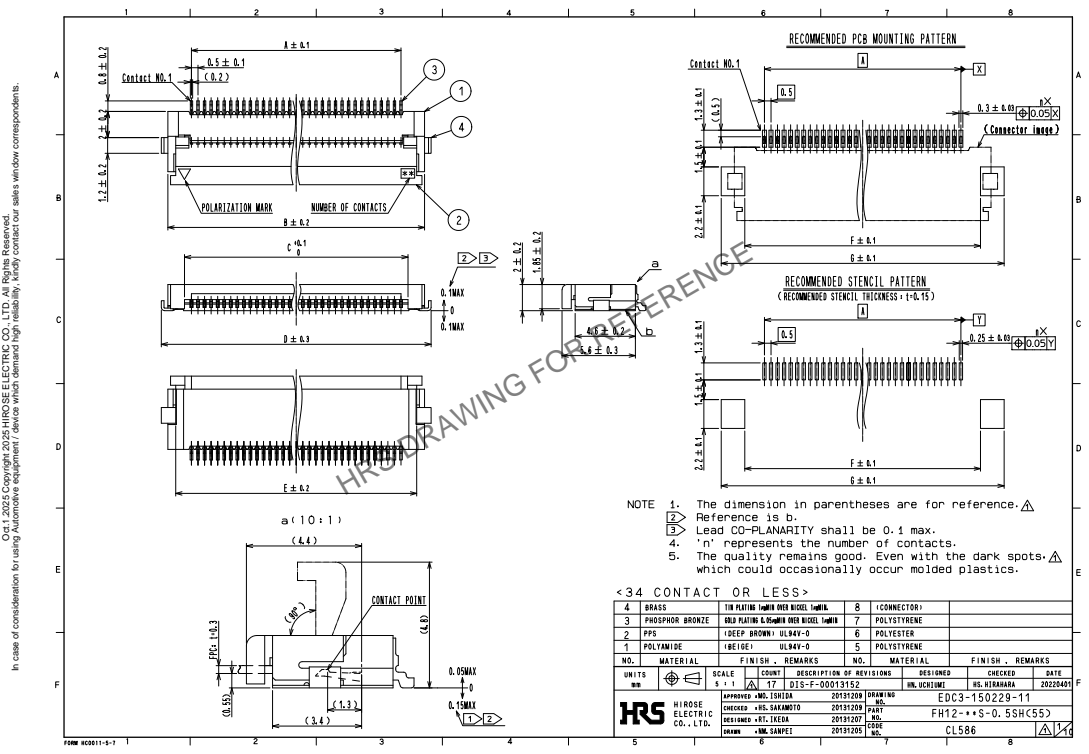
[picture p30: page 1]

HRS DRAWING FOR REFERENCE

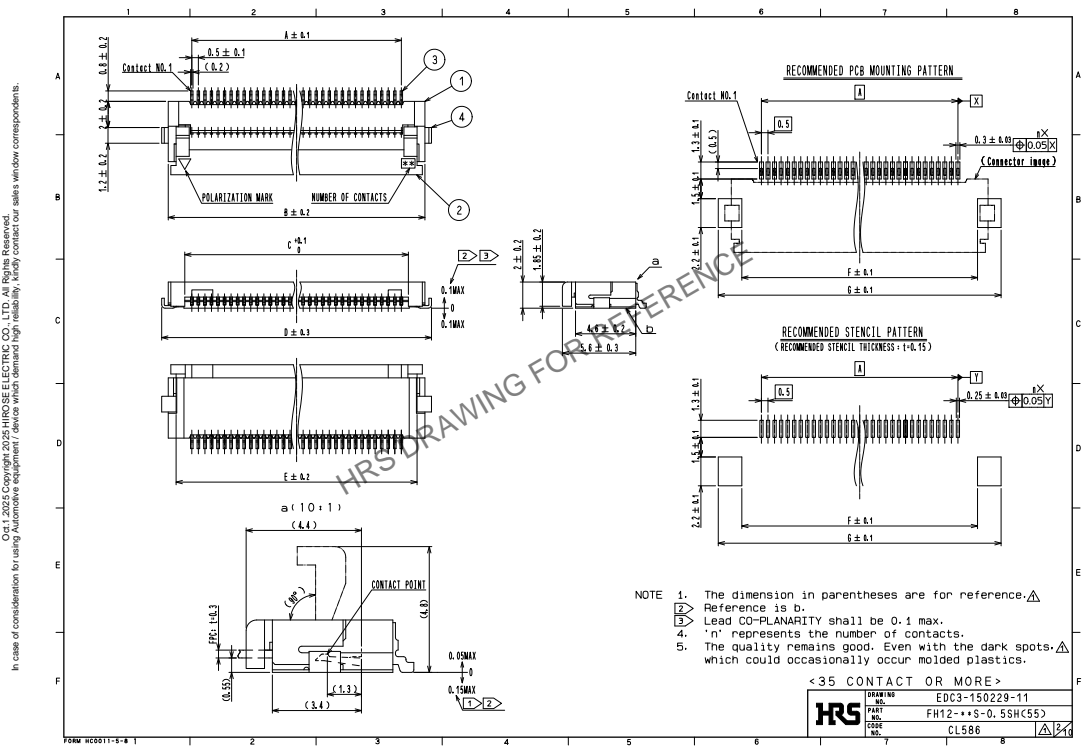
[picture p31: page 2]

HRS DRAWING FOR REFERENCE

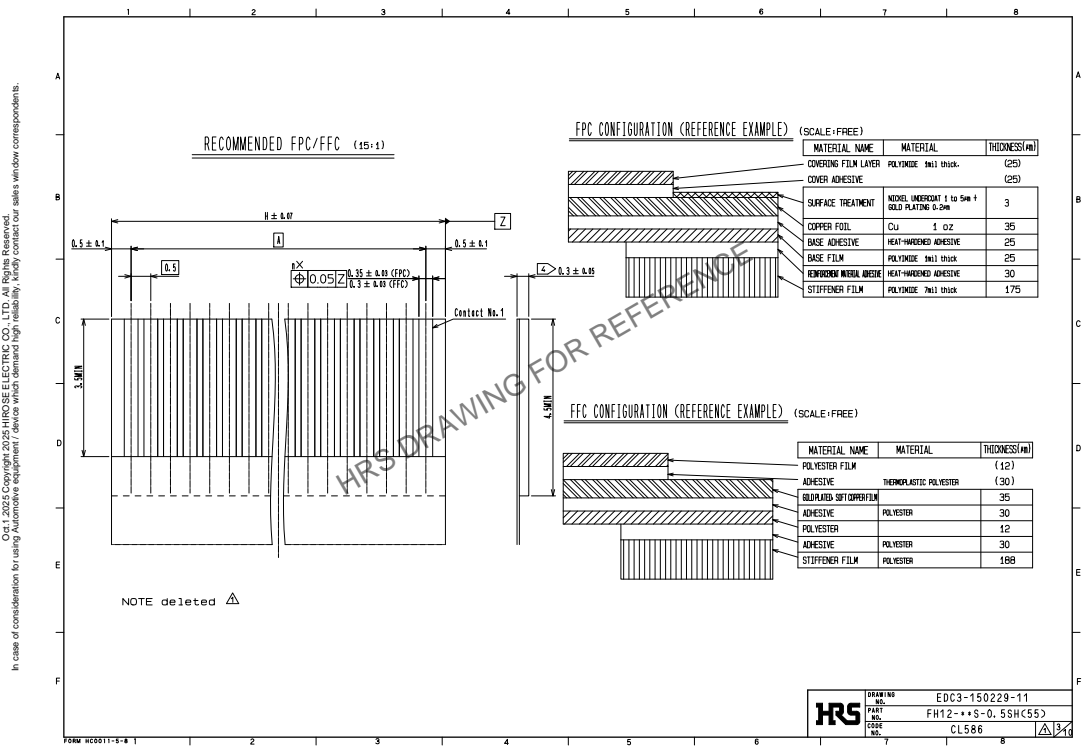
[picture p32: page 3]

HRS DRAWING FOR REFERENCE

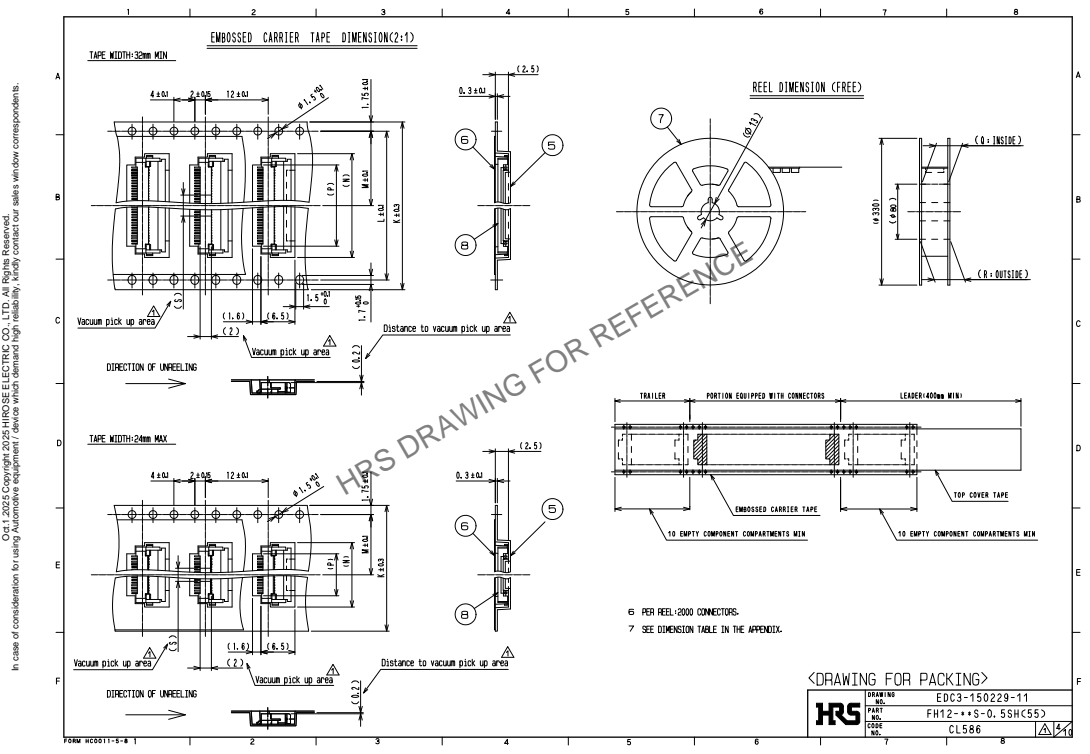
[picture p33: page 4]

HRS DRAWING FOR REFERENCE

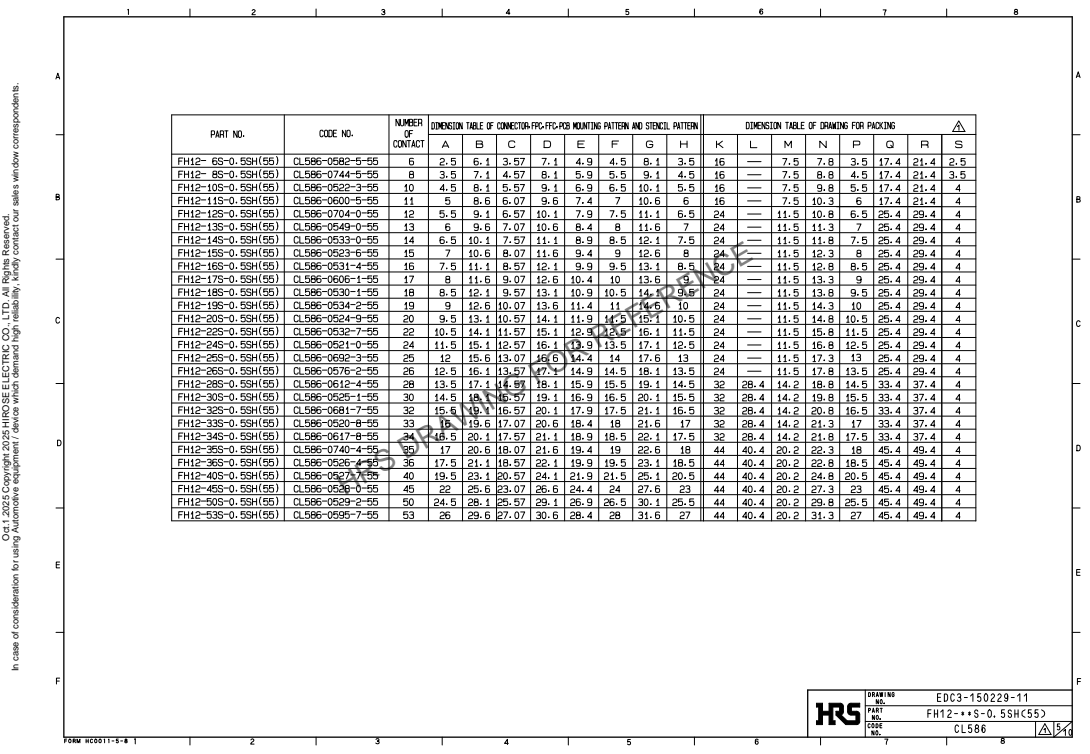
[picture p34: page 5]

HRS DRAWING FOR REFERENCE

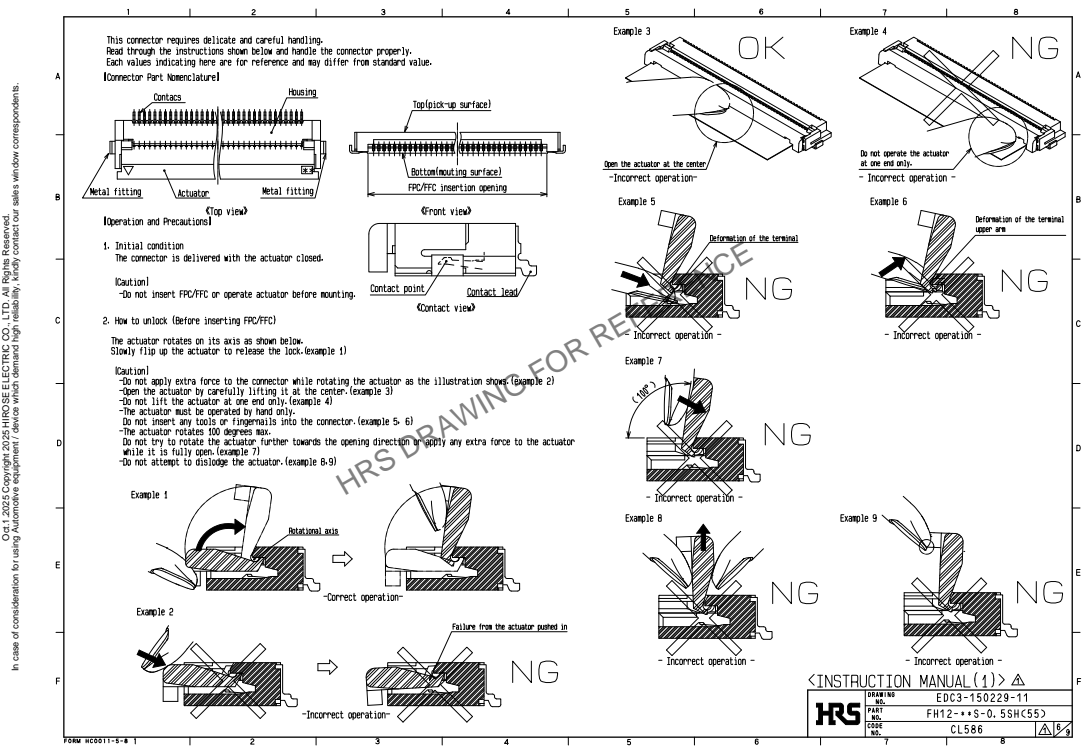
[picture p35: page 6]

HRS DRAWING FOR REFERENCE

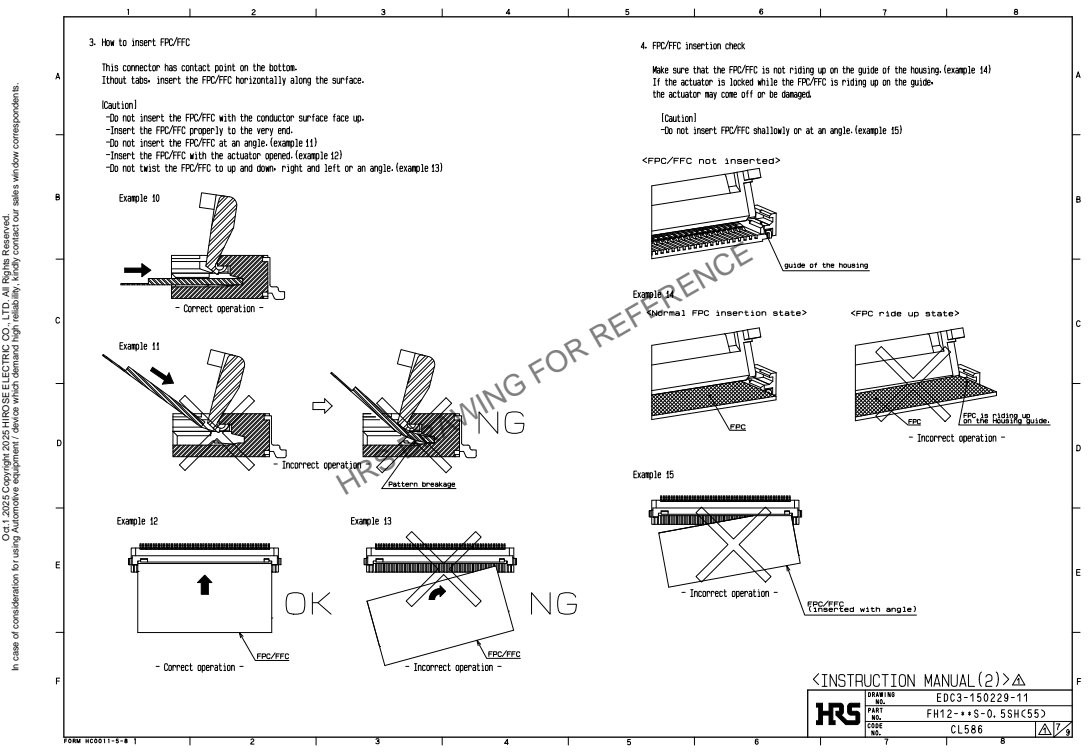
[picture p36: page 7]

HRS DRAWING FOR REFERENCE

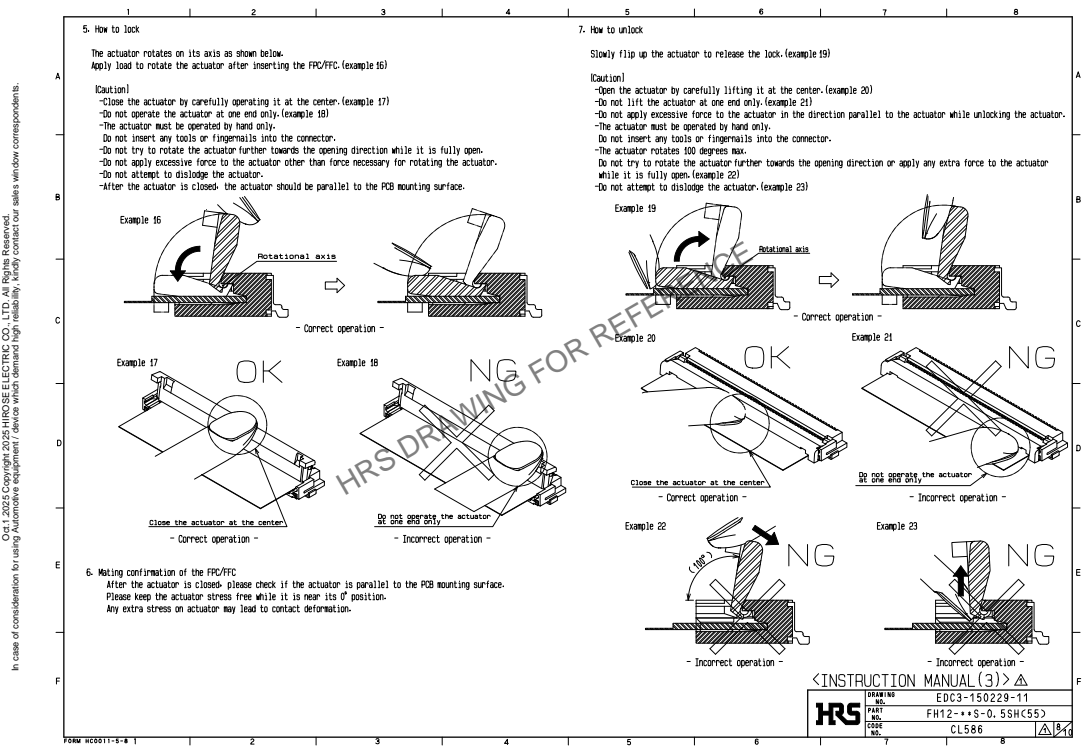
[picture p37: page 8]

HRS DRAWING FOR REFERENCE


HRS DRAWING FOR REFERENCE


HRS DRAWING FOR REFERENCE

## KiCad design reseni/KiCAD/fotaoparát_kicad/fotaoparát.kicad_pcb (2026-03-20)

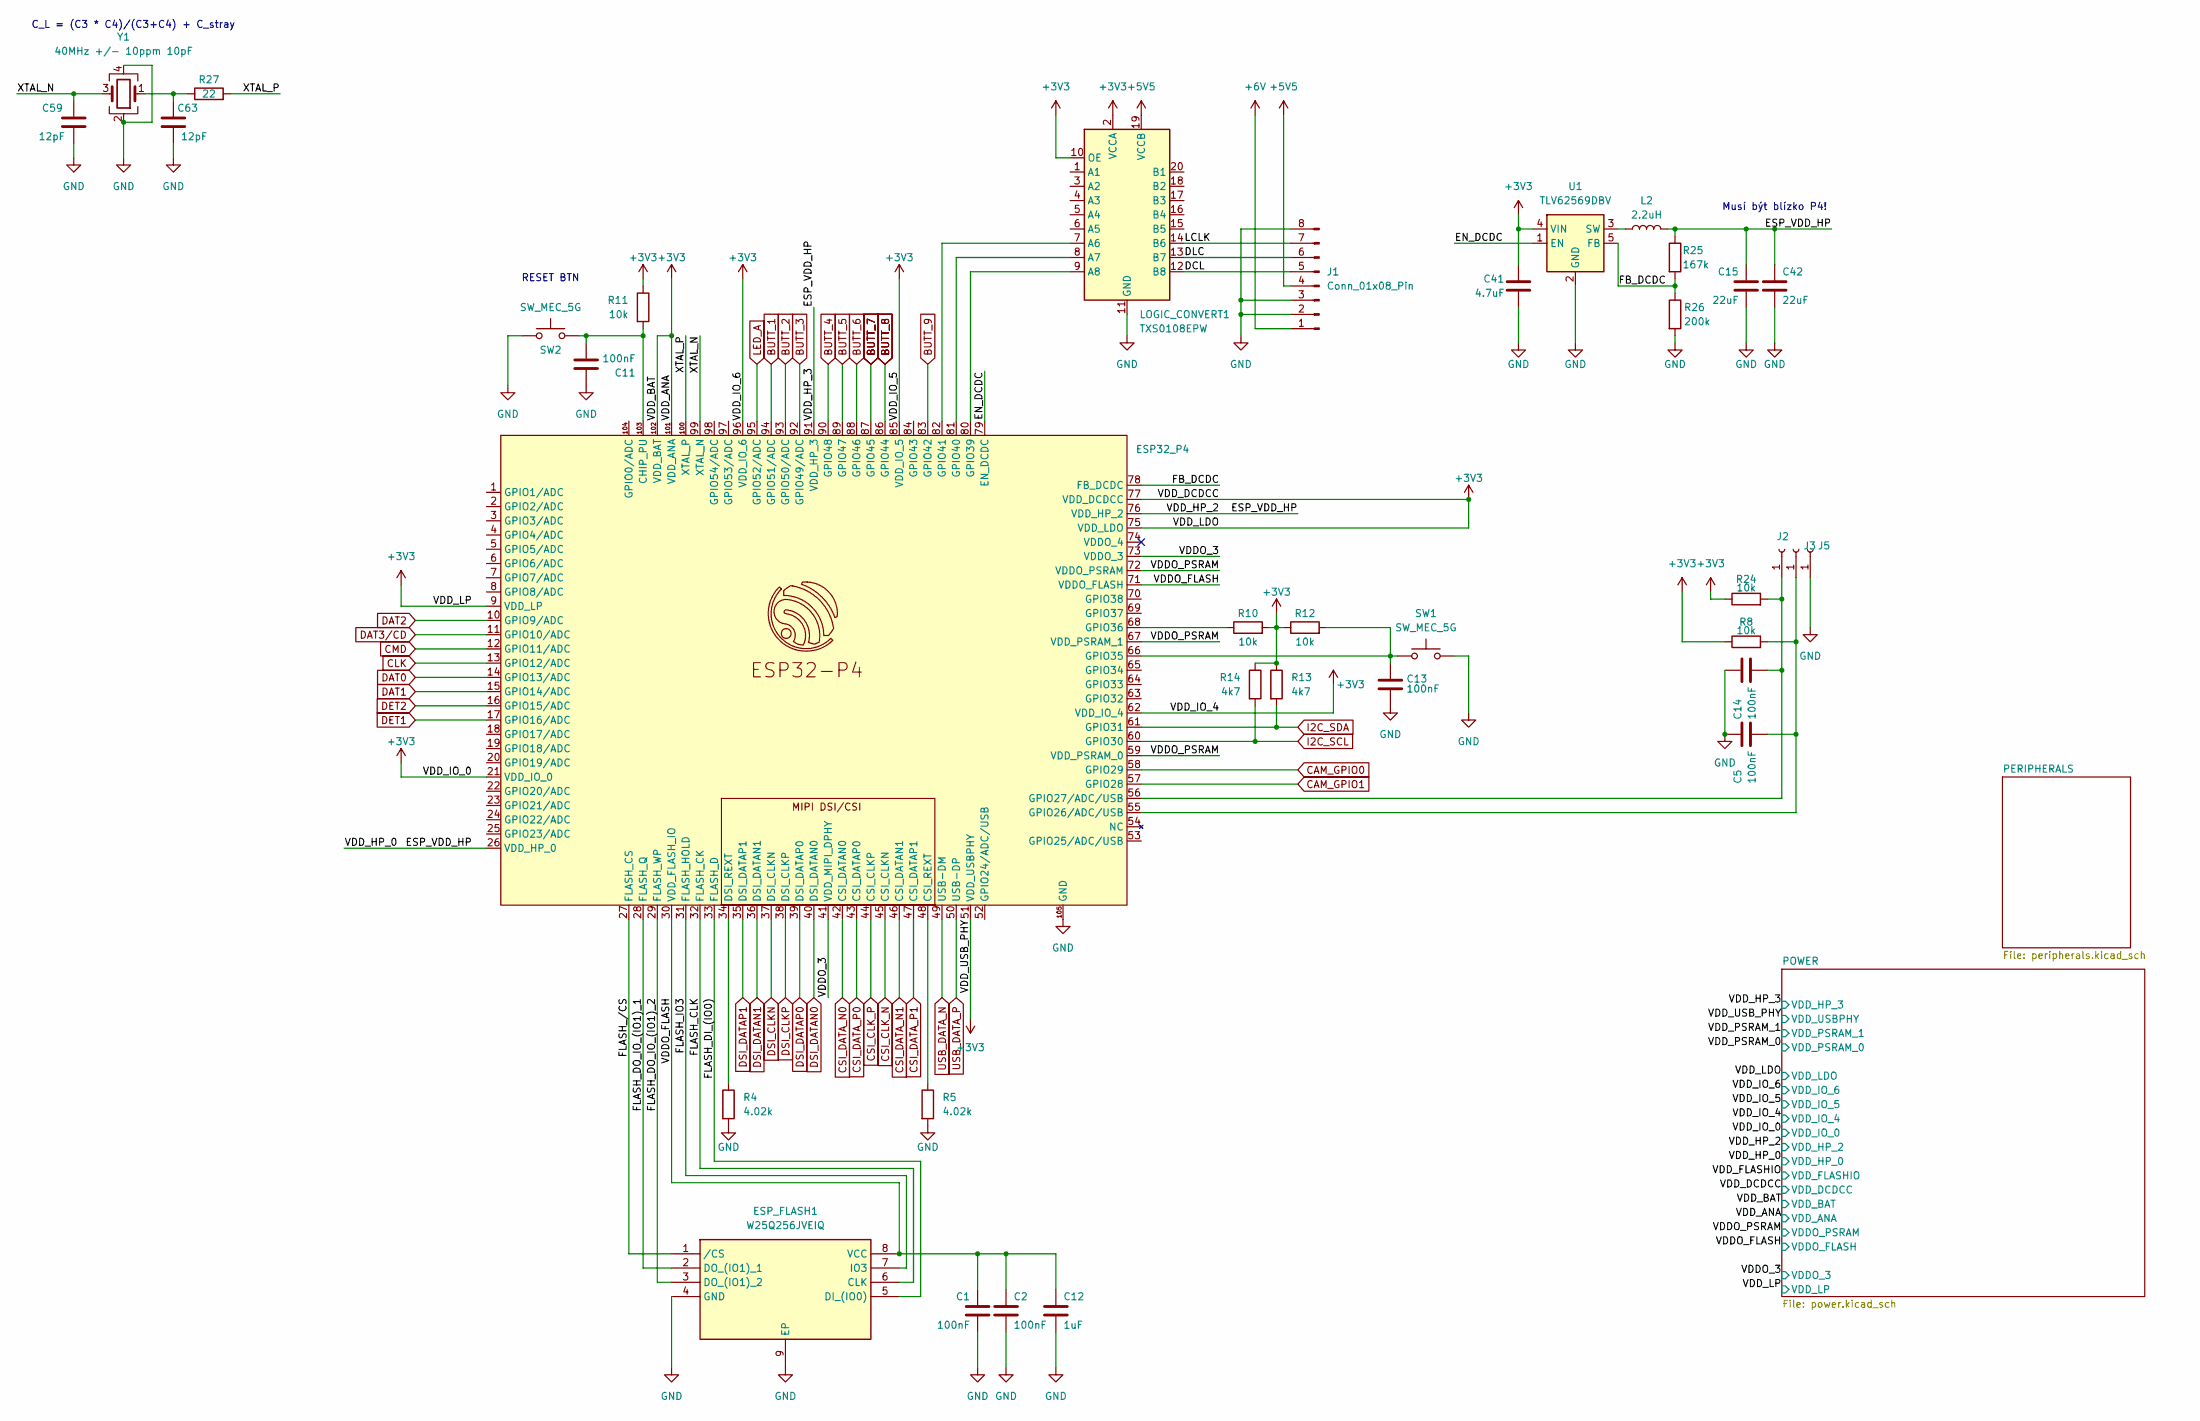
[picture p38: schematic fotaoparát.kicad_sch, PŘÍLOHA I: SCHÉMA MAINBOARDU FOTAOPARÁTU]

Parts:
C1, C2, C5, C11, C13, C14: 100nF; C_0201_0603Metric
C12: 1uF; C_0201_0603Metric
C15, C42: 22uF; C_0603_1608Metric
C41: 4.7uF; L_0603_1608Metric
C59, C63: 12pF; C_0402_1005Metric; LCSC Part C1547
ESP32_P4: ESP32_P4; ESP32-P4
ESP_FLASH1: W25Q256JVEIQ; SON127P800X600X80-9N-D; Mouser Part Number 454-W25Q256JVEIQ
J1: Conn_01x08_Pin; Amphenol_F32Q-1A7x1-11008_1x08-1MP_P0.5mm_Horizontal
J2, J3, J5: Conn_01x01_Socket; SolderWirePad_1x01_SMD_1.5x3mm
L2: 2.2uH; L_0603_1608Metric
LOGIC_CONVERT1: TXS0108EPW; TSSOP-20_4.4x6.5mm_P0.65mm
R4, R5: 4.02k; R_0603_1608Metric
R8, R10, R11, R12, R24: 10k; R_0603_1608Metric
R13, R14: 4k7; R_0603_1608Metric
R25: 167k; R_0603_1608Metric
R26: 200k; R_0603_1608Metric
R27: 22; R_0402_1005Metric; LCSC Part C25092
SW1, SW2: SW_MEC_5G; SW_Push_1P1T_NO_CK_KMR2
U1: TLV62569DBV; SOT-23-5
Y1: 40MHz +/- 10ppm 10pF; Crystal_SMD_2016-4Pin_2.0x1.6mm; LCSC Part C255898

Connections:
+3V3: C41.1, ESP32_P4.9 (VDD_LP), ESP32_P4.21 (VDD_IO_0), ESP32_P4.51 (VDD_USBPHY), ESP32_P4.62 (VDD_IO_4), ESP32_P4.75 (VDD_LDO), ESP32_P4.77 (VDD_DCDCC), ESP32_P4.85 (VDD_IO_5), ESP32_P4.96 (VDD_IO_6), ESP32_P4.101 (VDD_ANA), ESP32_P4.102 (VDD_BAT), LOGIC_CONVERT1.2 (VCCA), LOGIC_CONVERT1.10 (OE), R8.1, R10.2, R11.1, R12.1, R13.1, R14.1, R24.1, U1.4 (VIN); also elsewhere on the board
+5V5: J1.4, LOGIC_CONVERT1.19 (VCCB); also elsewhere on the board
+6V: J1.1; also elsewhere on the board
/DCL: J1.5, LOGIC_CONVERT1.12 (B8)
/DLC: J1.6, LOGIC_CONVERT1.13 (B7)
/ESP_VDD_HP: C15.1, C42.1, ESP32_P4.26 (VDD_HP_0), ESP32_P4.76 (VDD_HP_2), ESP32_P4.91 (VDD_HP_3), L2.2, R25.1; also elsewhere on the board
/FLASH_CLK: ESP32_P4.32 (FLASH_CK), ESP_FLASH1.6 (CLK)
/FLASH_DI_(IO0): ESP32_P4.33 (FLASH_D), ESP_FLASH1.5 (DI_(IO0))
/FLASH_DO_IO_(IO1)_1: ESP32_P4.28 (FLASH_Q), ESP_FLASH1.2 (DO_(IO1)_1)
/FLASH_DO_IO_(IO1)_2: ESP32_P4.29 (FLASH_WP), ESP_FLASH1.3 (DO_(IO1)_2)
/FLASH_IO3: ESP32_P4.31 (FLASH_HOLD), ESP_FLASH1.7 (IO3)
/FLASH_/CS: ESP32_P4.27 (FLASH_CS), ESP_FLASH1.1 (/CS)
/LCLK: J1.7, LOGIC_CONVERT1.14 (B6)
/USB_DATA_N: ESP32_P4.49 (USB-DM)
/USB_DATA_P: ESP32_P4.50 (USB-DP)
/VDDO_3: ESP32_P4.41 (VDD_MIPI_DPHY), ESP32_P4.73 (VDDO_3); also elsewhere on the board
/VDDO_FLASH: C1.2, C2.2, C12.2, ESP32_P4.30 (VDD_FLASH_IO), ESP32_P4.71 (VDDO_FLASH), ESP_FLASH1.8 (VCC); also elsewhere on the board
/VDDO_PSRAM: ESP32_P4.59 (VDD_PSRAM_0), ESP32_P4.67 (VDD_PSRAM_1), ESP32_P4.72 (VDDO_PSRAM); also elsewhere on the board
BUTT_1: ESP32_P4.94 (GPIO51/ADC); also elsewhere on the board
BUTT_2: ESP32_P4.93 (GPIO50/ADC); also elsewhere on the board
BUTT_3: ESP32_P4.92 (GPIO49/ADC); also elsewhere on the board
BUTT_4: ESP32_P4.90 (GPIO48); also elsewhere on the board
BUTT_5: ESP32_P4.89 (GPIO47); also elsewhere on the board
BUTT_6: ESP32_P4.88 (GPIO46); also elsewhere on the board
BUTT_7: ESP32_P4.87 (GPIO45); also elsewhere on the board
BUTT_8: ESP32_P4.86 (GPIO44); also elsewhere on the board
BUTT_9: ESP32_P4.83 (GPIO42); also elsewhere on the board
CAM_GPIO0: ESP32_P4.58 (GPIO29); also elsewhere on the board
CAM_GPIO1: ESP32_P4.57 (GPIO28); also elsewhere on the board
CLK: ESP32_P4.13 (GPIO12/ADC); also elsewhere on the board
CMD: ESP32_P4.12 (GPIO11/ADC); also elsewhere on the board
CSI_CLK_N: ESP32_P4.45 (CSI_CLKN); also elsewhere on the board
CSI_CLK_P: ESP32_P4.44 (CSI_CLKP); also elsewhere on the board
CSI_DATA_N0: ESP32_P4.42 (CSI_DATAN0); also elsewhere on the board
CSI_DATA_N1: ESP32_P4.46 (CSI_DATAN1); also elsewhere on the board
CSI_DATA_P0: ESP32_P4.43 (CSI_DATAP0); also elsewhere on the board
CSI_DATA_P1: ESP32_P4.47 (CSI_DATAP1); also elsewhere on the board
DAT0: ESP32_P4.14 (GPIO13/ADC); also elsewhere on the board
DAT1: ESP32_P4.15 (GPIO14/ADC); also elsewhere on the board
DAT2: ESP32_P4.10 (GPIO9/ADC); also elsewhere on the board
DAT3/CD: ESP32_P4.11 (GPIO10/ADC); also elsewhere on the board
DET1: ESP32_P4.17 (GPIO16/ADC); also elsewhere on the board
DET2: ESP32_P4.16 (GPIO15/ADC); also elsewhere on the board
DSI_CLKN: ESP32_P4.37 (DSI_CLKN); also elsewhere on the board
DSI_CLKP: ESP32_P4.38 (DSI_CLKP); also elsewhere on the board
DSI_DATAN0: ESP32_P4.40 (DSI_DATAN0); also elsewhere on the board
DSI_DATAN1: ESP32_P4.36 (DSI_DATAN1); also elsewhere on the board
DSI_DATAP0: ESP32_P4.39 (DSI_DATAP0); also elsewhere on the board
DSI_DATAP1: ESP32_P4.35 (DSI_DATAP1); also elsewhere on the board
I2C_SDA: ESP32_P4.61 (GPIO31), R13.2; also elsewhere on the board
LED_A: ESP32_P4.95 (GPIO52/ADC); also elsewhere on the board
unnamed: C63.1, R27.1, Y1.1
unnamed: ESP32_P4.48 (CSI_REXT), R5.1
unnamed: ESP32_P4.34 (DSI_REXT), R4.1
unnamed: ESP32_P4.79 (EN_DCDC), U1.1 (EN)
unnamed: C14.2, ESP32_P4.56 (GPIO27/ADC/USB), J2.1, R24.2
unnamed: ESP32_P4.68 (GPIO36), R10.1
unnamed: ESP32_P4.80 (GPIO39), LOGIC_CONVERT1.9 (A8)
unnamed: ESP32_P4.81 (GPIO40), LOGIC_CONVERT1.8 (A7)
unnamed: ESP32_P4.82 (GPIO41), LOGIC_CONVERT1.7 (A6)
unnamed 75: C59.1, ESP32_P4.99 (XTAL_N), Y1.3; also elsewhere on the board
unnamed 76: ESP32_P4.100 (XTAL_P), R27.2; also elsewhere on the board
unnamed: ESP32_P4.78 (FB_DCDC), R25.2, R26.1, U1.5 (FB)
unnamed: L2.1, U1.3 (SW)

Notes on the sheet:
C_L = (C3 * C4)/(C3+C4) + C_stray
RESET BTN
Musí být blízko P4!

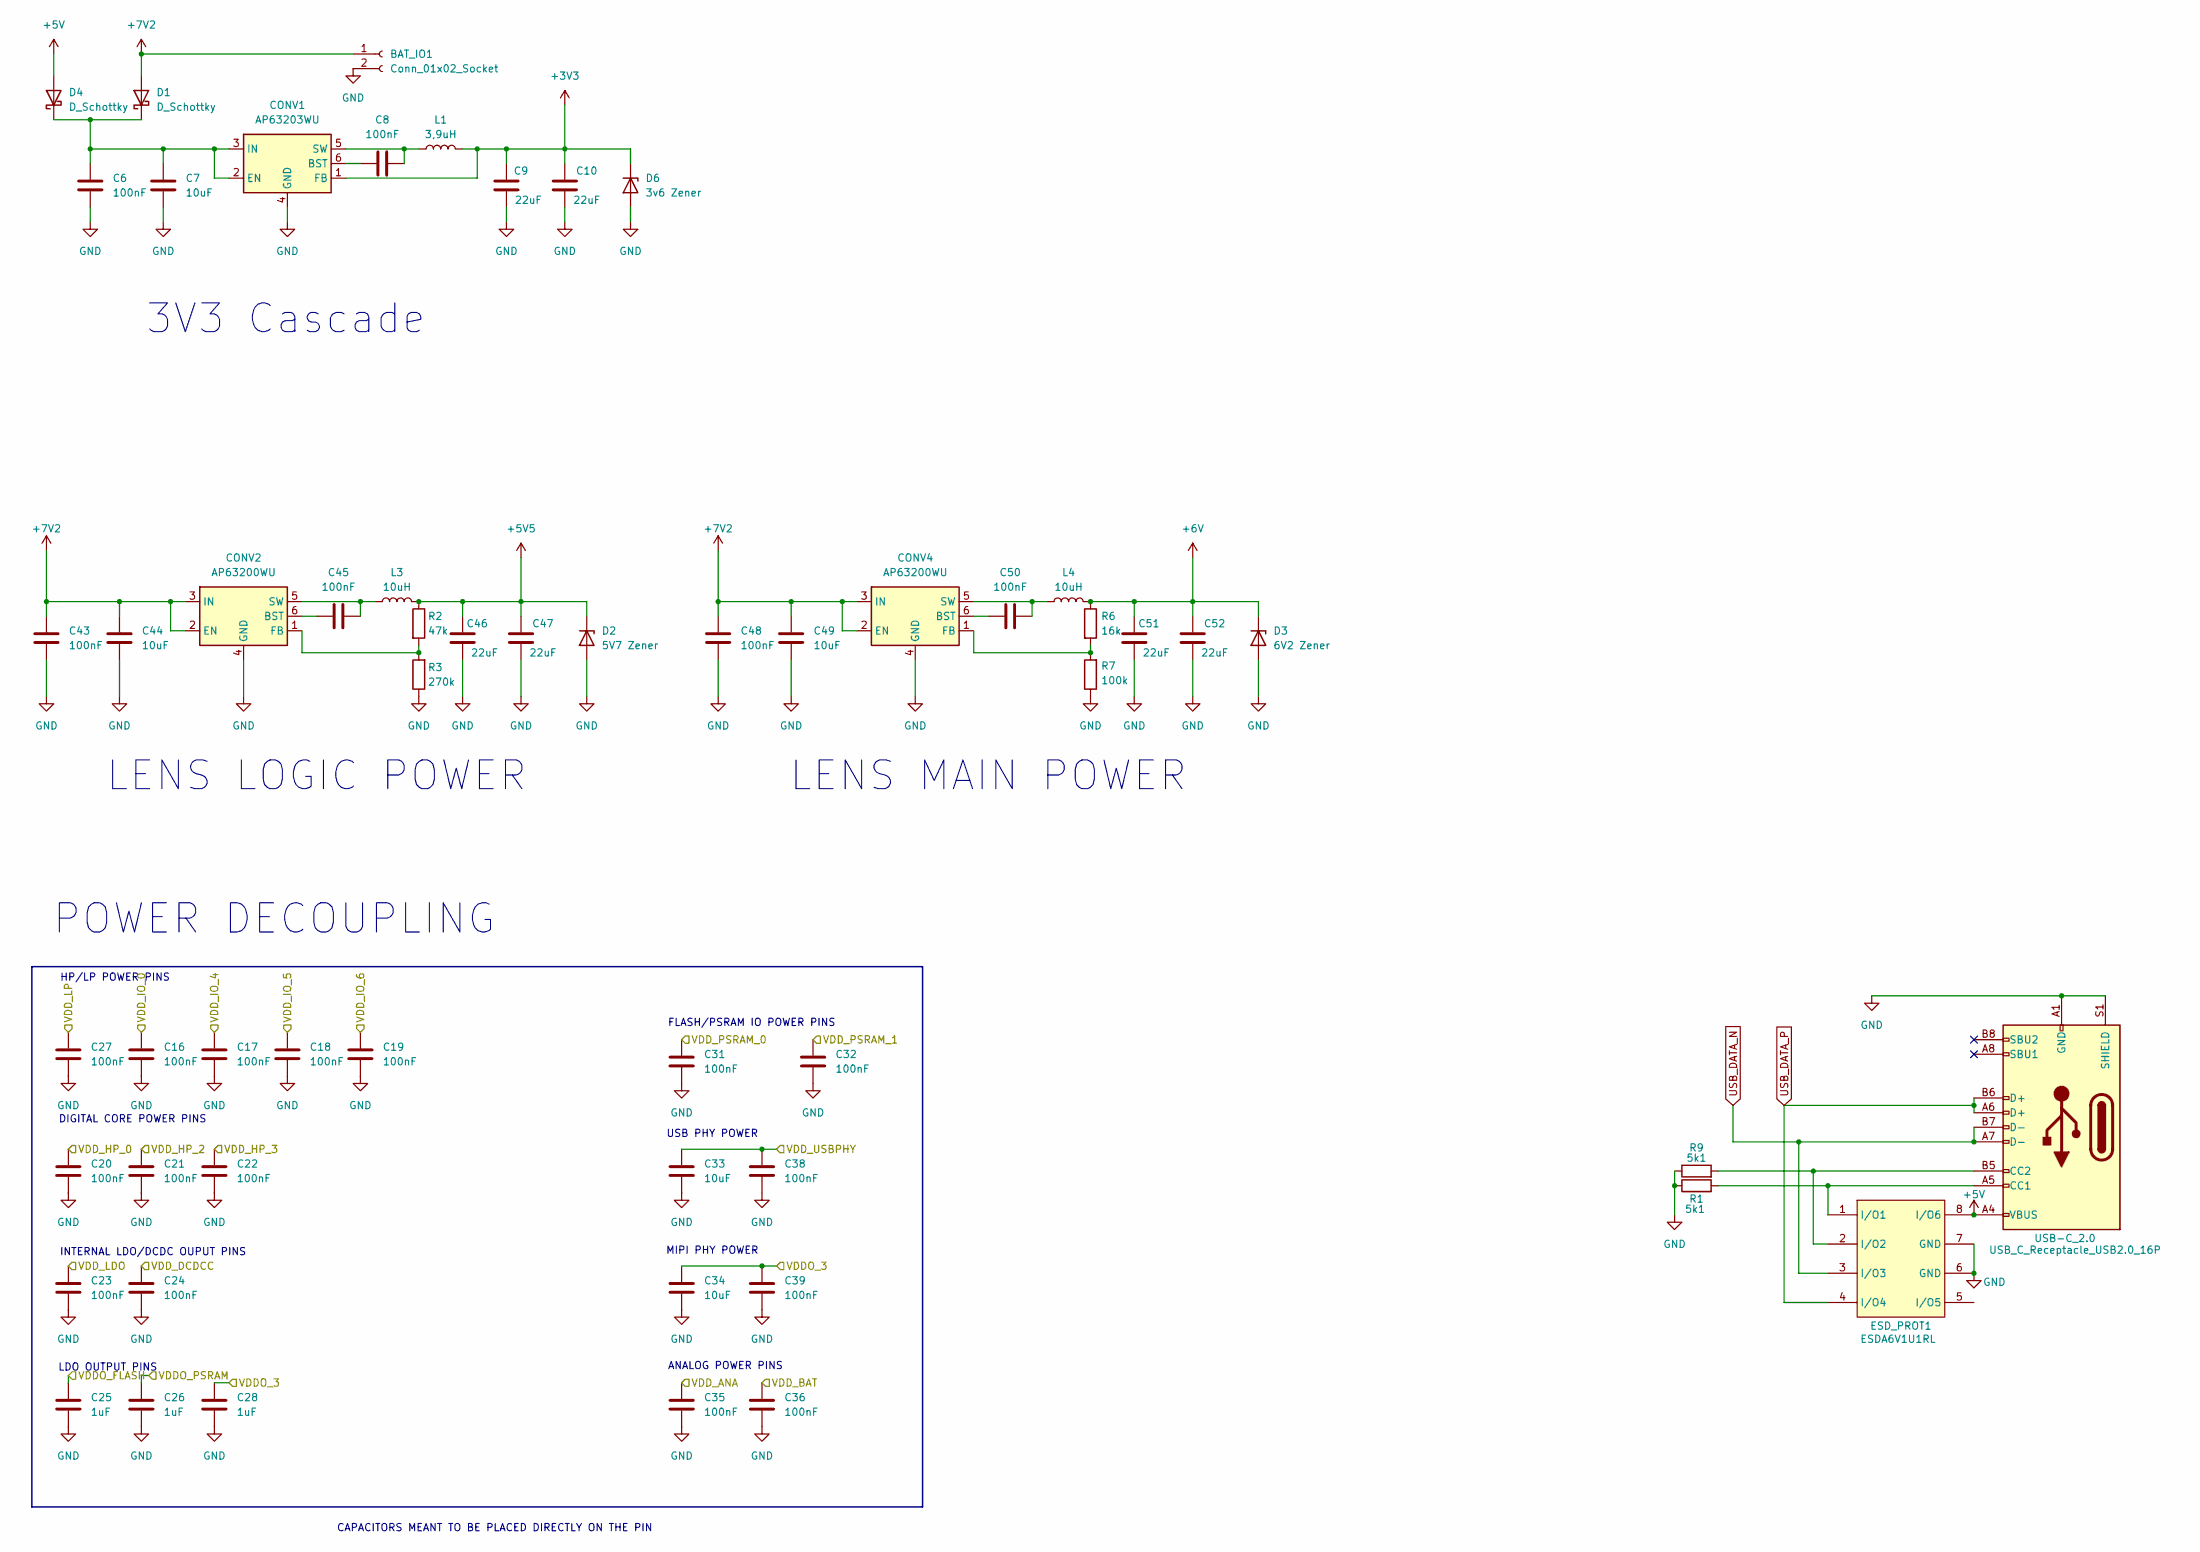
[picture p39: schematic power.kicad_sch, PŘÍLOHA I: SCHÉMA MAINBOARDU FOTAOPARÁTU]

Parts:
BAT_IO1: Conn_01x02_Socket; SolderWire-1.5sqmm_1x02_P6mm_D1.7mm_OD3mm
C6, C8, C43, C45, C48, C50: 100nF; C_0603_1608Metric; LCSC C14663
C7, C44, C49: 10uF; C_0603_1608Metric; LCSC C19702
C9, C10, C46, C47, C51, C52: 22uF; C_0603_1608Metric; LCSC C59461
C16, C17, C18, C19, C20, C21, C22, C23, C24, C27, C31, C32, C35, C36, C38, C39: 100nF; C_0201_0603Metric
C25, C26, C28: 1uF; C_0201_0603Metric
C33, C34: 10uF; C_0201_0603Metric
CONV1: AP63203WU; TSOT-23-6; LCSC C780769
CONV2, CONV4: AP63200WU; TSOT-23-6
D1, D4: D_Schottky; D_0805_2012Metric
D2: 5V7 Zener; D_SOD-123; LCSC Part C66886
D3: 6V2 Zener; D_SOD-123; LCSC Part C66886
D6: 3v6 Zener; D_SOD-123; LCSC Part C66886
ESD_PROT1: ESDA6V1U1RL; SO-8_L4.9-W3.9-P1.27-LS5.9-BL; LCSC Part C118278
L1: 3,9uH; L_0603_1608Metric; LCSC C915148
L3, L4: 10uH; L_0603_1608Metric; LCSC C915148
R1, R9: 5k1; R_0603_1608Metric
R2: 47k; R_0603_1608Metric
R3: 270k; R_0603_1608Metric
R6: 16k; R_0603_1608Metric
R7: 100k; R_0603_1608Metric
USB-C_2.0: USB_C_Receptacle_USB2.0_16P; USB_C_Receptacle_Palconn_UTC16-G

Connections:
+3V3: C9.2, C10.2, C16.1, C17.1, C18.1, C19.1, C23.1, C24.1, C27.1, C33.1, C35.1, C36.1, C38.1, CONV1.1 (FB), D6.1 (K), L1.2; also elsewhere on the board
+5V: D4.2 (A), ESD_PROT1.8 (I/O6), USB-C_2.0.A4 (VBUS), USB-C_2.0.A9 (VBUS), USB-C_2.0.B4 (VBUS), USB-C_2.0.B9 (VBUS)
+5V5: C46.2, C47.2, D2.1 (K), L3.2, R2.1; also elsewhere on the board
+6V: C51.2, C52.2, D3.1 (K), L4.2, R6.1; also elsewhere on the board
+7V2: BAT_IO1.1, C43.2, C44.2, C48.2, C49.2, CONV2.2 (EN), CONV2.3 (IN), CONV4.2 (EN), CONV4.3 (IN), D1.2 (A); also elsewhere on the board
/ESP_VDD_HP: C20.1, C21.1, C22.1; also elsewhere on the board
/VDDO_3: C28.1, C34.1, C39.1; also elsewhere on the board
/VDDO_FLASH: C25.1; also elsewhere on the board
/VDDO_PSRAM: C26.1; also elsewhere on the board
/VDD_PSRAM_0: C31.1
/VDD_PSRAM_1: C32.1
unnamed: C8.1, CONV1.6 (BST)
unnamed: C6.2, C7.2, CONV1.2 (EN), CONV1.3 (IN), D1.1 (K), D4.1 (K)
unnamed: C8.2, CONV1.5 (SW), L1.1
unnamed: C45.1, CONV2.6 (BST)
unnamed: CONV2.1 (FB), R2.2, R3.2
unnamed: C45.2, CONV2.5 (SW), L3.1
unnamed: C50.1, CONV4.6 (BST)
unnamed: CONV4.1 (FB), R6.2, R7.2
unnamed: C50.2, CONV4.5 (SW), L4.1
unnamed: ESD_PROT1.1 (I/O1), R1.2, USB-C_2.0.A5 (CC1)
unnamed: ESD_PROT1.2 (I/O2), R9.2, USB-C_2.0.B5 (CC2)
USB_DATA_N: ESD_PROT1.3 (I/O3), USB-C_2.0.A7 (D-), USB-C_2.0.B7 (D-)
USB_DATA_P: ESD_PROT1.4 (I/O4), USB-C_2.0.A6 (D+), USB-C_2.0.B6 (D+)

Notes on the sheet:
CAPACITORS MEANT TO BE PLACED DIRECTLY ON THE PIN
LENS LOGIC POWER
FLASH/PSRAM IO POWER PINS
USB PHY POWER
DIGITAL CORE POWER PINS
MIPI PHY POWER
POWER DECOUPLING
HP/LP POWER PINS
LDO OUTPUT PINS
ANALOG POWER PINS
INTERNAL LDO/DCDC OUPUT PINS
3V3 Cascade
LENS MAIN POWER

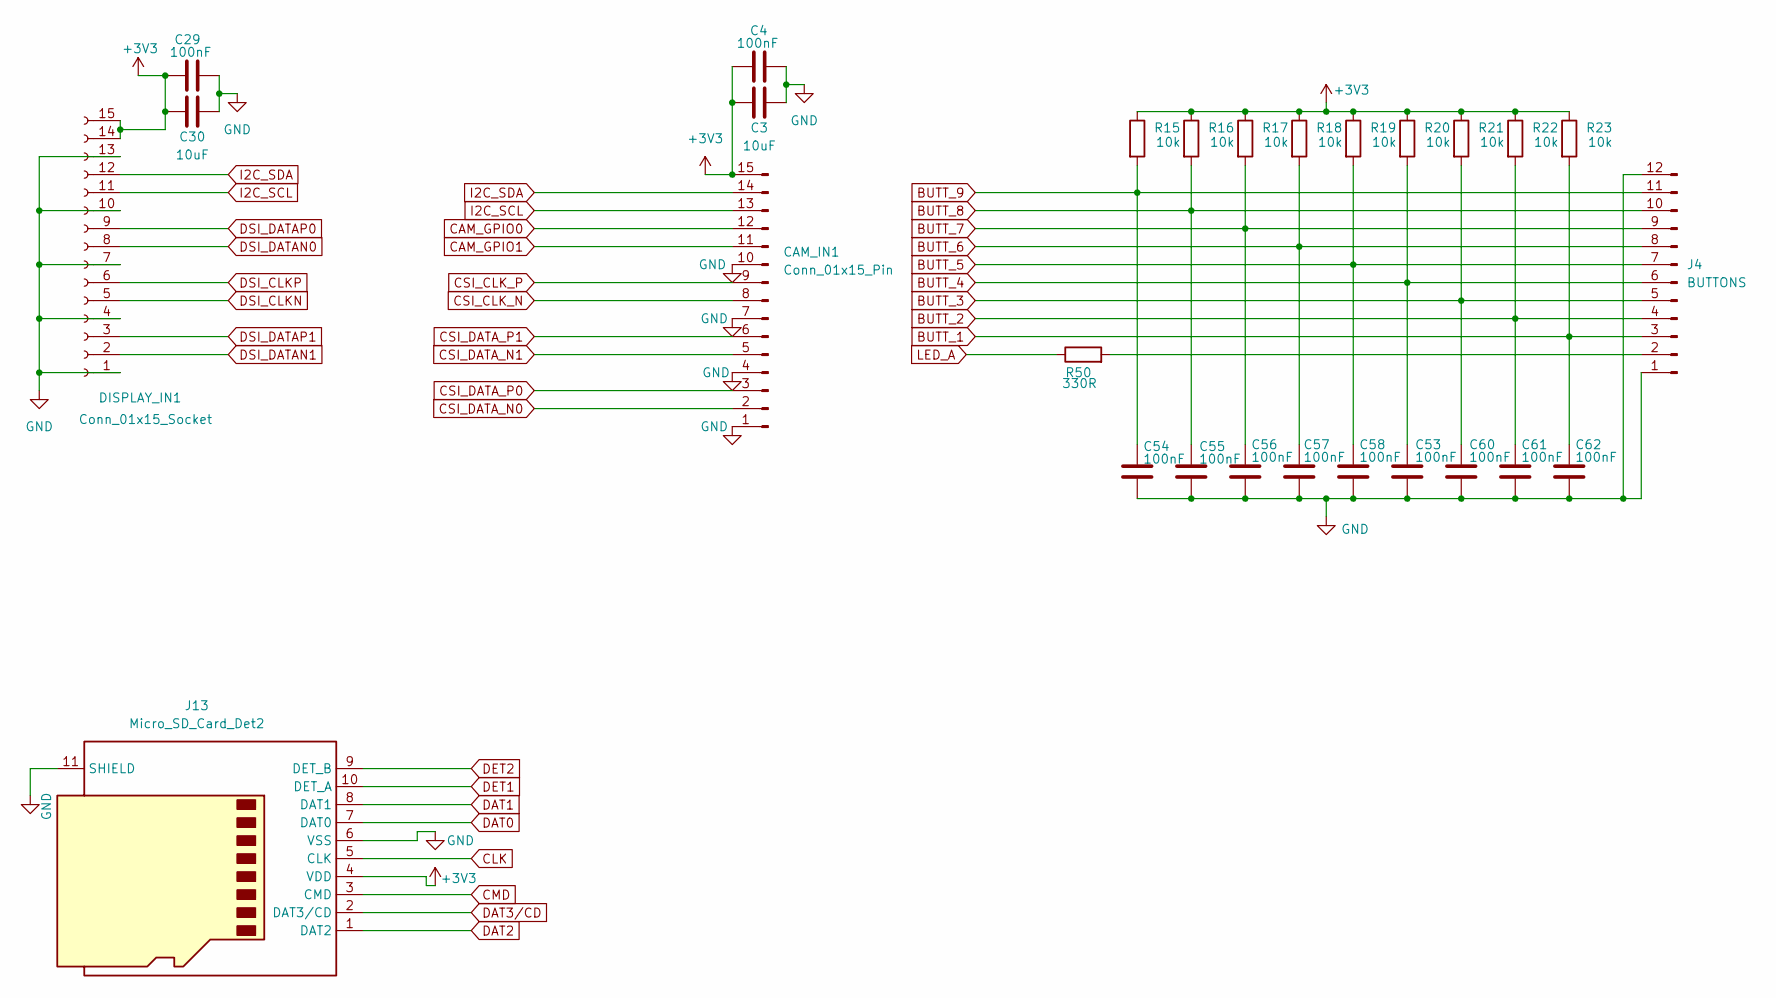
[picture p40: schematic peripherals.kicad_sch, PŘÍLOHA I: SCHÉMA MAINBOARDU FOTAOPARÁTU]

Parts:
C3, C30: 10uF; C_0201_0603Metric
C4, C29, C53, C54, C55, C56, C57, C58, C60, C61, C62: 100nF; C_0201_0603Metric
CAM_IN1: Conn_01x15_Pin; Hirose_FH12-15S-0.5SH_1x15-1MP_P0.50mm_Horizontal
DISPLAY_IN1: Conn_01x15_Socket; Hirose_FH12-15S-0.5SH_1x15-1MP_P0.50mm_Horizontal
J4: BUTTONS; Hirose_FH12-12S-0.5SH_1x12-1MP_P0.50mm_Horizontal
J13: Micro_SD_Card_Det2; microSD_HC_Hirose_DM3BT-DSF-PEJS
R15, R16, R17, R18, R19, R20, R21, R22, R23: 10k; R_0603_1608Metric
R50: 330R; R_0603_1608Metric

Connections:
+3V3: C3.1, C4.1, C29.1, C30.1, CAM_IN1.15, DISPLAY_IN1.14, DISPLAY_IN1.15, J13.4 (VDD), R15.1, R16.1, R17.1, R18.1, R19.1, R20.1, R21.1, R22.1, R23.1; also elsewhere on the board
BUTT_1: C62.1, J4.3, R23.2; also elsewhere on the board
BUTT_2: C61.1, J4.4, R22.2; also elsewhere on the board
BUTT_3: C60.1, J4.5, R21.2; also elsewhere on the board
BUTT_4: C53.1, J4.6, R20.2; also elsewhere on the board
BUTT_5: C58.1, J4.7, R19.2; also elsewhere on the board
BUTT_6: C57.1, J4.8, R18.2; also elsewhere on the board
BUTT_7: C56.1, J4.9, R17.2; also elsewhere on the board
BUTT_8: C55.1, J4.10, R16.2; also elsewhere on the board
BUTT_9: C54.1, J4.11, R15.2; also elsewhere on the board
CAM_GPIO0: CAM_IN1.12; also elsewhere on the board
CAM_GPIO1: CAM_IN1.11; also elsewhere on the board
CLK: J13.5 (CLK); also elsewhere on the board
CMD: J13.3 (CMD); also elsewhere on the board
CSI_CLK_N: CAM_IN1.8; also elsewhere on the board
CSI_CLK_P: CAM_IN1.9; also elsewhere on the board
CSI_DATA_N0: CAM_IN1.2; also elsewhere on the board
CSI_DATA_N1: CAM_IN1.5; also elsewhere on the board
CSI_DATA_P0: CAM_IN1.3; also elsewhere on the board
CSI_DATA_P1: CAM_IN1.6; also elsewhere on the board
DAT0: J13.7 (DAT0); also elsewhere on the board
DAT1: J13.8 (DAT1); also elsewhere on the board
DAT2: J13.1 (DAT2); also elsewhere on the board
DAT3/CD: J13.2 (DAT3/CD); also elsewhere on the board
DET1: J13.10 (DET_A); also elsewhere on the board
DET2: J13.9 (DET_B); also elsewhere on the board
DSI_CLKN: DISPLAY_IN1.5; also elsewhere on the board
DSI_CLKP: DISPLAY_IN1.6; also elsewhere on the board
DSI_DATAN0: DISPLAY_IN1.8; also elsewhere on the board
DSI_DATAN1: DISPLAY_IN1.2; also elsewhere on the board
DSI_DATAP0: DISPLAY_IN1.9; also elsewhere on the board
DSI_DATAP1: DISPLAY_IN1.3; also elsewhere on the board
I2C_SDA: CAM_IN1.14, DISPLAY_IN1.12; also elsewhere on the board
LED_A: R50.1; also elsewhere on the board
unnamed: J4.2, R50.2

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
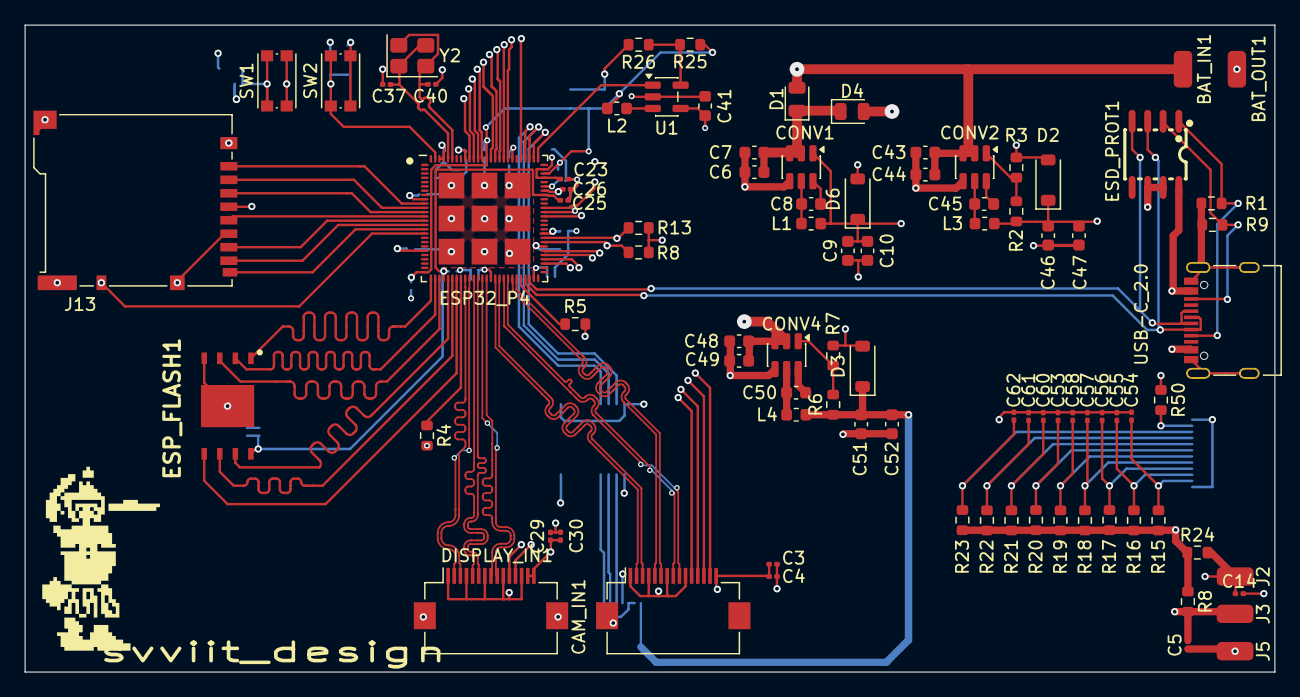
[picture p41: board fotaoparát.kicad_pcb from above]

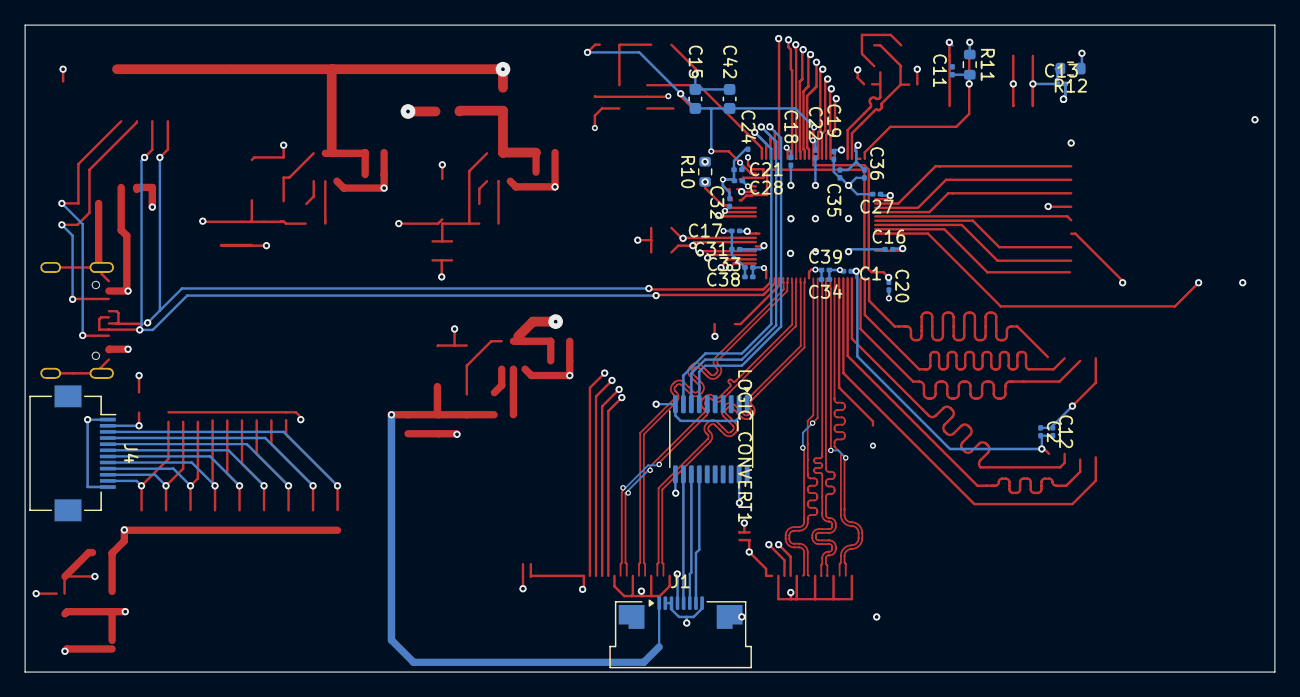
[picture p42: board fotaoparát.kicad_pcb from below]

Board: 4 copper layers, 102.0 x 52.8 mm, 120 parts (31 on the bottom side), 82 nets.

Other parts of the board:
BAT_IN1: Conn_01x01_Socket; SolderWirePad_1x01_SMD_1.5x3mm
BAT_OUT1: Conn_01x01_Socket; SolderWirePad_1x01_SMD_1.5x3mm
C37, C40: 10pF; C_0201_0603Metric
R8#2: 10k; R_0603_1608Metric
Y2: Crystal_GND24; Crystal_SMD_Abracon_ABM8G-4Pin_3.2x2.5mm
svviit_design: LOGO

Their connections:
+3V3: R8#2.1; also elsewhere on the board
+7V2: BAT_IN1.1; also elsewhere on the board
unnamed 75: C40.1, Y2.2, Y2.4; also elsewhere on the board
unnamed 76: C37.2, Y2.1, Y2.3; also elsewhere on the board

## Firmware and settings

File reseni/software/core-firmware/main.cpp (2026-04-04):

#include <chrono>
#include <iostream>
#include <optional>
#include <string>
#include <thread>
#include <vector>

namespace camera_project {

enum class Mode {
    Preview,
    Menu,
    Capture,
    Playback,
    Sleep,
    Error,
};

struct Settings {
    int iso = 200;
    double aperture = 2.8;
    int shutterSpeedUs = 10000;
    bool liveViewEnabled = true;
};

struct Frame {
    int width = 0;
    int height = 0;
    std::vector<unsigned char> data;
};

class Camera {
public:
    bool initialize() {
        std::cout << "[camera] initialize\n";
        return true;
    }

    std::optional<Frame> captureFrame() {
        std::cout << "[camera] capture frame\n";
        Frame frame;
        frame.width = 640;
        frame.height = 480;
        frame.data.resize(static_cast<std::size_t>(frame.width * frame.height));
        return frame;
    }
};

class Display {
public:
    bool initialize() {
        std::cout << "[display] initialize\n";
        return true;
    }

    void showStatus(const std::string& text) {
        std::cout << "[display] " << text << '\n';
    }

    void showFrame(const Frame& frame) {
        std::cout << "[display] show frame " << frame.width << "x" << frame.height << '\n';
    }
};

class Storage {
public:
    bool initialize() {
        std::cout << "[storage] initialize\n";
        return true;
    }

    bool saveFrame(const Frame& frame, const std::string& fileName) {
        std::cout << "[storage] save " << fileName << " (" << frame.width << "x" << frame.height << ")\n";
        return true;
    }
};

class EfMount {
public:
    bool initialize() {
        std::cout << "[ef] initialize\n";
        return true;
    }

    bool applySettings(const Settings& settings) {
        std::cout << "[ef] iso=" << settings.iso
                  << " aperture=" << settings.aperture
                  << " shutter_us=" << settings.shutterSpeedUs << '\n';
        return true;
    }
};

class PowerManager {
public:
    void enterSleep() {
        std::cout << "[power] sleep\n";
    }
};

class CoreFirmware {
public:
    bool initialize() {
        if (!camera_.initialize()) return false;
        if (!display_.initialize()) return false;
        if (!storage_.initialize()) return false;
        if (!efMount_.initialize()) return false;

        display_.showStatus("Core firmware ready");
        return true;
    }

    void runDemoLoop() {
        display_.showStatus("preview mode");
        for (int iteration = 0; iteration < 3; ++iteration) {
            tick();
        }

        settings_.iso = 400;
        settings_.shutterSpeedUs = 8000;
        efMount_.applySettings(settings_);

        mode_ = Mode::Capture;
        capturePhoto();

        mode_ = Mode::Sleep;
        power_.enterSleep();
    }

private:
    void tick() {
        if (mode_ != Mode::Preview || !settings_.liveViewEnabled) {
            return;
        }

        auto frame = camera_.captureFrame();
        if (frame.has_value()) {
            display_.showFrame(*frame);
        }
    }

    void capturePhoto() {
        auto frame = camera_.captureFrame();
        if (!frame.has_value()) {
            mode_ = Mode::Error;
            display_.showStatus("capture failed");
            return;
        }

        if (storage_.saveFrame(*frame, "IMG_0001.raw")) {
            display_.showStatus("photo saved");
            mode_ = Mode::Preview;
        } else {
            mode_ = Mode::Error;
            display_.showStatus("save failed");
        }
    }

    Mode mode_ = Mode::Preview;
    Settings settings_{};
    Camera camera_{};
    Display display_{};
    Storage storage_{};
    EfMount efMount_{};
    PowerManager power_{};
};

}  // namespace camera_project

int main() {
    camera_project::CoreFirmware firmware;
    if (!firmware.initialize()) {
        std::cerr << "Core firmware init failed\n";
        return 1;
    }

    firmware.runDemoLoop();
    return 0;
}

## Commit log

2025-11-30 Oprava adresare
    [fotaoparát.kicad_pcb, fotaoparát.kicad_sch]
2025-12-08 prejmenovani pro lepsi orientaci (jsem delulu)
    [fotaoparát.kicad_pcb, fotaoparát.kicad_sch]
2025-12-11 Pridani PCB, s a lcd + datasheety
2025-12-13 nevim, neco tu vadi
    [fotaoparát.kicad_pcb, fotaoparát.kicad_sch]
2025-12-17 Mirne nakresove zmeny
    [fotaoparát.kicad_pcb, fotaoparát.kicad_sch]
2025-12-18 PCB routing 22pin na kameru
    [fotaoparát.kicad_sch]
2025-12-21 Uprava pcb, finalni predelani (snad) kamery
    [fotaoparát.kicad_pcb, fotaoparát.kicad_sch]
2025-12-22 Zvyseni prehlednosti schametu
    [fotaoparát.kicad_pcb, fotaoparát.kicad_sch]
2026-01-09 Udelal jsem znovu sd kartovy dock, tentokrat je spravne orientovany to same s konktorem na display
    [fotaoparát.kicad_pcb, fotaoparát.kicad_sch, telo1.ipt]
2026-01-09 Upraveni routingu pro zlepseni kvality signalu
    musim predelat cely konktor na display
    [fotaoparát.kicad_pcb, fotaoparát.kicad_sch]
2026-01-17 Tech zmen je tolik ze ani nevim co napsat Rerouting v podstate vseho, znovu predelani displaye, flash, sd kartoveho holderu
    [fotaoparát.kicad_pcb, fotaoparát.kicad_sch]
2026-01-23 Add lens_logic.py for interfacing with Canon EF lens using ESP32
2026-01-23 delani pullups
    [fotaoparát.kicad_sch]
2026-01-23 ai pomoc (citace a program na optiku)
    [fotaoparát.kicad_pcb]
2026-01-24 delal jsem pullups
    [fotaoparát.kicad_sch]
2026-01-25 Udelani USB-C konektoru, reset a flash tlacitek
    [fotaoparát.kicad_pcb, fotaoparát.kicad_sch]
2026-01-28 Update display and camera module links in soupis.txt
2026-01-28 Delal jsem znova flash, predelal jsem usb-c konektor a display konektor
    [CameraBodySplit-telo_back.step, fotaoparát.kicad_pcb, fotaoparát.kicad_sch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]
2026-01-28 nejake nesrovnalosti
    [fotaoparát.kicad_pcb]
2026-01-30 optimalizace routingu, oprava chyb, pridani baterky do soupisu mimo pcb
    [batt-dcdc.kicad_sch, fotaoparát.kicad_pcb, fotaoparát.kicad_sch]
2026-01-30 Vymena displaye za mensi
    [PCB_Dummy.ipt]
2026-02-01 Predelani 80 % routingu pro optimalizaci mista na desce, a predelani napajeni do 7,2V akumulatoru.
    [fotaoparát.kicad_pcb, fotaoparát.kicad_sch]
2026-02-01 vice optimalizace
    [fotaoparát.kicad_pcb, fotaoparát.kicad_sch]
2026-02-02 bla bla bla decoupling
    [fotaoparát.kicad_pcb, fotaoparát.kicad_sch]
2026-02-05 Rerouting CSI/DSI rozhrani
    [fotaoparát.kicad_pcb, fotaoparát.kicad_sch, peripherals.kicad_sch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]
2026-02-05 NEvim co to je za bordel ale modlim se
    [peripherals.kicad_sch, power.kicad_sch]
2026-02-05 mirne korekce
    [fotaoparát.kicad_pcb, fotaoparát.kicad_sch, peripherals.kicad_sch]
2026-02-10 Pridani krystalu
    [buttons.kicad_pcb, buttons.kicad_sch, fotaoparát.kicad_pcb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]
2026-02-11 Delani delani, dalsi pcb vytvari ztracim svou mysl
    [talcitka_deska.kicad_pcb, talcitka_deska.kicad_sch]
2026-02-19 Předělání powerrials, přidání malého pcb na spousť foťáku
    [buttons.kicad_pcb, buttons.kicad_sch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]
2026-02-19 Neco se tam rozjelo, i2c korekce
    [fotaoparát.kicad_pcb, fotaoparát.kicad_sch, power.kicad_sch]
2026-02-22 Pridani konektoru pro tlacitka na schema
    [fotaoparát.kicad_sch, peripherals.kicad_sch, power.kicad_sch]
2026-02-23 Update readme with Canon 550D pinout and LED info
    Added details about the Canon 550D button pinout and LED status indicators.
2026-02-23 XDD NEVIM ZABIJU SE
    [fotaoparát.kicad_pcb, fotaoparát.kicad_sch, power.kicad_sch]
2026-02-23 Udelal jsem pullupy na tlacitka z fotaku
    [fotaoparát.kicad_pcb, fotaoparát.kicad_sch, peripherals.kicad_sch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]
2026-02-28 Pridani asi poloviny lscs cisel
    [fotaoparát.kicad_sch, peripherals.kicad_sch, power.kicad_sch]
2026-03-01 PRidani (skoro) vsech lscs cisel, krystal je spatne ale pcb mam doma udelane jeste jinak, takze pridam a preroutuju pozdeji.
    [fotaoparát.kicad_pcb, fotaoparát.kicad_sch, peripherals.kicad_sch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]
2026-03-04 FInalni doteky. Ted uz jenom opravy {snad}
    [fotaoparát.csv, fotaoparát.kicad_pcb, fotaoparát.kicad_sch]
2026-03-16 Udelal jsem: -Predelani labelu na global -Pridani vyvodu na desku pro spoust -Pokusil se predelat ten stepdown, Vout by mela byt 1V1, nestihl jsem prepsat vsechny hodnoty a pridat lscs cisla
    [fotaoparát.kicad_pcb, fotaoparát.kicad_sch, peripherals.kicad_sch]
2026-03-17 Dodelani stepdownu, prirazeni lscs cisel
    [fotaoparát.kicad_pcb, fotaoparát.kicad_sch]
2026-03-20 nejaky maly zmeny asi
    [fotaoparát.kicad_pcb]
2026-03-25 [1/6] Úklid a opravy toho nejnutnějšího na hlavní straně schématu
    [fotaoparát.kicad_sch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]
2026-04-27 Přidal jsem dokumentaci, asi se mi git vykálí do obličeje při mergi, ale neva.
    Dostal jsem se k Flash paměti
    [fotaoparát.kicad_sch, peripherals.kicad_sch, power.kicad_sch]
2026-04-27 Jeste pridani buck popisu (snad)
2026-04-27 Update KiCad project and documentation
    [fotaoparát.kicad_sch]
2026-04-28 Zmeny na domacim pc
    [power.kicad_sch]
2026-04-29 Pridani teto vetve se "spravnym" formatovani adresaru
    [CameraBodySplit-telo_back.step, PCB_Dummy.ipt, batt-dcdc.kicad_sch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]
2026-04-29 uprava adresaru
    [batt-dcdc.kicad_sch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]
